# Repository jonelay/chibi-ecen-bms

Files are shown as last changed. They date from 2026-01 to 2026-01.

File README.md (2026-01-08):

# Chibi-ECEN-BMS: 7S Lithium-Ion Battery Management System

A 7-cell lithium-ion battery management system designed as a student project for EMEN 5830 (Fundamentals of Systems Engineering) at the University of Colorado Boulder in 2015.




<p align="center">
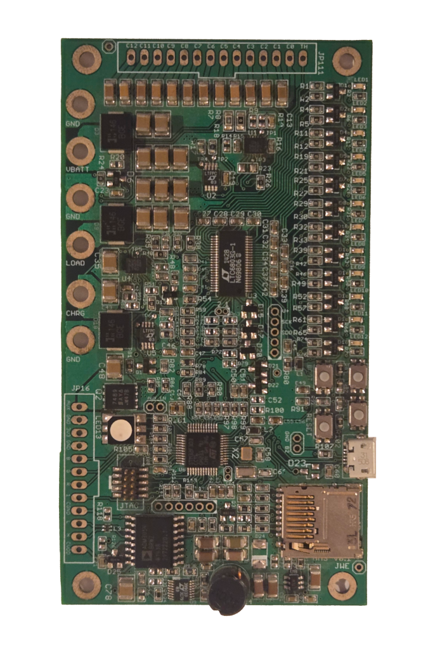
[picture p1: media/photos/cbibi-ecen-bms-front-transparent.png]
BMS PCB - Front
  
  &nbsp;&nbsp;&nbsp;
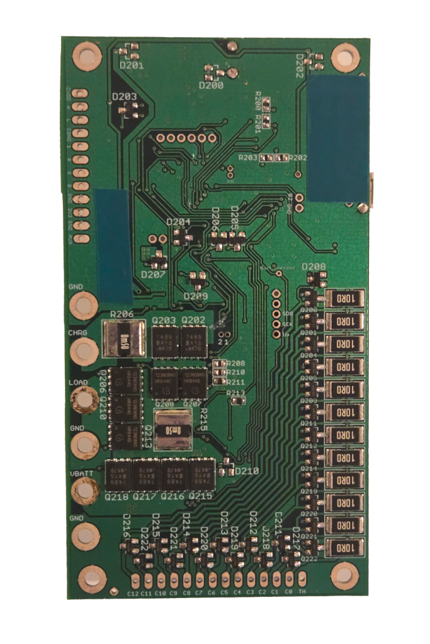
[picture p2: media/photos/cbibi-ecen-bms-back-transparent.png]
BMS PCB - Back
  
</p>

## Overview

This BMS was designed for an electric-assist recumbent tricycle with a focus on battery monitoring, safety, and data logging. The design used the ChibiOS operating system, and includes CAN bus communication, microSD data logging, and comprehensive fault detection.

⚠️ **Educational Prototype** - This was a graduate student learning project from 2015 focused on PCB layout techniques for power electronics. While the design is complete and boards were fabricated, this should be considered a learning exercise rather than a production-ready design. Firmware development was not released as part of the project.

## Key Features

- **7S Lithium-Ion Battery Monitoring** - LT6803-based cell voltage monitoring
- **STM32F303 Microcontroller** - ARM Cortex-M4 with floating-point unit
- **Safety Features** - Overcurrent, overvoltage, undervoltage, and thermal protection
- **CAN Bus Interface** - ADM3054 isolated CAN transceiver for vehicle communication
- **Data Logging** - microSD card storage for voltage, current, temperature data
- **Power Management** - LT3990 buck-boost converter for auxiliary power
- **Debug Interface** - JTAG programming and debugging support
- **User Feedback** - RGB status LED, two buttons for user input

## Technical Specifications

- **Battery Configuration**: 7S (7 cells in series)
- **Cell Chemistry**: 18650 Lithium-Ion (Samsung ICR18650-30B, 3000mAh)
- **Voltage Range**: 19.6V - 29.4V (2.8V - 4.2V per cell)
- **Microcontroller**: STM32F303CBT6 (ARM Cortex-M4, 48MHz, 128KB Flash)
- **Battery Monitor**: LT6803-1 (multicell battery stack monitor)
- **Communication**: CAN 2.0B, USB 2.0 (micro-B connector)
- **Data Logging**: microSD card (SPI interface)
- **PCB**: 4-layer board, approximately 100mm x 75mm

See [docs/specifications.md](docs/specifications.md) for complete specifications.

## Systems Engineering Process

This project followed a rigorous systems engineering methodology as taught in EMEN 5830:

1. **Requirements Development** - Stakeholder needs analysis, system requirements derivation
2. **Concept of Operations** - Use cases, operational scenarios, system interactions
3. **Functional Analysis** - 21 iterations of Functional Flow Block Diagrams (FFDB)
4. **Trade Studies** - Component selection based on cost, performance, availability
5. **Design** - Schematic capture, PCB layout, mechanical integration
6. **Testing** - Comprehensive test procedures and validation

The [analysis/](analysis/) directory contains the complete systems engineering documentation, including all 21 FFDB iterations showing the evolution of the design through failure mode analysis.

## Hardware Versions

### Version 1 (v01) - Manufactured & Tested
Version 1 was designed in February 2015, manufactured in March 2015, and tested as part of the course project. Complete gerber files, BOM, and test documentation are included.

- **Status**: Manufactured, assembled, and tested
- **Manufacturing Files**: Complete gerbers available in `hardware/bms-v01/gerbers/`
- **Documentation**: Full schematic, layout, BOM, and test results included

### Version 2 (v02) - Design Iteration
Version 2 was a design iteration that incorporated lessons learned from v01 testing, including corrections to the 8MHz crystal package and expanded AUX power traces. This version was never manufactured and the design files remain in the Eagle source directory.

## Repository Structure

```
chibi-ecen-bms/
├── hardware/              # Manufacturing-ready files (PDFs, gerbers, BOM)
│   └── bms-v01/          # Version 1 (manufactured)
├── design-source/         # Native design files
│   ├── eagle/            # Eagle CAD schematics and layouts
│   ├── cubemx/           # STM32 configuration files
│   └── mechanical/       # SolidWorks models and renders
├── docs/                  # Documentation
├── analysis/              # Systems engineering analysis
│   ├── requirements/     # Requirements documentation
│   ├── failure-analysis/ # FFDB diagrams (21 iterations)
│   ├── calculations/     # Battery and system calculations
│   ├── trade-studies/    # Component selection analysis
│   └── diagrams/         # System block diagrams
├── datasheets/           # Key component datasheets
├── media/                # Photos, renders, and presentation
└── testing/              # Test procedures and results
```

## Getting Started

### Manufacturing

To manufacture this board:

1. Review the [schematic](hardware/bms-v01/bms_v01_schematic.pdf) and [layout](hardware/bms-v01/bms_v01_layout.pdf)
2. Order PCBs using the [gerber files](hardware/bms-v01/gerbers/)
3. Order components from the [BOM](hardware/bms-v01/bms_v01_assembly_bom.csv)
4. Refer to the [test procedure](testing/test-procedure.pdf) for validation

### Modifying the Design

The source Eagle CAD files are in [design-source/eagle/](design-source/eagle/). The STM32 peripheral configuration can be modified using STM32CubeMX with the [.ioc file](design-source/cubemx/bms_v01.ioc).

## Documentation

- **[Specifications](docs/specifications.md)** - System requirements and performance specs
- **[Pinout](docs/pinout.md)** - Connector pinouts and signal definitions
- **[Hardware README](hardware/README.md)** - Manufacturing file details

## Known Issues

Version 1 has two known issues that were addressed in the v02 design:

1. **8MHz Crystal Package** - Incorrect footprint requires rework or substitution
2. **AUX Power Trace** - Undersized trace for auxiliary power distribution

Workarounds: The crystal issue can be resolved by hand-soldering the correct package or using an adapter. The power trace issue can be addressed by adding solder to thicken the trace or adding a parallel wire jumper.

## License

This project is released under the MIT License. See [LICENSE](LICENSE) for details.

Copyright (c) 2015 Jone Lay

You are free to use, modify, and distribute this design for any purpose, with attribution.

## Open Source Hardware

This project is open source hardware. The design files, manufacturing files, and documentation are freely available for educational and non-commercial use.

## Disclaimer

*This project is shared for educational purposes and as a portfolio piece. It was a graduate student project from 2015. While care was taken in the design and the hardware was successfully manufactured and tested, this is not a production-ready design. Use at your own risk. Battery management systems must be designed with extreme care for safety - this design is presented for educational purposes only.

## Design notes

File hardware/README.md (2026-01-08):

# Hardware Files

This directory contains manufacturing-ready files for the Chibi-ECEN-BMS hardware versions.

## Contents

### [bms-v01/](bms-v01/) - Version 1 (Manufactured & Tested)
Complete manufacturing files for Version 1, which was designed in February 2015, manufactured in March 2015, and successfully tested.

**Status**: ✓ Manufactured, ✓ Assembled, ✓ Tested

**Files**:
- `bms_v01_schematic.pdf` - 3-page schematic (battery monitoring, microcontroller, interfaces)
- `bms_v01_layout.pdf` - PCB layout (4-layer board, ~100mm x 75mm)
- `bms_v01_assembly_bom.csv` - Bill of materials with part numbers
- `gerbers/` - Complete gerber files for PCB manufacturing

**Manufacturing Specifications**:
- 4-layer PCB
- Dimensions: ~100mm x 75mm
- Thickness: 1.6mm
- Min trace/space: 6/6 mil
- Min drill: 0.3mm
- Finish: HASL or ENIG
- Solder mask: Green
- Silkscreen: White

## Manufacturing Information

### Hand Assembly

The v0.1 prototype boards were hand-assembled to save on cost and schedule.

**Assembly Considerations**:
- LT6803 is QFN package - requires good soldering skills or reflow oven
- STM32F303 is LQFP48 - manageable with fine-tip iron
- Most passives are 0603 size - tweezers and magnification helpful
- Stencil recommended for solder paste application

**Tools Needed**:
- Soldering iron with fine tip (Hakko FX-888D or similar)
- Hot air station (for QFN packages) or reflow oven
- Tweezers, flux, solder paste
- Multimeter for testing
- Oscilloscope for verification (recommended)

## Testing

After assembly, follow the test procedure in [../testing/test-procedure.pdf](../testing/test-procedure.pdf).

**Basic Tests**:
1. Visual inspection - Check for shorts, proper component placement
2. Power-on test - Verify 3.3V and 5V rails before connecting battery
3. Microcontroller test - Program and verify LED blink
4. LT6803 test - Verify cell voltage readings
5. CAN bus test - Verify communication with test device
6. microSD test - Verify file read/write

**Safety Warning**:
- Do not connect battery until power rails are verified correct
- Use current-limited power supply for initial testing
- Start with low voltage (e.g., 3S pack) before full 7S pack
- Monitor for smoke, heating, or unusual behavior

## Design Files

Native Eagle CAD design files are located in [../design-source/eagle/](../design-source/eagle/).

**Files**:
- `bms_v01.sch`, `bms_v01.brd` - Version 1 Eagle files
- `bms_v02.sch`, `bms_v02.brd` - Version 2 Eagle files

**Eagle Version**: Designed with Eagle 6.x or 7.x

## License

Hardware design files are released under the MIT License. See [../LICENSE](../LICENSE) for details.

---

**Disclaimer**: This is a student project from 2015. While care was taken in design and the hardware was successfully tested, use at your own risk. Battery management systems require careful design for safety.

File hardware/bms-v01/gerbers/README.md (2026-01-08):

# Gerber Files - BMS v01

This directory contains the complete set of Gerber files for manufacturing the Chibi-ECEN-BMS Version 1 PCB.

## File List

### Copper Layers
- `bms_v01.L1` - Top copper layer (signal + power)
- `bms_v01.L2` - Inner layer 1 (ground plane)
- `bms_v01.L3` - Inner layer 2 (power plane)
- `bms_v01.L4` - Bottom copper layer (signal + power)

### Solder Mask
- `bms_v01.smb` - Bottom solder mask
- `bms_v01.smt` - Top solder mask

### Silkscreen
- `bms_v01.slk` - Silkscreen (component designators, outlines)

### Solder Paste (for stencil)
- `bms_v01.bps` - Bottom paste (if needed)
- `bms_v01.tps` - Top paste (for SMD assembly)

### Drill Files
- `bms_v01.drl` - NC Drill file (Excellon format)
- `bms_v01.drd` - Drill drawing (documentation)
- `bms_v01.dri` - Drill rack information

### Mechanical
- `bms_v01.oln` - Board outline
- `bms_v01.gpi` - Gerber info file

### Additional Files
- `4LPlus-Sunstone.cam` - CAM job definition for 4-layer boards
- `excellon.cam` - Excellon drill file CAM definition

## PCB Specifications

### Board Parameters
- **Layers**: 4 (2 signal, 2 plane)
- **Dimensions**: ~100mm x 75mm (refer to outline layer)
- **Thickness**: 1.6mm (standard)
- **Material**: FR-4
- **Copper Weight**: 1 oz (35µm) on all layers

### Manufacturing Tolerances
- **Min Trace Width**: 6 mil (0.15mm)
- **Min Trace Spacing**: 6 mil (0.15mm)
- **Min Drill Size**: 0.3mm (12 mil)
- **Min Annular Ring**: 4 mil (0.1mm)

### Finish Options
- **HASL** (Hot Air Solder Leveling) - Standard, low cost
- **ENIG** (Electroless Nickel Immersion Gold) - Preferred for fine-pitch components, flat surface

### Solder Mask
- **Color**: Green (standard) or your choice
- **Type**: LPI (Liquid Photo-Imageable)
- **Clearance**: Standard (typically 3 mil from copper)

### Silkscreen
- **Color**: White (standard)
- **Placement**: Top side only
- **Min Text Size**: 40 mil (1mm) recommended for readability

## Layer Stack-up

```
┌─────────────────────┐
│ Top Solder Mask     │
├─────────────────────┤
│ L1 - Top Copper     │ ← Signal traces, SMD pads
│   (1 oz / 35µm)     │
├─────────────────────┤
│ Prepreg             │
├─────────────────────┤
│ L2 - Ground Plane   │ ← Solid ground plane
│   (1 oz / 35µm)     │
├─────────────────────┤
│ Core                │
├─────────────────────┤
│ L3 - Power Plane    │ ← +3.3V, +5V, Battery+ planes
│   (1 oz / 35µm)     │
├─────────────────────┤
│ Prepreg             │
├─────────────────────┤
│ L4 - Bottom Copper  │ ← Signal traces, SMD pads
│   (1 oz / 35µm)     │
├─────────────────────┤
│ Bottom Solder Mask  │
└─────────────────────┘

Total thickness: 1.6mm
```

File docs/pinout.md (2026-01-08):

# BMS Connector Pinouts

This document describes the external connector pinouts for the Chibi-ECEN-BMS. Refer to the [schematic](../hardware/bms-v01/bms_v01_schematic.pdf) for complete signal details.

## Main Battery Connector

**Connector Type**: Screw terminal or wire-to-board

| Pin | Signal | Description |
|-----|---|---|
| 1 | BATT- | Battery negative (cell 1 negative) |
| 2 | CELL1+ | Cell 1 positive / Cell 2 negative |
| 3 | CELL2+ | Cell 2 positive / Cell 3 negative |
| 4 | CELL3+ | Cell 3 positive / Cell 4 negative |
| 5 | CELL4+ | Cell 4 positive / Cell 5 negative |
| 6 | CELL5+ | Cell 5 positive / Cell 6 negative |
| 7 | CELL6+ | Cell 6 positive / Cell 7 negative |
| 8 | BATT+ | Battery positive (cell 7 positive) |

**Voltage Levels**: 19.6V - 29.4V (total pack voltage)

**Notes**:
- Each cell voltage is measured differentially by the LT6803
- RC filtering on each cell input for noise immunity
- Do not reverse polarity - no reverse polarity protection

## Charge Connector

| Pin | Signal | Description |
|-----|---|---|
| 1 | CHRG+ | Charger positive output |
| 2 | CHRG- | Charger negative (return to pack negative) |
| 3 | CHRG_SENSE | Charge current sense (optional) |
| 4 | CHRG_EN | Charge enable signal (output from BMS) |

**Voltage Levels**:
- CHRG+/CHRG-: 19.6V - 29.4V (matches pack voltage)
- CHRG_EN: 3.3V logic level (active high)
- CHRG_SENSE: 0-3.3V analog

**Notes**:
- CHRG_EN controls external charge FET or relay
- CHRG_SENSE is optional current measurement input
- Charge path must include external FET/relay controlled by CHRG_EN

## Load Connector

| Pin | Signal | Description |
|-----|---|---|
| 1 | LOAD+ | Load positive output |
| 2 | LOAD- | Load negative (return to pack negative) |
| 3 | LOAD_SENSE | Load current sense (optional) |
| 4 | LOAD_EN | Load enable signal (output from BMS) |

**Voltage Levels**:
- LOAD+/LOAD-: 19.6V - 29.4V (matches pack voltage)
- LOAD_EN: 3.3V logic level (active high)
- LOAD_SENSE: 0-3.3V analog

**Notes**:
- LOAD_EN controls external discharge FET or relay
- LOAD_SENSE is optional current measurement input
- Load path must include external FET/relay controlled by LOAD_EN

## CAN Bus Connector

**Connector Type**: Screw terminal or pin header

| Pin | Signal | Description |
|-----|---|---|
| 1 | CAN_H | CAN High |
| 2 | CAN_L | CAN Low |
| 3 | CAN_GND | CAN Ground (isolated) |
| 4 | CAN_PWR | CAN Power (5V, optional) |

**Voltage Levels**:
- CAN_H/CAN_L: CAN 2.0B differential signaling (recessive ~2.5V, dominant 3.5V/1.5V)
- CAN_PWR: 5V output, max 100mA

**Notes**:
- CAN transceiver is isolated (ADM3054)
- 120Ω termination resistor can be enabled via jumper or software
- Follow CAN bus wiring guidelines (twisted pair, proper termination)
- Maximum cable length depends on bit rate (40m @ 1Mbps, 1000m @ 50kbps)

## USB Connector

**Connector Type**: Micro-B USB receptacle

| Pin | Signal | Description |
|-----|---|---|
| 1 | VBUS | USB 5V power input |
| 2 | D- | USB Data negative |
| 3 | D+ | USB Data positive |
| 4 | ID | USB ID (not connected) |
| 5 | GND | USB Ground |

**Notes**:
- USB 2.0 Full Speed (12 Mbps)
- Appears as virtual COM port (CDC class)
- Can be powered from USB or battery (diode-OR)
- USB shield connected to GND through ferrite bead

## JTAG/SWD Debug Connector

**Connector Type**: 2x5 pin 0.05" (1.27mm) pitch header (ARM Cortex standard)

| Pin | Signal | Direction | Description |
|-----|---|---|---|
| 1 | VTREF | Input | Target reference voltage (3.3V) |
| 2 | SWDIO/TMS | I/O | Serial Wire Debug I/O / JTAG TMS |
| 3 | GND | - | Ground |
| 4 | SWCLK/TCK | Input | Serial Wire Clock / JTAG Clock |
| 5 | GND | - | Ground |
| 6 | SWO/TDO | Output | Serial Wire Output / JTAG Data Out |
| 7 | KEY | - | Key (no pin) |
| 8 | TDI | Input | JTAG Data In (SWD mode: not used) |
| 9 | GND | - | Ground |
| 10 | NRST | I/O | Reset (active low, open-drain) |

**Notes**:
- Compatible with ST-Link, J-Link, and other ARM debuggers
- SWD mode is preferred (only requires SWDIO, SWCLK, GND, VTREF, NRST)
- JTAG mode uses all signals for full debug capability
- Pull-up resistors on SWDIO, SWCLK, NRST

## User Interface

### Status LED

**Type**: Common-cathode RGB LED

| Pin | Signal | Description |
|-----|---|---|
| 1 | LED_R | Red channel (active high, current-limited) |
| 2 | LED_G | Green channel (active high, current-limited) |
| 3 | LED_B | Blue channel (active high, current-limited) |
| 4 | GND | Common cathode |

**Color Codes** (typical firmware implementation):
- **Green**: Normal operation
- **Blue**: Charging
- **Red**: Fault condition
- **Yellow** (Red+Green): Warning
- **Cyan** (Blue+Green): Discharging
- **Magenta** (Red+Blue): Initialization/bootloader
- **White** (all on): Test mode
- **Off**: Sleep/standby

### Buttons

| Button | Pin | Function |
|---|-----|---|
| BUTTON1 | PB10 | User button 1 (pulled high, active low) |
| BUTTON2 | PB11 | User button 2 (pulled high, active low) |

**Notes**:
- Debounced in firmware
- Can be used for manual fault reset, mode selection, etc.
- Exact function depends on firmware implementation

## STM32 Pin Assignments

### SPI1 - LT6803 Battery Monitor
| STM32 Pin | Signal | Function |
|---|---|---|
| PA5 | SPI1_SCK | Serial clock |
| PA6 | SPI1_MISO | Master in, slave out |
| PA7 | SPI1_MOSI | Master out, slave in |
| PA4 | SPI1_CS | Chip select (GPIO) |

### SPI2 - microSD Card
| STM32 Pin | Signal | Function |
|---|---|---|
| PB13 | SPI2_SCK | Serial clock |
| PB14 | SPI2_MISO | Master in, slave out |
| PB15 | SPI2_MOSI | Master out, slave in |
| PB12 | SPI2_CS | Chip select (GPIO) |

### CAN Bus
| STM32 Pin | Signal | Function |
|---|---|---|
| PA11 | CAN_RX | CAN receive |
| PA12 | CAN_TX | CAN transmit |

### USB
| STM32 Pin | Signal | Function |
|---|---|---|
| PA11 | USB_DM | USB D- (shared with CAN_RX) |
| PA12 | USB_DP | USB D+ (shared with CAN_TX) |

**Note**: PA11/PA12 are shared between CAN and USB. System design should ensure only one is active at a time, or use external multiplexing.

### ADC Inputs
| STM32 Pin | Signal | Function |
|---|---|---|
| PA0 | BATT_CURRENT | Battery current sense |
| PA1 | CHRG_CURRENT | Charge current sense |
| PA2 | CHRG_SENSE | Charge voltage sense |
| PA3 | LOAD_SENSE | Load voltage sense |
| Internal | PCB_TEMP | On-chip temperature sensor |
| Internal | VREFINT | Internal voltage reference |

### Digital I/O
| STM32 Pin | Signal | Direction | Function |
|---|---|---|---|
| PB0 | CHRG_EN | Output | Charge enable (active high) |
| PB1 | LOAD_EN | Output | Load enable (active high) |
| PB2 | CHRG_FLT | Input | Charge fault input (optional) |
| PB3 | LOAD_FLT | Input | Load fault input (optional) |
| PB4 | CAN_SHDN | Output | CAN shutdown control |
| PB5 | 5V_SHDN | Output | 5V power shutdown |
| PB6 | AUX_EN | Output | Auxiliary power enable |
| PB8 | CD | Input | microSD card detect |
| PB10 | BUTTON1 | Input | User button 1 |
| PB11 | BUTTON2 | Input | User button 2 |

### Oscillators
| STM32 Pin | Signal | Function |
|---|---|---|
| PF0 | OSC_IN | 8MHz external crystal input |
| PF1 | OSC_OUT | 8MHz external crystal output |
| PC14 | OSC32_IN | 32.768kHz RTC crystal input |
| PC15 | OSC32_OUT | 32.768kHz RTC crystal output |

## Power Pins Summary

| Pin | Net | Description |
|-----|-----|---|
| VDD (multiple) | +3V3 | 3.3V main power |
| VSS (multiple) | GND | Ground |
| VDDA | VDDA | 3.3V analog power |
| VSSA | GND | Analog ground |
| VBAT | RTC_VBAT | RTC backup battery (optional) |
| VREF+ | VDDA | ADC positive reference |
| VREF- | GND | ADC negative reference |

---

For complete pin assignments and electrical characteristics, refer to the [STM32F303 datasheet](../datasheets/STM32F303-microcontroller.pdf) and the [schematic](../hardware/bms-v01/bms_v01_schematic.pdf).

For signals CSV data, see [../analysis/requirements/bms_signals.ods](../analysis/requirements/) (if available).

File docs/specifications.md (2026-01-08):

# BMS Specifications

## System Requirements

### Battery Configuration
- **Cell Count**: 7 cells in series (7S)
- **Cell Type**: 18650 Lithium-Ion
- **Reference Cell**: Samsung ICR18650-30B
- **Cell Capacity**: 3000mAh nominal
- **Cell Voltage Range**: 2.8V - 4.2V per cell
- **Pack Voltage Range**: 19.6V - 29.4V
- **Nominal Pack Voltage**: ~25.9V (3.7V/cell)

### Electrical Specifications

#### Power
- **Operating Voltage**: 19.6V - 29.4V (from battery pack)
- **Auxiliary Power Output**: 3.3V, 5V regulated
- **Quiescent Current**: < 50mA (typical)
- **Standby Current**: < 5mA (sleep mode, if implemented)

#### Current Monitoring
- **Charge Current**: 0 - 7A (target application)
- **Discharge Current**: 0 - 20A (target application)
- **Current Sense Resolution**: 10-bit ADC minimum

#### Voltage Monitoring
- **Cell Voltage Accuracy**: ±5mV (LT6803 specification)
- **Measurement Resolution**: 12-bit (LT6803)
- **Sampling Rate**: Configurable, up to 10Hz for logging

#### Temperature Monitoring
- **On-board Temperature Sensor**: STM32 internal sensor
- **External Temperature Inputs**: Provision for thermistor inputs
- **Temperature Range**: 0°C - 45°C (operating)
- **Storage Temperature**: -20°C - 70°C

### Communication Interfaces

#### CAN Bus
- **Standard**: CAN 2.0B
- **Bit Rate**: Configurable, typically 250kbps or 500kbps
- **Transceiver**: ADM3054 (isolated)
- **Connector**: Screw terminal or pin header
- **Termination**: Software-selectable termination resistor

#### USB
- **Standard**: USB 2.0 Full Speed
- **Connector**: Micro-B USB
- **Purpose**: Debugging, configuration, data download
- **Protocol**: USB CDC (virtual COM port)

#### Debug Interface
- **Standard**: JTAG/SWD
- **Connector**: 2x5 pin 0.05" header (ARM Cortex standard)
- **Supported Tools**: ST-Link, J-Link, OpenOCD-compatible

### Data Logging
- **Storage**: microSD card (SPI interface)
- **Card Support**: SD and SDHC cards
- **File System**: FAT32
- **Logging Rate**: Configurable, 1Hz - 10Hz typical
- **Data Recorded**:
  - Cell voltages (7 channels)
  - Pack current (charge/discharge)
  - Temperature
  - Timestamp
  - Fault conditions

### Safety & Protection

#### Overvoltage Protection
- **Cell Level**: 4.25V per cell (typical threshold)
- **Action**: Disable charging, set fault flag

#### Undervoltage Protection
- **Cell Level**: 2.7V per cell (typical threshold)
- **Action**: Disable discharging, set fault flag

#### Overcurrent Protection
- **Charge Overcurrent**: Configurable threshold
- **Discharge Overcurrent**: Configurable threshold
- **Action**: Disable respective path, set fault flag

#### Over-temperature Protection
- **High Temperature**: 50°C (configurable)
- **Action**: Disable charging/discharging, set fault flag

#### Cell Imbalance Detection
- **Threshold**: Configurable (e.g., 100mV between highest and lowest)
- **Action**: Warning flag, optional balancing (not implemented in v01)

### Mechanical Specifications

#### PCB
- **Size**: Approximately 100mm x 75mm
- **Layers**: 4-layer stackup
- **Thickness**: 1.6mm (standard)
- **Finish**: HASL or ENIG
- **Solder Mask**: Green (standard)
- **Silkscreen**: White

#### Connectors
- **Battery Input**: Screw terminals or wire-to-board connector
- **Charge/Load Outputs**: Screw terminals
- **CAN Bus**: Screw terminal or pin header
- **USB**: Micro-B receptacle
- **JTAG**: 2x5 pin 0.05" header

#### Mounting
- **Mounting Holes**: 4x M3 holes
- **Enclosure**: Designed for Pelican iM2100 case integration

### Environmental Specifications
- **Operating Temperature**: 0°C - 45°C
- **Storage Temperature**: -20°C - 70°C
- **Humidity**: 20% - 80% RH, non-condensing
- **Altitude**: 0 - 2000m (designed for Boulder, CO at ~1655m)

### Firmware Requirements
- **Platform**: STM32F303CBT6
- **Development**: STM32CubeMX, GCC ARM toolchain
- **Real-time OS**: Optional (bare-metal or FreeRTOS)
- **Update Method**: JTAG/SWD or USB bootloader

### Compliance & Standards
**Note**: This is a student project and was not formally certified for compliance.

#### Design References
- **Battery Safety**: Based on UL 2271 principles (not certified)
- **CAN Bus**: CAN 2.0B specification
- **USB**: USB 2.0 specification
- **PCB Design**: IPC-2221 general principles

## Performance Requirements

### Accuracy
- **Voltage Measurement**: ±0.25% (LT6803)
- **Current Measurement**: ±2% (sensor dependent)
- **Temperature Measurement**: ±2°C

### Response Time
- **Fault Detection**: < 100ms
- **Fault Response**: < 10ms (disable output)
- **Data Logging**: 1Hz - 10Hz configurable

### Reliability
- **Target MTBF**: Not formally calculated (student project)
- **Design Life**: 5+ years (component selection basis)
- **Cycle Life**: Follows battery cell specifications

## System Interfaces

### Input Interfaces
1. **Battery Pack** - 7S lithium-ion pack
2. **Charge Input** - Battery charger connection
3. **CAN Bus** - Vehicle network communication
4. **USB** - Configuration and data interface
5. **JTAG/SWD** - Programming and debugging

### Output Interfaces
1. **Load Output** - To motor controller or load
2. **CAN Bus** - Vehicle network communication
3. **Status LED** - RGB LED for user feedback
4. **Fault Signals** - Digital outputs for charge/load enable

## Future Enhancements
*(Not implemented in v01, considerations for v02+)*

- Active cell balancing
- Wireless communication (Bluetooth/WiFi)
- Enhanced diagnostics and state-of-health estimation
- Improved thermal management with active cooling
- CAN-based bootloader for remote firmware updates

---

For detailed requirements traceability, see [../analysis/requirements/requirements.csv](../analysis/requirements/requirements.csv).

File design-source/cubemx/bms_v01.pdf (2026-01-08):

## bms_pins Project

# 1. Description

## 1.1. Project

Project Name | bms_pins
Generated with: | STM32CubeMX 4.4.0
Date | 02/10/2015

## 1.2. MCU

MCU Serie | STM32F3
MCU Line | STM32F303
MCU name | STM32F303CCTx
MCU Package | LQFP48
MCU Pin number | 48

## 1.3. Caution

## The report was generated although the configuration was in a modified state. It may be not accurate

# 2. Pinout Configuration

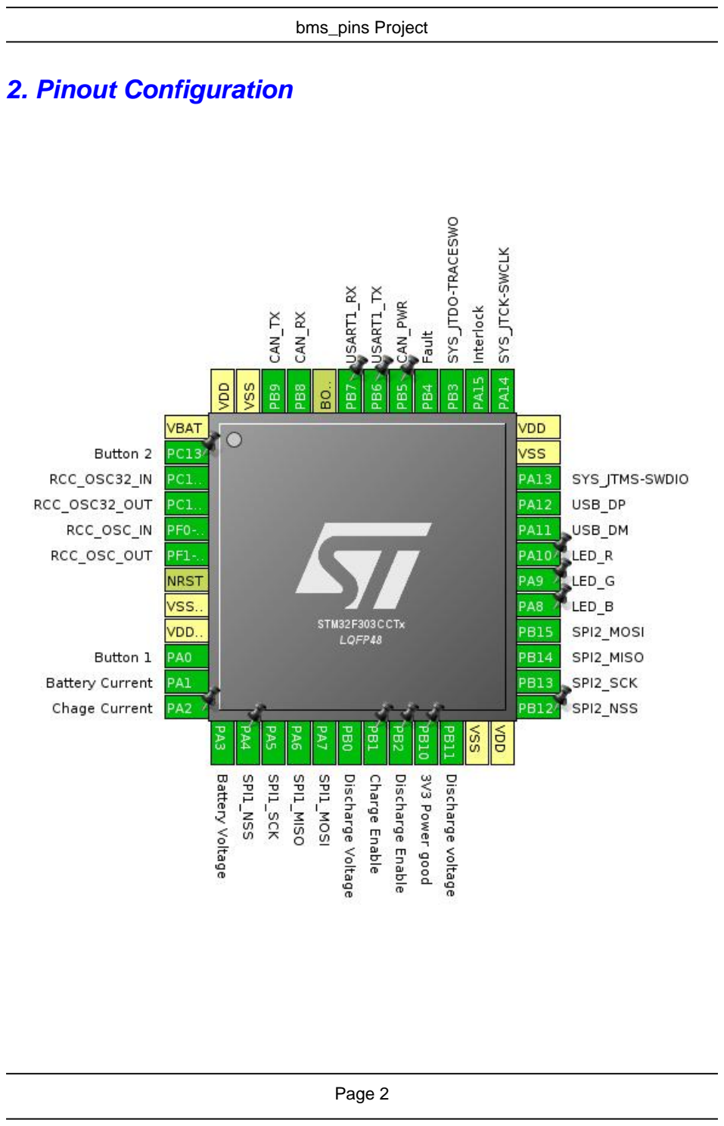
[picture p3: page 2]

# 3. IPs and Middlewares Configuration

IP | Mode | Fonction | Pin

ADC1

IN3:
IN3 Single-ended
| | ADC1_IN3 | PA2
| Temperature Sensor Channel | N/A | N/A
| Vbat Channel | N/A | N/A
CAN | Mode | CAN_RX | PB8
| | CAN_TX | PB9
COMP1 | Input [+]: INP | COMP1_INP | PA1
COMP2 | Input [+]: INP | COMP2_INP | PA3
COMP4 | Input [+]: INP | COMP4_INP | PB0
COMP6 | Input [+]: INP | COMP6_INP | PB11
CRC | Activated | N/A | N/A
IWDG | Activated | N/A | N/A

RCC

High Speed Clock (HSE):
Crystal/Ceramic Resonator
RCC_OSC_IN | PF0-OSC_IN
RCC_OSC_OUT | PF1-OSC_OUT
Low Speed Clock (LSE) :
Crystal/Ceramic Resonator
RCC_OSC32_IN | PC14-OSC32_IN
RCC_OSC32_OUT | PC15-OSC32_OUT

RTC

Alarm A:
Internal Alarm A
N/A | N/A

Alarm B:
Internal Alarm B
N/A | N/A

WakeUp:
Routed to OUT
RTC_OUT_ALARM | PC13

SPI1

Mode:
Full-Duplex Master
| SPI1_MISO | PA6
| SPI1_MOSI | PA7
| SPI1_SCK | PA5
Hardware NSS Signal | SPI1_NSS | PA4

SPI2

Mode:
Full-Duplex Master
| SPI2_MISO | PB14
| SPI2_MOSI | PB15
| SPI2_SCK | PB13
Hardware NSS Signal | SPI2_NSS | PB12

SYS

Debug:
JTAG (5 pins)
| SYS_JTCK-SWCLK | PA14
| SYS_JTDI | PA15
| SYS_JTDO-TRACESWO | PB3
| SYS_JTMS-SWDIO | PA13
| SYS_NJTRST | PB4
System Wake-Up 1 | SYS_WKUP1 | PA0
Mode: | USART1_RX | PB7

IP | Mode | Fonction | Pin
USART1 | Asynchronous
USART1_TX | PB6
USB | Device (FS) | USB_DM | PA11
| | USB_DP | PA12
WWDG | Activated | N/A | N/A

# 4. Pins Configuration

Pin | Pos Function(s) | | Label
PC13 | 2 | RTC_OUT_ALARM | Button 2
PC14-OSC32_IN | 3 | RCC_OSC32_IN
PC15-OSC32_OUT | 4 | RCC_OSC32_OUT
PF0-OSC_IN | 5 | RCC_OSC_IN
PF1-OSC_OUT | 6 | RCC_OSC_OUT
PA0 | 10 | SYS_WKUP1 | Button 1
PA1 | 11 | COMP1_INP | Battery Current
PA2 | 12 | ADC1_IN3 | Chage Current
PA3 | 13 | COMP2_INP | Battery Voltage
PA4 | 14 | SPI1_NSS
PA5 | 15 | SPI1_SCK
PA6 | 16 | SPI1_MISO
PA7 | 17 | SPI1_MOSI
PB0 | 18 | COMP4_INP | Discharge Voltage
PB1 * | 19 | GPIO_Output | Charge Enable
PB2 * | 20 | GPIO_Output | Discharge Enable
PB10 * | 21 | GPIO_Input | 3V3 Power good
PB11 | 22 | COMP6_INP | Discharge voltage
PB12 | 25 | SPI2_NSS
PB13 | 26 | SPI2_SCK
PB14 | 27 | SPI2_MISO
PB15 | 28 | SPI2_MOSI
PA8 * | 29 | GPIO_Output | LED_B
PA9 * | 30 | GPIO_Output | LED_G
PA10 * | 31 | GPIO_Output | LED_R
PA11 | 32 | USB_DM
PA12 | 33 | USB_DP
PA13 | 34 | SYS_JTMS-SWDIO
PA14 | 37 | SYS_JTCK-SWCLK
PA15 | 38 | SYS_JTDI | Interlock
PB3 | 39 | SYS_JTDO-TRACESWO
PB4 | 40 | SYS_NJTRST | Fault
PB5 * | 41 | GPIO_Input | CAN_PWR
PB6 | 42 | USART1_TX
PB7 | 43 | USART1_RX
PB8 | 45 | CAN_RX
PB9 | 46 | CAN_TX

## * The pin is affected with an I/O function

# 5. Power Plugin report

## 5.1. Microcontroller Selection

Serie | STM32F3
Line | STM32F303
MCU | STM32F303CCTx
Datasheet | 023353_Rev8

## 5.2. Parameter Selection

Temperature | 25
Vdd | 3.6

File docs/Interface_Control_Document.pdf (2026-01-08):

E-trike Battery System

Version 0.0.1

Interface Control Document

February 2015

***IN-PROGRESS DRAFT DOCUMENT***

Document version 0.0.1

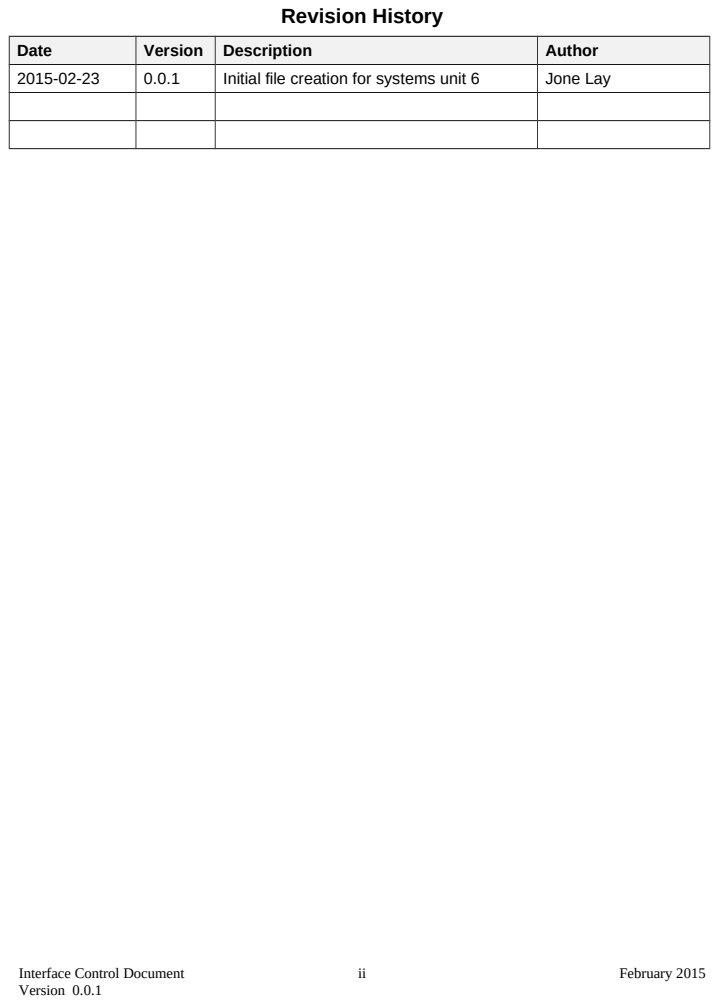
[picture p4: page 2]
Revision History; Date; Version; Description; Author; Initial file creation for systems unit 6; Jone Lay; Interface Control Document; February 2015; Version 0.0.1

Table of Contents

### 1. Introduction | 1

### 1.1. Purpose | 1

### 1.2. Scope | 1

### 1.3. System Identification | 1

### 1.3.1. Battery System | 2

### 1.3.2. Electric Drive system | 2

### 1.3.3. Accessory Electronics System | 2

### 1.3.4. AC Power System | 1

### 1.4. Operational Agreement | 1

### 2. Electrical Interface | 1

### 2.1. Power | 1

### 2.2. Connectors | 1

### 2.3. Interlock | 2

### 3. CANbus Interface | 2

### 3.1. Physical Layer | 2

### 3.2. Base Frame Format | 3

### 3.3. Application Layer | 3

### 3.4. Addressing | 3

### 4. Mechanical Interface | 4

### 4.1. Interface Control | 4

### 4.2. Electrical Interface | 4

### 5. Interface Controls | 5

5

Interface Control Document | iii | February 2015

### 1. Introduction

The battery system is responsible for supplying power to the electric assist trike, supplying 5V of power to auxiliary systems, and recharging from an wall AC power source. A trained user will interact with the battery system to perform each of these functions. A main power disable toggle switch will be prominently accessible from the exterior of the battery system enclosure. An auxiliary power enable push-button switch will also be accessible form the exterior of the enclosure. The battery system will connect to the trike electronics through a cable with a circular connector, and it will connect to auxiliary systems through a separate cable.

### 1.1. Purpose

This Interface Control Document presents the electrical, software, and mechanical interface requirements between the battery system and the electric drive, accessory electronics system, and AC power system. It describes the concept of operations for the interface, defines the electrical operating parameters, defines the communication protocols, and identifies the interconnections between subsystems in the device.

### 1.2. Scope

This Interface Control Document specifies the interfaces between the battery system, the electric drive system, the accessory electronics system, and AC power system. This document provides details on the functional, performance, operational and design requirements for the interface between the battery system, the electric drive system, the accessory electronics system, and AC power system.

### 1.3. System Identification

This Interface Control Document describes the interface between the battery system, the electric drive system, the accessory electronics system, and AC power system.
The battery system includes the lithium-ion cells, the battery-management system PCB, a mechanical enclosure, and an AC charger.
The electric drive system connects electrical power between the battery system and the trike traction motor. It is composed of a motor controller, a motor, a throttle, a torque sensor, a wheel speed sensor, and a pedal speed sensor. The motor controller includes an ARM M4 microcontroller with a CANbus communication interface.
The accessory electronics system powers and controls the trike headlights, taillights, and LED flag. The accessory electronics system receives power from the battery system, and does not interact with the electric drive system.
Interface Control Document | 1 | February 2015

The AC power system is defined as a standard 120VAC power outlet, connected to a 15 Amp circuit breaker.

### 1.3.1. Battery System

The battery system includes the lithium-ion cells, the battery-management system PCB, a mechanical enclosure, and an AC charger.

System | Details
Identification number | 1.0
Title | Battery system
Abbreviation | Batt
Version number | 0.1
Release number | -
Point of Contact | -

### 1.3.2. Electric Drive system

The electric drive system connects electrical power between the battery system and the trike traction motor. It is composed of a motor controller, a motor, a throttle, a torque sensor, a wheel speed sensor, and a pedal speed sensor. The motor controller includes an ARM M4 microcontroller with a CANbus communication interface.

System | Details
Identification number | 2.0
Title | Electric Drive System
Abbreviation | drive

Version number

Release number

Point of Contact

### 1.3.3. Accessory Electronics System

The accessory electronics system powers and controls the trike headlights, taillights, and LED flag. The accessory electronics system receives power from the battery system, and does not interact with the electric drive system.

System | Details
Identification number | 2.0
Title | Electric Drive System
Abbreviation | accessory
Interface Control Document | 2 | February 2015

Version number

Release number

Point of Contact

### 1.3.4. AC Power System

The AC power system is defined as a standard 120VAC power outlet, connected to a 15 Amp circuit breaker.

System | Details
Identification number | 2.0
Title | Electric Drive System
Abbreviation | ac

Version number

Release number

Point of Contact

### 1.4. Operational Agreement

This Interface Control Document provides the specification for interfaces between the battery system, the electric drive system, the accessory electronics system, and AC power system.

### 2. Electrical Interface

The primary functions of the battery system are realized through the electrical interfaces. These interfaces include power, safety, and communication elements.

### 2.1. Power

The battery system has four power ports: the battery pack, the charger, the load, and the auxiliary system. The
The power system operational parameters are as follows
Interface Control Document | 3 | February 2015

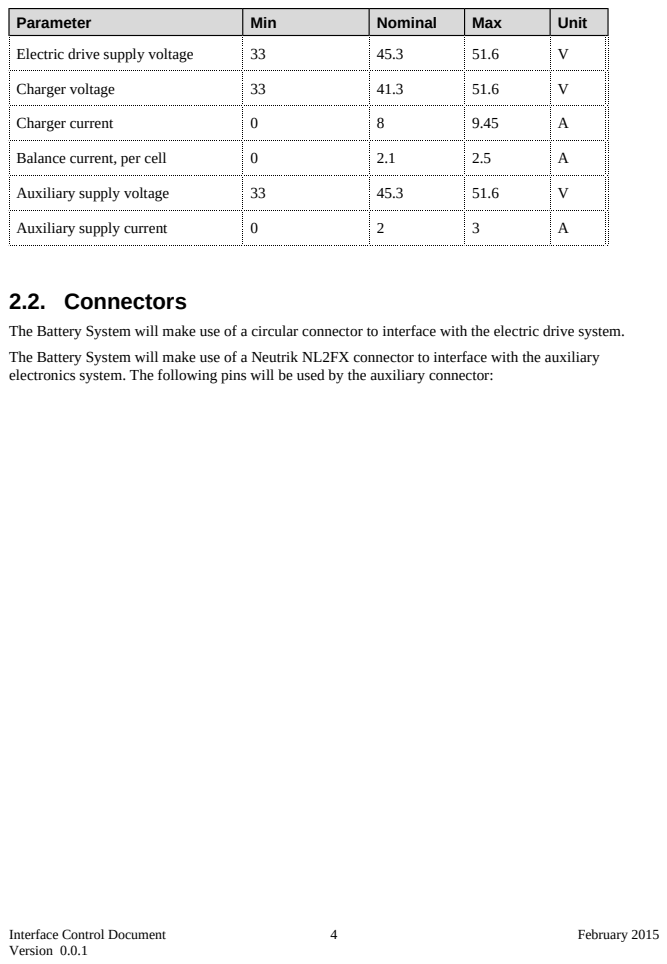
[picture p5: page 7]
Interface Control Document; February 2015

Parameter | Min | Nominal | Max | Unit
Electric drive supply voltage | 33 | 45.3 | 51.6 | V
Charger voltage | 33 | 41.3 | 51.6 | V
Charger current | 0 | 8 | 9.45 | A
Balance current, per cell | 0 | 2.1 | 2.5 | A
Auxiliary supply voltage | 33 | 45.3 | 51.6 | V
Auxiliary supply current | 0 | 2 | 3 | A

2.2. Connectors
The Battery System will make use of a circular connector to interface with the electric drive system.
The Battery System will make use of a Neutrik NL2FX connector to interface with the auxiliary
electronics system. The following pins will be used by the auxiliary connector:

Pin 1: GND
Pin 2: 5V power

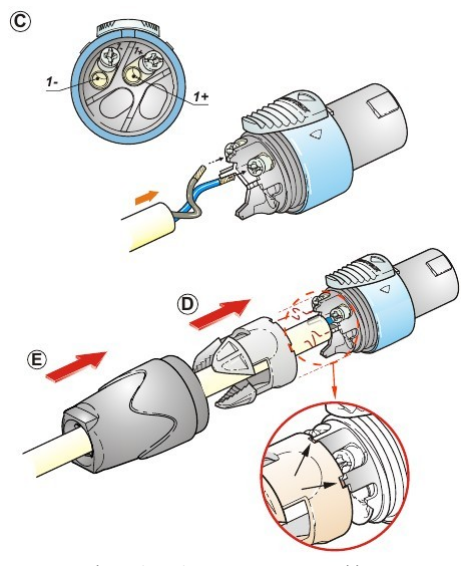
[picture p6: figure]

Interface Control Document | 5 | February 2015

Figure 2: NL2FX connector assembly
Source: NL2FX datasheet

The Battery System will make use of a 3-pin XLR connector to interface with the charger, as part of the AC power system.

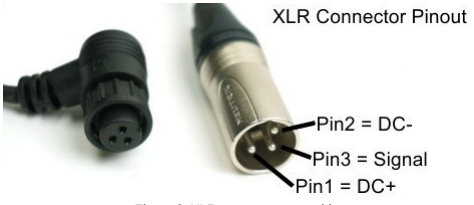
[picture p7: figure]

### 2.3. Logic Power Regulation

The Battery system includes a step-down switching converter to provide regulated 3.3 Volt power to the logic systems. The logic power regulation shall disable itself when any of the following conditions are met:

Parameter | Value | Unit
Under-voltage cut-off hysteresis | 0.035 | V
Under-voltage cut-off threshold | 32.13 | V

### 2.4. Quiescent Power Consumption

The Battery System electronics will meet the following power consumption metrics

Parameter | Value | Unit
Total quiescent discharge power (stop mode) | 1.9 | mW
Voltage divider power loss | 0.02 | mW
Interface Control Document | 6 | February 2015

Figure 3: XLR connector assembly Source: ebikes.ca

### 2.5. Manual Interlock

The Battery System will enter a failsafe mode when the interlock toggle switch is active.

Interface Control Document | 7 | February 2015

Figure 4:
Interlock toggle switch
Source: mcmaster.com

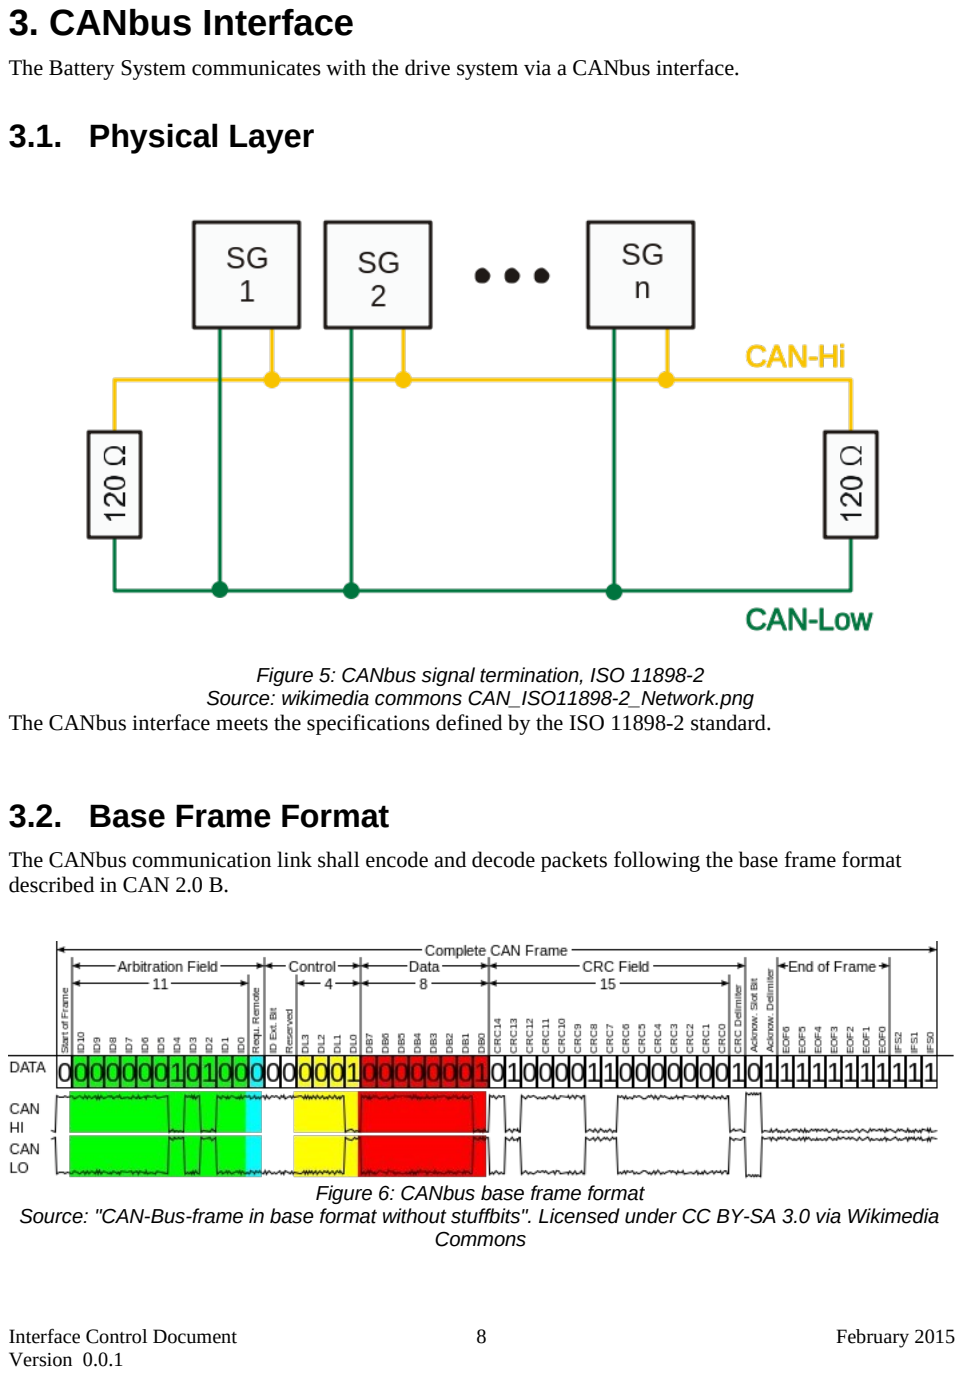
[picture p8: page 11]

### 3. CANbus Interface

The Battery System communicates with the drive system via a CANbus interface.

### 3.1. Physical Layer

The CANbus interface meets the specifications defined by the ISO 11898-2 standard.

### 3.2. Base Frame Format

The CANbus communication link shall encode and decode packets following the base frame format described in CAN 2.0 B.

Interface Control Document | 8 | February 2015

Figure 5: CANbus signal termination, ISO 11898-2 Source: wikimedia commons CAN_ISO11898-2_Network.png

Figure 6: CANbus base frame format Source: "CAN-Bus-frame in base format without stuffbits". Licensed under CC BY-SA 3.0 via Wikimedia Commons

### 3.3. Application Layer

The CANbus interface meets the device and communication profiles listed in the CiA 301 specification.

### 3.4. Addressing

The addressing of devices on the CANbus network will prioritize for electrical safety functions. The BMS PCB shall have priority over the motor controller, and the motor controller shall have priority over the accessory electronics system.

Interface Control Document | 9 | February 2015

### 4. Mechanical Interface

The battery system enclosure mounts onto a cargo rack of the trike. The battery system enclosure is removable for daily charging and storage.

### 4.1. Enclosure Mounting

The battery system mount will be detachable from the trike cargo rack without requiring tools.

### 4.2. Shock and Vibration

The battery system enclosure mount will meet the following shock and vibration specifications.

Interface Control Document | 10 | February 2015

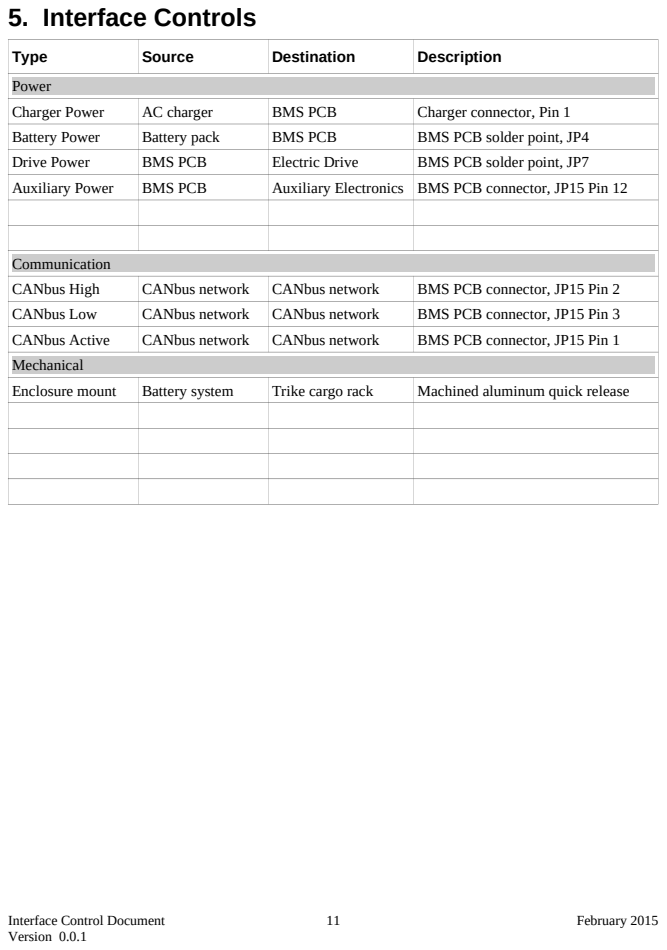
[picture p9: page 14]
5. Interface Controls; Type; Source; Destination; Description; Power; Charger Power; AC charger; BMS PCB; Charger connector, Pin 1; Battery Power; Battery pack; BMS PCB solder point, JP4; Drive Power; Electric Drive; BMS PCB solder point, JP7; Auxiliary Power; Auxiliary Electronics BMS PCB connector, JP15 Pin 12; Communication; CANbus High; CANbus network CANbus network; BMS PCB connector, JP15 Pin 2; CANbus Low; BMS PCB connector, JP15 Pin 3; CANbus Active; BMS PCB connector, JP15 Pin 1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

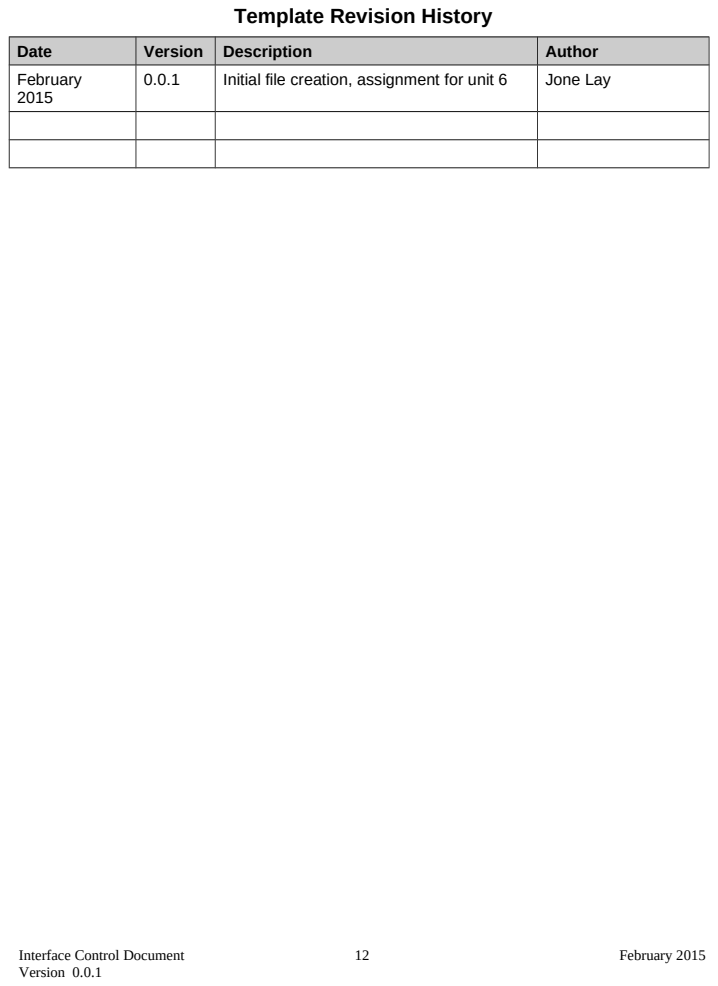
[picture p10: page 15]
Date; Version; Description; Author; February; Initial file creation, assignment for unit 6; Jone Lay; Interface Control Document; February 2015

Template Revision History

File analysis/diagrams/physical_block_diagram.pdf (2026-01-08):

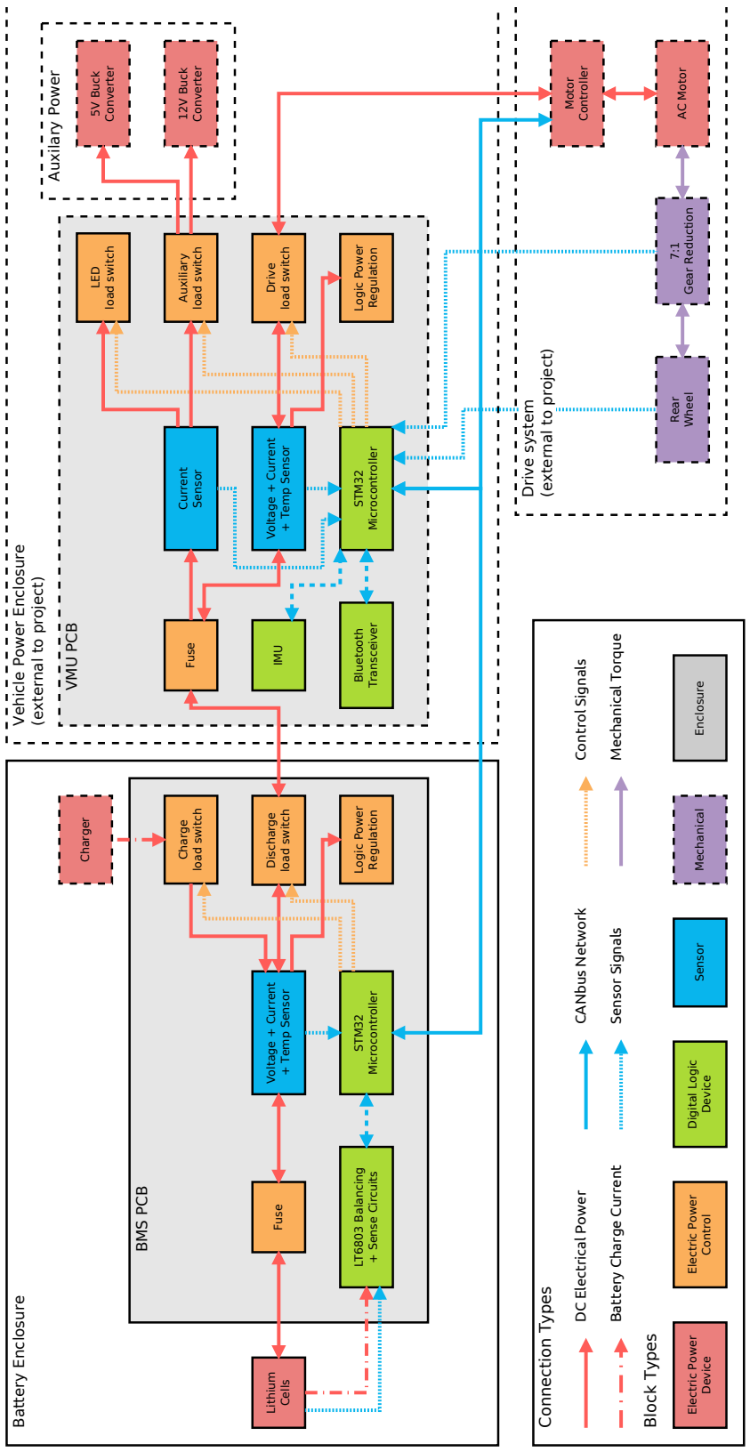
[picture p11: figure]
Motor; Controller; Battery Enclosure; Lithium; Cells; Voltage + Current; + Temp Sensor; Drive; load switch; DC Electrical Power; Battery Charge Current Sensor Signals; Connection Types; Discharge; 12V Buck; Converter; AC Motor Rear Wheel 7:1 Gear Reduction; Mechanical Torque; Block Types; Vehicle Power Enclosure; (external to project); LT6803 Balancing; + Sense Circuits; Charge; Charger; Fuse; STM32; Microcontroller; Auxiliary; Fuse Current Sensor; 5V Buck; LED; Auxilary Power; VMU PCB; BMS PCB; Bluetooth; Transceiver; Electric Power; Device; Control; Digital Logic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

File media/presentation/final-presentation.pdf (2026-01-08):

# Electric Assist Trike Battery System

# JONE LAY

# PRESENTED 2015-04-28

# Battery System Final Presentation Outline

# θProject Overview

# θHardware Review

# θDesign and Assembly

# θTesting Progress

# θProject Reflections

# Project Review Primary Objectives

### The battery system is responsible for:

### θSupplying power to the electric assist trike

### θSupplying 5V of power to auxiliary systems

θRecharging from an wall AC power source.

### The battery system is comprised of:

### θBattery Management System (BMS) Printed Circuit Board (PCB)

### θ84 Lithium Cells

### θMechanical enclosure and heatsink

# Project Review Trike Systems

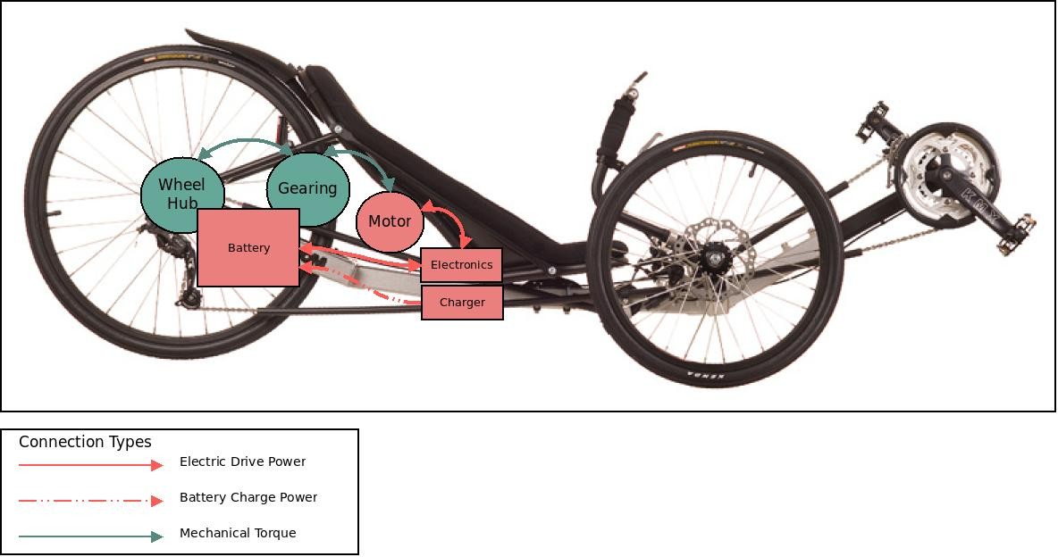
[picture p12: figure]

# Project Review Physical Block Diagram

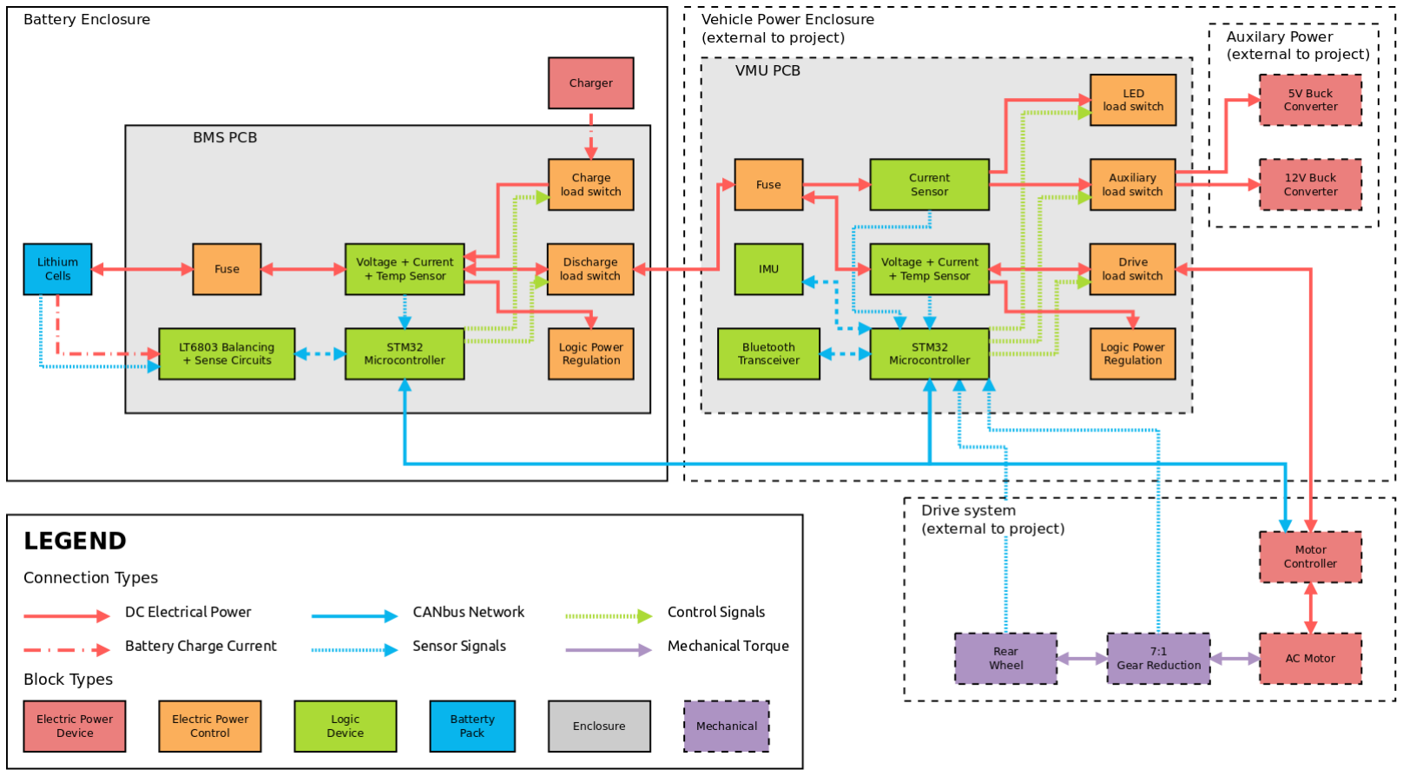
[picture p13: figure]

# Project Review Mechanical Design

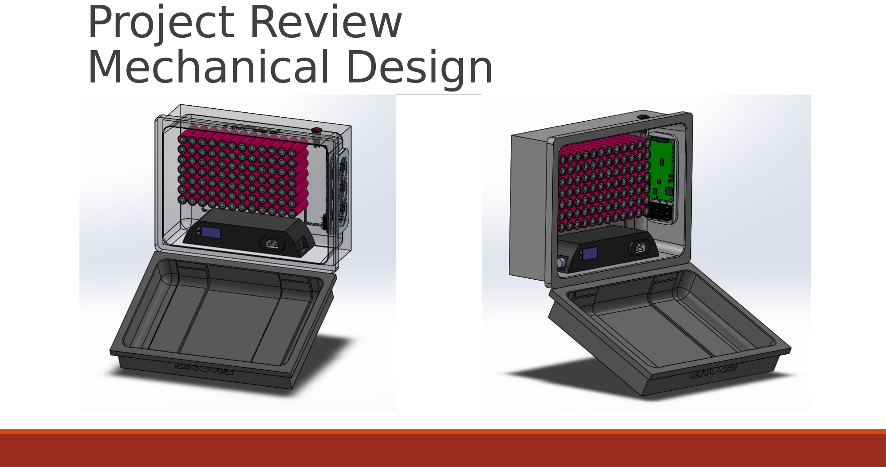
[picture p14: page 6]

# Project Review Mechanical Integration

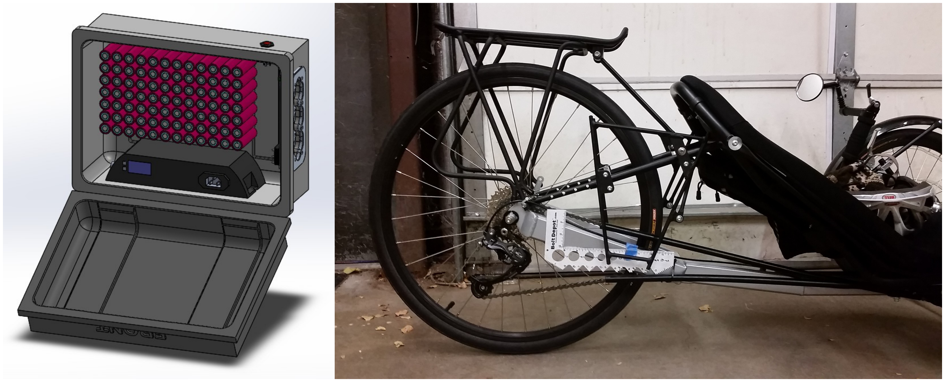
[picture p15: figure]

# Project Review Digital Logic Schematic

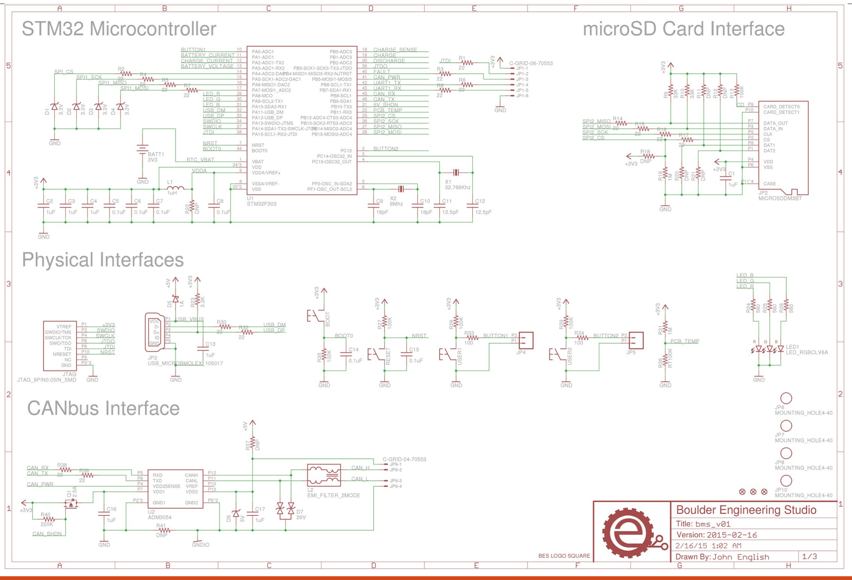
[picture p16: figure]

# Project Review Power Electronics Schematic

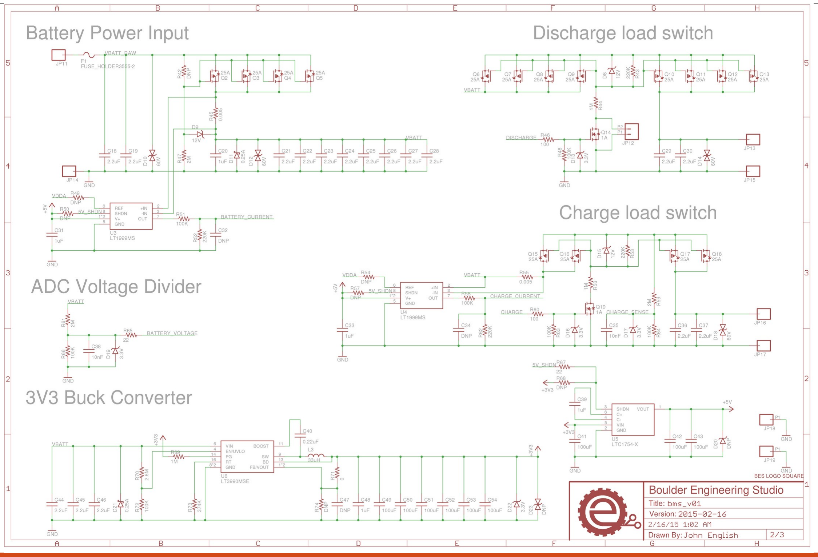
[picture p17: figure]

# Project Review Balancing Schematic

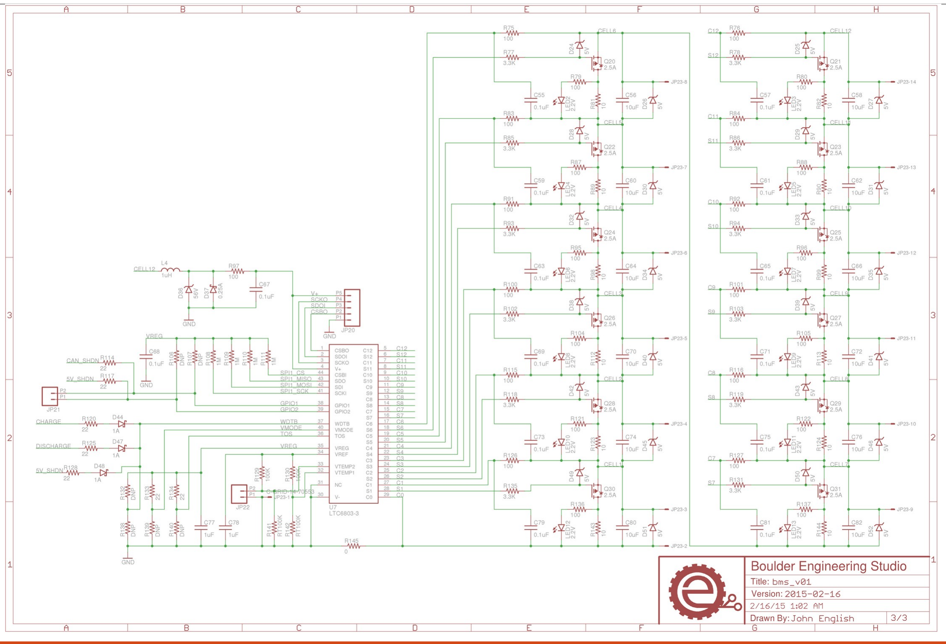
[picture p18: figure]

# Project Review

# BMS PCB Layout

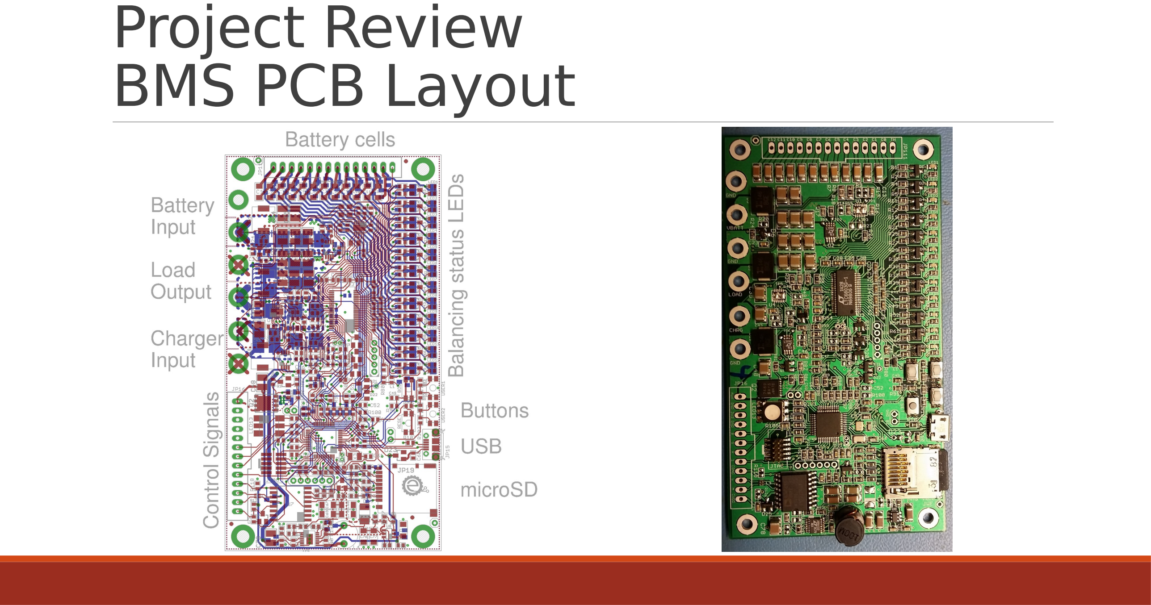
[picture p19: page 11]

# Development and Testing BMS PCB Test Fixture

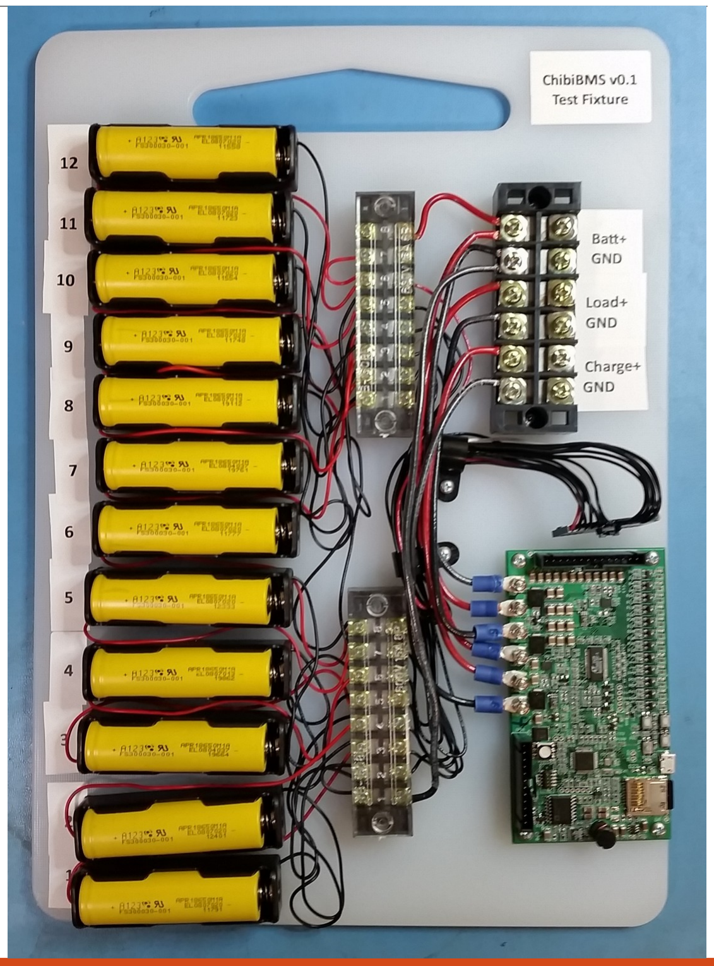
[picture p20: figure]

### θSmall-scale battery pack (12s1p)

### θAssembled with scrap office materials and cutting

### board

θPoor thermal performance (imposes power limitation)

### θWire harness routing

### θProvides rigid mounting for test points

# Development and Testing BMS PCB Test Equipment

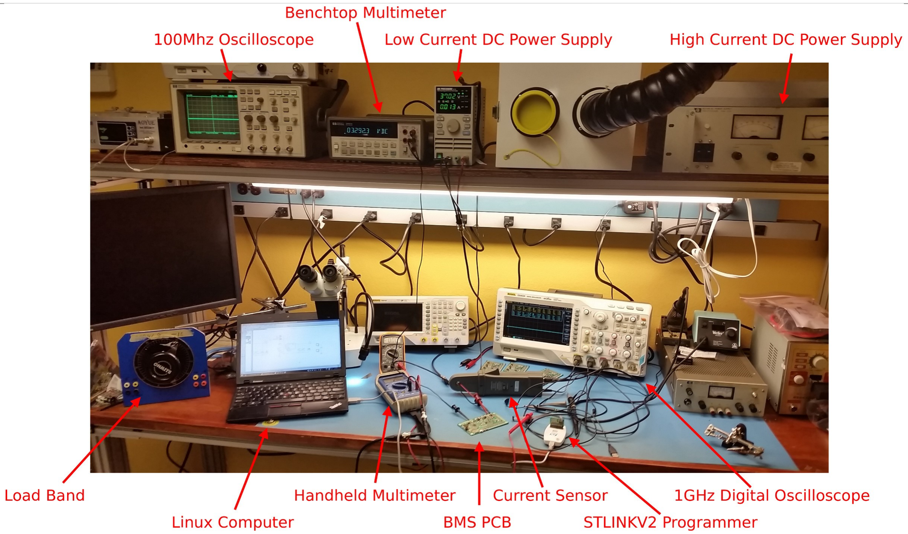
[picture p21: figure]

# Development and Testing Test Progress

θTested Good

θMicrocontroller JTAG, SWD and USB DFU interfaces

θ3.3 & 5V power regulation and undervoltage protection

θAuxiliary power output control

θCell Balancing MOSFET control

θBattery reverse input protection

θVoltage divider analog inputs

θTemperature sensors

θTested Bad

θCharger reverse input protection

θCurrent sense amplifiers at lower currents (<10mA)

θTotal system quiescent current (measure >2mA)

θUntested

θOver-current protection (analog and digital)

θLTC6803 SPI communication

θWatchdog timer

θSD card interface

θCANbus interface

θTemp sensor accuracy at <0⁰C or >60 ⁰ C

θ16Mhz crystal accuracy

θ32.768Khz RTC accuracy

θRTC power consumption

# Conclusion Project Reflections

θEvolution of Scope

θBegan too broadly focused

θUneven attention for subsystems

θTechnical Changes

θPower Distribution: Thicker copper layers or bus bar

θPress-fit PCB connectors for power input

θUpcoming work

θFirmware development

θInductive load testing

θMechanical fabrication and assembly

θTrike testing

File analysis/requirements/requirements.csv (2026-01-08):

Battery System v0.1 Requirements
ID | Title | Requirement statement | Constraint | Type | System or Subsystem | Test Method (I,A,D,T)
Safety Requirements
0.1.1.0 | Safety interlock | The battery system shall disconnect from discharge loads if an interlock switch is engaged | 500uA maximum leakage current | Power | Protection
0.1.1.1 | Reverse polarity battery protection | The BMS shall be tolerant of a reverse polarity voltage on the battery input connector | 100V maximum reverse voltage | Power | Power
0.1.1.2 | Low voltage pack discharge cut-off implementation | The low voltage pack discharge power-path cut-off will be implemented with a P-channel MOSFET load switch circuit | Power-path cut-off circuit design | Power | Power
0.1.1.3 | Over-current pack discharge cut-off implementation | The over-current pack discharge power-path cut-off will be implemented with a P-channel MOSFET load switch circuit | Power-path cut-off circuit design | Power | Power
0.1.1.4 | Over-voltage pack discharge cut-off implementation | The over-voltage pack discharge power-path cut-off will be implemented with a P-channel MOSFET load switch circuit | Power-path cut-off circuit design | Power | Power
0.1.1.5 | Failsafe Iq | The battery system shall dissipate less than a specified quiescent current when in the failsafe state | 500 uAmp | Power | Power
0.1.1.6 | Manual interlock | The BMS shall disable discharge if the manual interlock switch is engaged | 500uA maximum leakage current | Power | Power
0.1.1.7 | Watchdog timer | The BMS PCB shall enter failsafe when the microcontroller fails to send a valid SPI packet to the LT6803 with a time limit | 1 second time limit | Digital | Power
0.1.2.1 | Reverse polarity charger protection | The BMS shall be tolerant of a reverse polarity voltage on the charger input connector | 100V maximum reverse voltage | Power | Power
0.1.3.1 | BMS PCB battery fuse | The BMS PCB shall accept automotive blade fuses at the battery pack power connector | Fuse type | Power | Power
Discharge Requirements
3.3.1.1 | Low voltage pack discharge cut-off | The battery pack shall be electrically disconnected from the load when the battery voltage falls below a threshold. | 36V threshold; 1V hysteresis | Power | Power
3.3.1.2 | Over-current pack discharge cut-off | The battery pack shall be electrically disconnected from the load when the discharge current exceeds a threshold. | 35A threshold; <10mS cut-off latency | Power | Power
3.3.1.3 | Over/under-temperature pack discharge cut-off | The battery pack shall be electrically disconnected from the load if the pack temperature is outside of a set range | -15°C to 45°C temperature range | Power | Power
3.3.2.1 | Low voltage cell discharge cut-off | The battery pack shall be electrically disconnected from the load when any cell voltage falls below a threshold. | 2.9V threshold; 0.15V hysteresis | Power | Power
3.4.1.0 | Balance status indication LED | The BMS PCB shall indicate the balancing status of each cell in the pack with a dedicated on-board LED | Human visible LED in circuit design | Digital | Balancing
3.4.1.1 | Cell balancing | The cells voltages shall be balanced through resistive dissipation to within a threshold | 0.1V threshold | Power, Digital | Balancing
3.4.1.2 | Balance status indication LED circuit topology | The balance status indication LED shall be in parallel with the power dissipation LED | Design of indication LED circuits | Power | Balancing
3.4.2.1 | Cell balancing current | The cells shall be balanced through resistive dissipation at a specific constant current | 1A discharge rate | Power | Balancing
Charge Requirements
4.0.0.1 | Charge battery pack | The battery system will recharge when plugged into a power outlet | 15 Amp 120VAC power input | Power | Charger
4.3.1.1 | Over-voltage pack charge cut-off | The battery pack shall be electrically disconnected from the charger when the pack voltage exceeds a threshold. | 51.6V threshold | Power | Power
4.3.1.2 | Over-current pack charge cut-off | The battery pack shall be electrically disconnected from the load when the charge current exceeds a threshold. | 8A threshold; <10mS cut-off latency | Power | Power
4.3.1.3 | Over/under-temperature pack charge cut-off | The battery pack shall be electrically disconnected from the charger if the pack temperature is outside of a set range | -15°C to 45°C temperature range | Power | Power
4.3.2.1 | Over-voltage cell charge cut-off | The battery pack shall be electrically disconnected from the charger when any cell voltage exceeds a threshold. | 4.3V threshold | Power | Power
Communication Requirements
6.1.2.0 | CANbus physical and datalink layer standard | The CANbus interface shall follow the specifications of the ISO 11898-2:2003 | CANbus physical and protocol layers | Digital | Microcontroller
6.1.2.1 | CANbus system reporting | The BMS PCB microcontroller shall report sensor and system status information to a remote master on the CANbus network | Deliver data | Digital | Microcontroller
6.1.2.2 | CANbus system control | The BMS PCB microcontroller shall respond to commands from a master on the CANbus network | Respond to CANbus commands | Digital | Microcontroller
6.1.3.0 | System status indication LED | The BMS PCB shall indicate the system state with a single on-board RGB LED | Human visible LED in circuit design | Digital | Microcontroller
6.1.4.0 | Reprogramming port | The BMC PCB shall have a JTAG connector for reprogramming the microcontroller | Accessibility of physical connector | Digital, mechanical | Microcontroller
6.1.5.0 | USB debugging | The BMC PCB microcontroller shall communicate as a USB DFU or CDC device to allow in-field debugging | Accessibility of physical connector | Digital, mechanical | Microcontroller
6.1.6.1 | Current sensor range | The battery and charge current sensors shall measure a specified current range | -50 Amp to +50 Amp DC | Digital, power | Microcontroller
6.1.6.2 | Current sensor ADC resolution | The battery and charge current sensors shall sense with a specified resolution | 0.05 Amp per ADC step | Digital, power | Microcontroller
Mechanical Requirements
7.0.0.0 | User removable battery system | The battery system shall be removable from the trike-mounted enclosure by a single person in less than thirty seconds | Mounting and accessibility of components in enclosure | Mechanical | Enclosure
7.1.1.1 | Battery pack cable resistance | The battery pack power cabling must be less than a specific resistance | 0.02 Ohm maximum resistance | Power, Mechanical | Enclosure
7.2.1.1 | Shock dampening bushings | The battery system enclosure mounting will dampen vibration with polyurethane bushing | Mechanical design element | Mechanical | Enclosure
7.2.2.1 | Battery enclosure dust/water resistance | The battery enclosure must meet IP55 environmental resistance specifications | Water and dust ingress | Mechanical | Enclosure
Environmental Requirements
8.1.1.1 | Environmental temperature range | The battery system must maintain functionality over a temperature range of -15° to 40°C. | -15° to 40°C temperature range | Mechanical | System wide
8.2.1.1 | Non-PVC cabling | The battery system shall not use wires or cables with PVC sheathing | Wire and cable material | Manufacturing | System wide
8.2.2.1 | RoHS compliance | The battery system shall meet EU RoHS regulatory requirements | RoHS stipulations | Manufacturing | System wide
Systems
Enclosure
Pack
Power
Charge
Balance
Logic

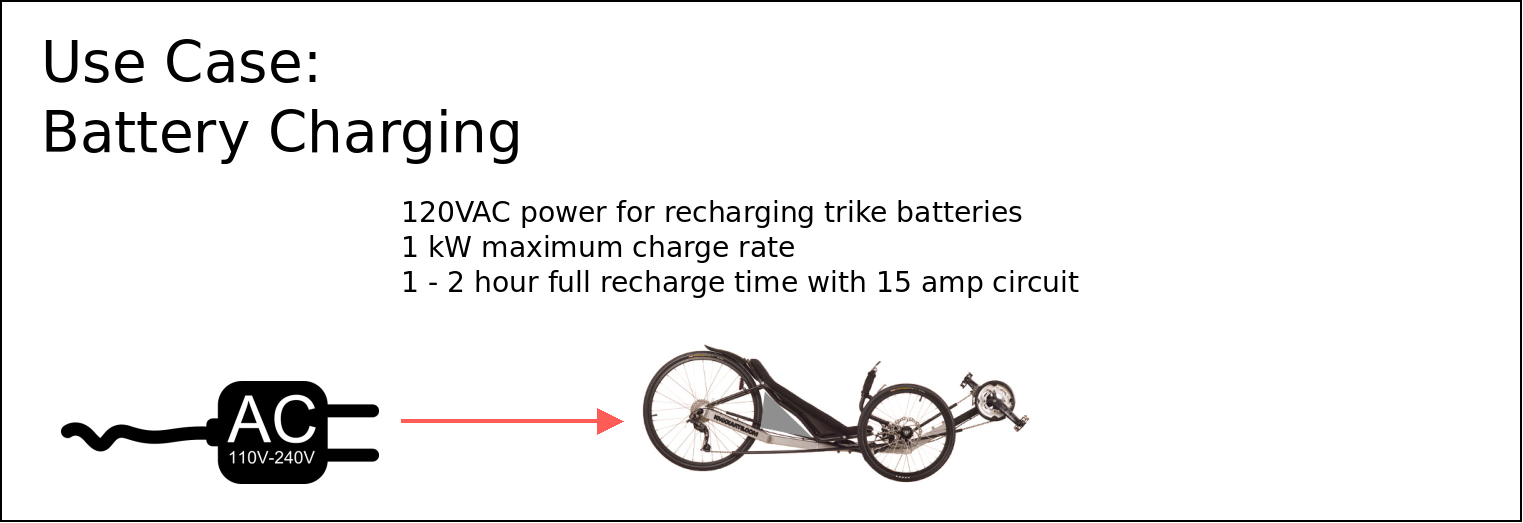
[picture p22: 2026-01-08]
analysis/diagrams/use_case_charging.png

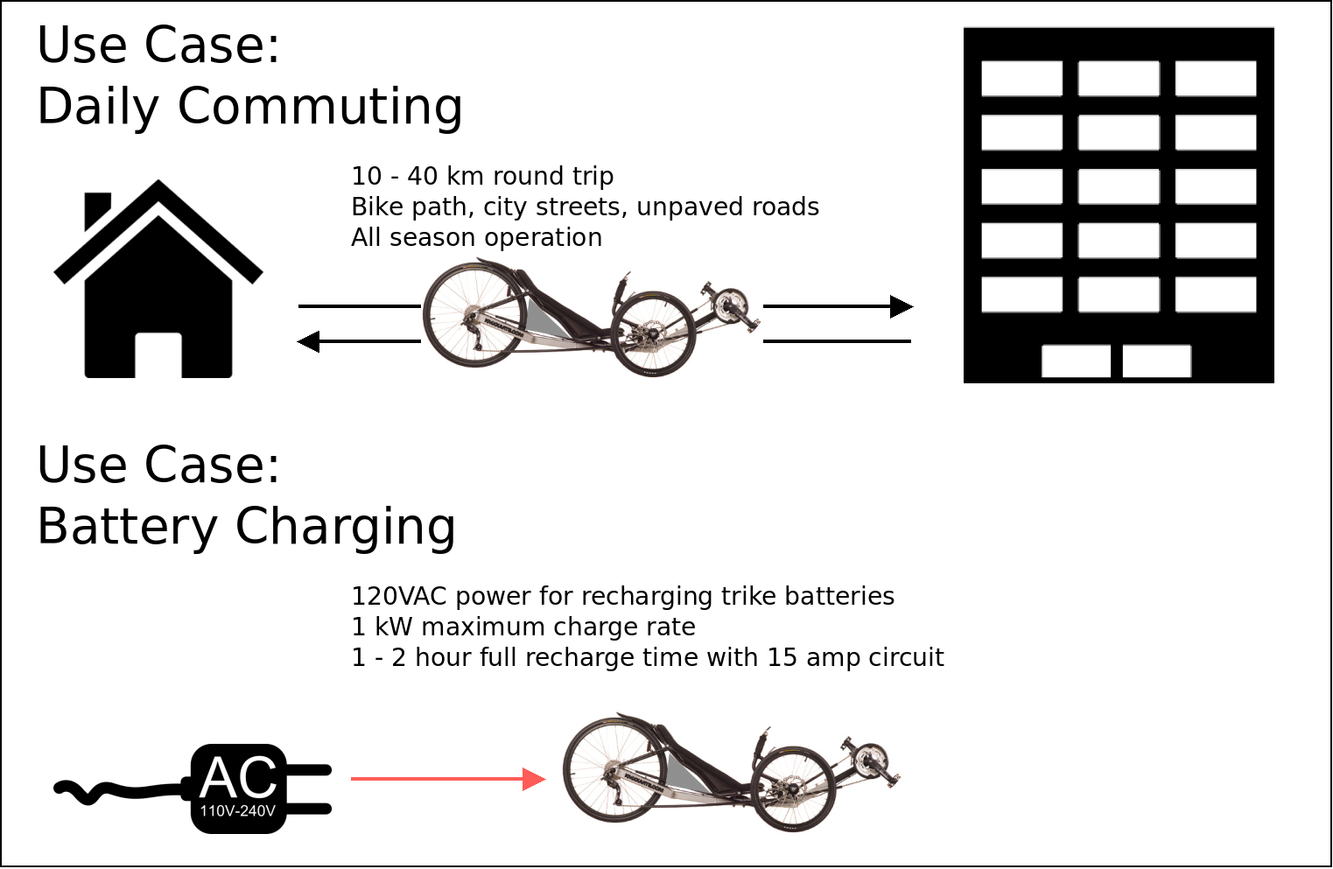
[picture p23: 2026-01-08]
analysis/diagrams/conops_visual.png

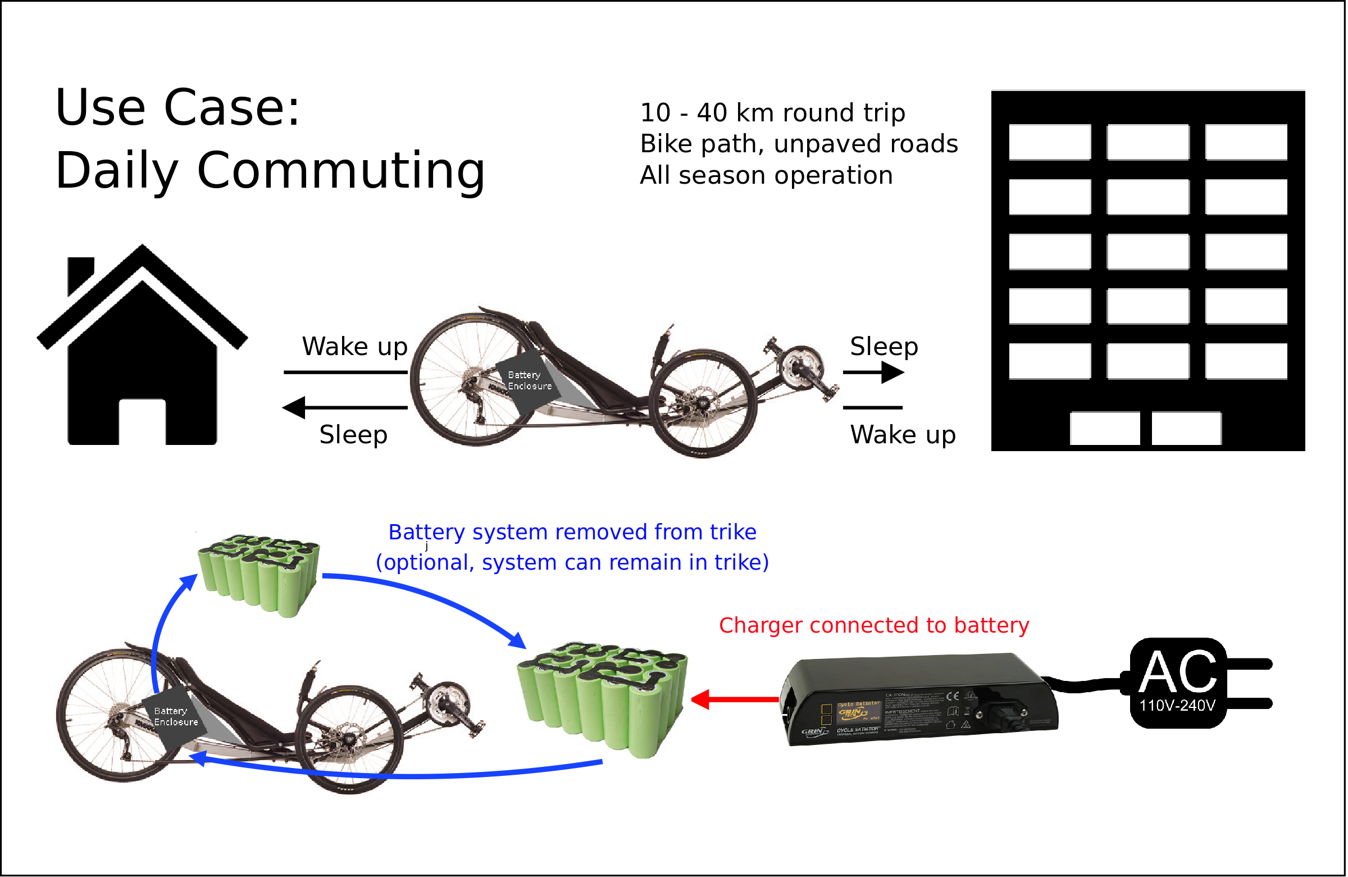
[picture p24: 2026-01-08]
analysis/diagrams/conops_battery_system.png

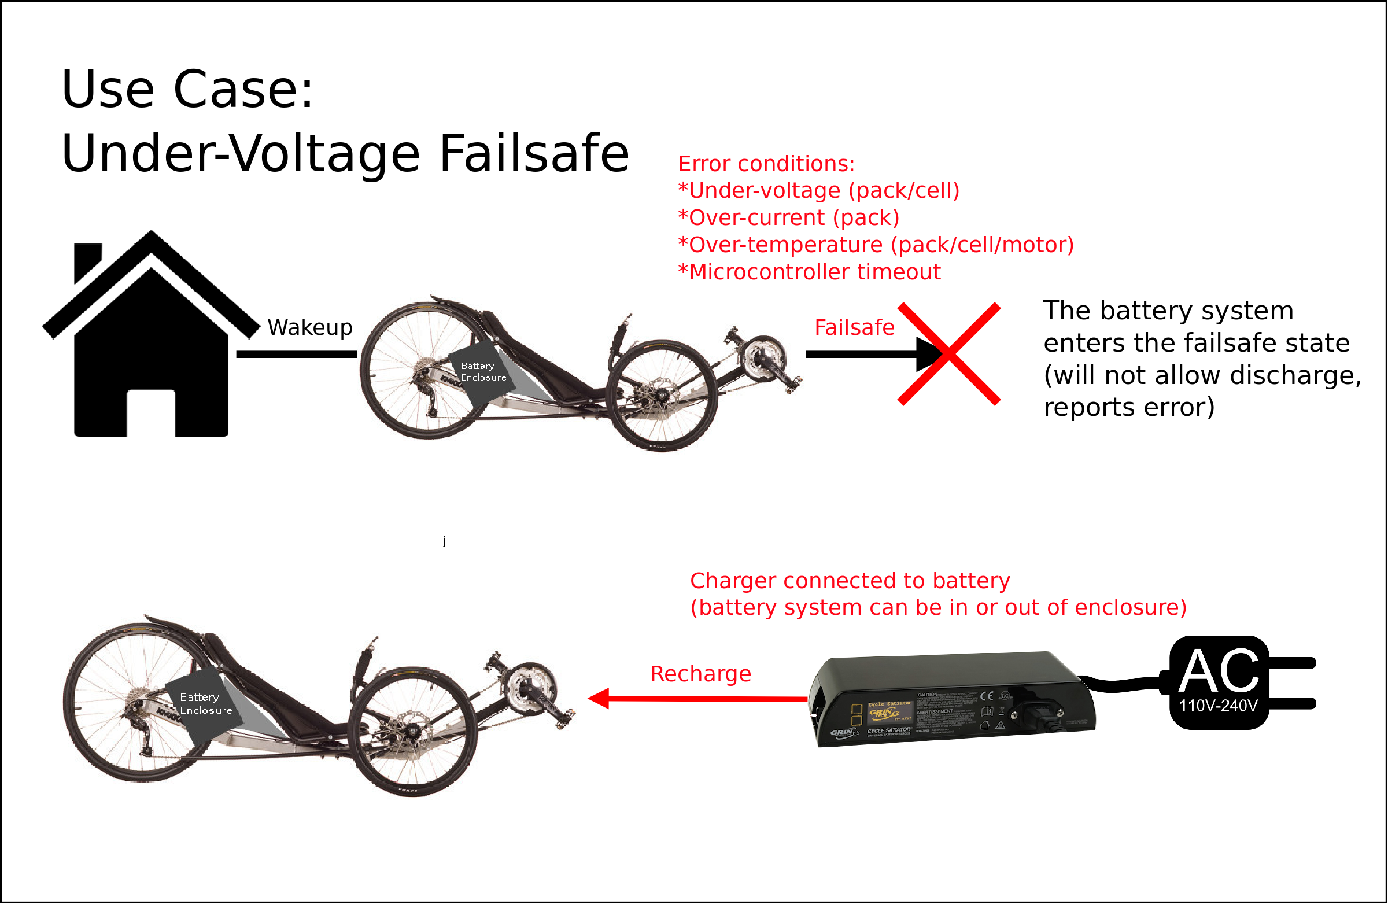
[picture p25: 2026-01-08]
analysis/diagrams/conops_battery_system_failsafe.png

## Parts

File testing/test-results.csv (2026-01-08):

BMS v0.1 PCB Testing
ID | Group | Subgroup | Requirement Name | Requirement Description | ID | Measurement | Nominal Value | Results | Microcontroller? | Tolerance | Test Condition
0.01 | Sensor | Temperature | PCB TEMP 1 nominal | High temperature PCB thermistor calibration | 0.01 | Thermistor voltage drop | 0.3 | 0.311V | 0 | ? | Ambient temperature = 25C, 3V3 rail = 3.3V
0.02 | Sensor | Temperature | PCB TEMP 1 low | Low temperature PCB thermistor calibration | 0.02 | Thermistor voltage drop | 1.65V |  | 0 | ? | Ambient temperature = 25C, 3V3 rail = 3.3V
0.03 | Sensor | Temperature | LTC6803 VTEMP1 | High temperature VTEMP1 thermistor calibration | 0.03 | Thermistor voltage drop | 1.65V |  | 0 | ? | Ambient temperature = 25C, 3V3 rail = 3.3V
0.04 | Sensor | Temperature | LTC6803 VTEMP1 | Low temperature VTEMP1 thermistor calibration | 0.04 | Thermistor voltage drop | 1.65V |  | 0 | ? | Ambient temperature = 25C, 3V3 rail = 3.3V
0.05 | Sensor | Temperature | LTC6803 VTEMP2 | High temperature VTEMP2 thermistor calibration | 0.05 | Thermistor voltage drop | 1.65V |  | 0 | ? | Ambient temperature = 25C, 3V3 rail = 3.3V
0.06 | Sensor | Temperature | LTC6803 VTEMP2 | Low temperature VTEMP2 thermistor calibration | 0.06 | Thermistor voltage drop | 1.65V |  | 0 | ? | Ambient temperature = 25C, 3V3 rail = 3.3V
0.07 | Sensor | Power Input | VBATT_SENSE | Accuracy of the Vbatt sense voltage divider | 0.07 | Voltage on Vbatt_sense | input_volt = 0.04*v_batt | ~1.43 @ 37V, verified OK | 0 | +- 2% | V_batt > 30V, <55V
0.08 | Sensor | Power Input | chrg_sense | Accuracy of the Charge sense voltage divider | 0.08 | Voltage on CHRG_SENSE | input_volt = 0.04*V_charger | ~1.5 @ 37.02V, verified OK | 0 | +- 2% | V_charger > 30V, <55V
0.09 | Sensor | Load current | load_aout | Accuracy of the load current amplifier | 0.09 | Voltage on LOAD_CURRENT | ? | V2.579 output at load = 1.825A | 0 | ? | I_load > 0, V_batt >30V
0.1 | Sensor | Charger current | CHRG_AOUT | Accuracy of the charge current amplifier | 0.1 | Voltage on CHRG_CURRENT | ? |  | 0 | ? | I_charger > 0, V_batt >30V
0.11 | Sensor | Load fault | LOAD_FLT | Load over-current fault | 0.11 | Voltage on load MOSFET gate | 0V | ~=V_supply | 0 | - | I_load > cut-off threshold
0.12 | Sensor | Charger fault | CHRG_FLT | Charger over-current fault | 0.12 | Voltage on charger MOSFET gate | 0V |  | 0 | - | I_charger > cut-off threshold
0.13 | Sensor | Protection | chrg_sense over-voltage | The dual-diode device should protect the STM32 from over-voltage on chrg_sense | 0.13 | Voltage on chrg_sense | < 4V |  |  | ? | >4V injected on this net, <10mA
0.14 | Sensor | Protection | vbatt_sense over-voltage | The dual-diode device should protect the STM32 from over-voltage on vbatt_sense | 0.14 | Voltage on vbatt_sense | < 4V |  |  | ? | >4V injected on this net, <10mA
0.15 | Sensor | Protection | spi1 signals over-voltage | The dual-diode device should protect the STM32 from over-voltage on spi1 signals | 0.15 | Voltage on spi1 nets (CS, MISO, MOSI, SCK) | < 4V |  |  | ? | >4V injected on this net, <10mA
1.01 | Power | Global | quiescent_current | Total PCB quiescent current | 1.01 | Current from V_batt, current per cell | <1.2mA | 11mA (PCB 4), constant with variable voltage, constant when 3V3 is off | 1 | ? | Low power mode
1.02 | Power | Battery | Reverse battery protection | P-channel MOSFET reverse battery protection | 1.02 | Voltage on VBATT net | 0V | Tests good | 0 | +- 0.1V | V_batt_raw = -60V
1.03 | Power | Charger | Reverse charger protection | P-channel MOSFET reverse charger protection | 1.03 | Voltage on VBATT net | 0V | FAIL, perhaps the LT1990 provides an alternate path? | 0 | +- 0.1V | V_CHARGER= -60V
1.04 | Power | LT3990 | LT3990 UVLO | LT3990 3V3 buck converter under-voltage lockout | 1.04 | Voltages on +3V3, LT3990 PG pin | 0V, 0V | Turn on @ 31V, turn off @ 28.8V | 0 | +- 0.5V | V_batt < 31V
1.05 | Power | 5V charge pump | 5V regulation accuracy | Voltage accuracy of 5V power rail | 1.05 | V_peak, V_rms on +5V net | <0.1V, 5V | tested, pics | 0 | - | 5V_SHDN = 3.3V, +3V3 = 3.3V, I_5V = 0A, = 40mA
1.06 | Power | LTC6803 | LTC6803 VREG | Internal ASIC power regulation of the LTC6803 | 1.06 | Voltage on Vreg net (LTC6803 pin 35) | 5V |  | ? | +- 0.5V | V_batt > 31V
1.07 | Power | Power | Balancing current | Balance current through the 10ohm power resistor | 1.07 | Voltage drop across power resistor | 0.4725A |  | 1 | +- 10% | V_cell ~ 4.3V
2.01 | Control | Load shutdown | Load shutdown | Load shutdown control | 2.01 | Conduction between Vbatt_sense and LOAD | 0A |  | 0 | - | Vbatt_sns > 30V, load_shdn = 0V
2.02 | Control | Charger control | Charger shutdown | Charger shutdown control | 2.02 | Conduction between V_charger, Vbatt_sense | 0A |  | 0 | - | V_charger > 30V, chrg_shdn = 0V
2.03 | Control | Aux power enable | aux_enable | Auxiliary power output control | 2.03 | Conduction between Vbatt_sense, AUX_OUT | 0A | tested | 0 | - | V_charger > 30V, chrg_shdn = 0V
2.04 | Control | CANbus | CANbus shutdown | CANbus interface shutdown control | 2.04 | Voltage on ADM3054 VDD2 pin | 5V |  | ? | ? | Microcontroller is operational
2.05 | Logic | LTC6803 | Watchdog timer | Watchdog timer shutdown of charge, load, and 5V | 2.05 | Conduction from Vbatt, CHARGE, LOAD, AUX | 0A |  | 1 | - | Vbatt_sns > 30V, WDTB active
2.06 | Logic | STM32 | USB DFU enumeration | The STM32 enumerates as a DFU device with a Linux host | 2.06 | Host computer DMESG terminal output | Device file (/dev/ttyACM0) | Verified | 1 | - | Microcontroller is operational, BOOT = 3.3V
2.07 | Logic | STM32 | jtag_id | The STM32 communicates its device ID over JTAG | 2.07 | Microcontroller device ID | !0x0000 or !0xFFFF | Verified | 1 | - | Microcontroller is operational
2.08 | Logic | STM32 | swd_id | The STM32 communicates its device ID over SWD | 2.08 | Microcontroller device ID | !0x0000 or !0xFFFF | Verified | 1 | - | Microcontroller is operational
2.09 | Logic | STM32 | stm32_reset | The STM32 resets when the momentary button is pressed | 2.09 | Microcontroller operational state | Reset | Verified | 1 | - | Microcontroller is operational, RESET = 0V
2.1 | Logic | STM32 | Read Button 1 | The STM32 can read the state of button 1 | 2.1 | Button 1 state | logical state = physical state |  | 1 | - | Microcontroller is operational, button 1 is pressed
2.11 | Logic | STM32 | Read Button 2 | The STM32 can read the state of button 2 | 2.11 | Button 2 state | logical state = physical state |  | 1 | - | Microcontroller is operational, button 2 is pressed
2.12 | Logic | STM32 | RGB LED output | The STM32 can control the R,G,B LED color channels | 2.12 | R,G,B LED states | LED color = logical control |  | 1 | - | Microcontroller is operational
2.13 | Logic | STM32 | 8Mhz crystal accuracy | The frequency accuracy of the 8Mhz crystal | 2.13 | Frequency of waveform on OSC_IN | 8Mhz or 16Mhz |  | 1 | +-20ppm | Microcontroller is operational, external oscillator enabled
2.14 | Logic | STM32 | 32.768Khz crystal accuracy | The frequency accuracy of the 32.768Khz crystal | 2.14 | Frequency of waveform on OSC32_IN | 32.768Khz |  | 1 | +-20ppm | Microcontroller is operational, low speed oscillator enabled

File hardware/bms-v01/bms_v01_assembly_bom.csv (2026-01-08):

ChibiBMS v0.1 Preliminary BOM |  |  |  |  |  |  |  |  |  |  |  |  |  |  |  |  |  |  |  |  |  |  |  |  |  |  | 102.7937 | 86.5294 | 67.49273
Qty | Line Item | Manufacturer | MPN | Total Qty [1] | Total Qty [10] | Total Qty [100] | SKU | SKU | SKU | Unit Price [1] | Unit Price [1] | Unit Price [1] | Unit Price [10] | Unit Price [10] | Unit Price [10] | Unit Price [100] | Unit Price [100] | Unit Price [100] | Distributor [null] | SKU [null] | Unit Price [1] | Unit Price [10] | Unit Price [100] | Line Total [1] | Line Total [10] | Line Total [100] | Batch Total [1] | Batch Total [10] | Batch Total [100]
 |  |  |  |  |  |  | Digi-Key | Mouser | Newark | Digi-Key | Mouser | Newark | Digi-Key | Mouser | Newark | Digi-Key | Mouser | Newark
1 | BA2032 | MPD | BA2032 | 1 | 10 | 100 | BA2032-ND |  |  | 1.16 |  |  | 1.077 |  |  | 0.97 |  |  | Onlinecomponents.com | BA2032 | 1.06 | 1.06 | 0.88 | 1.06 | 1.06 | 0.88 | 1.06 | 10.6 | 88
4 | EVQ-P2K02Q | Panasonic | EVQ-P2K02Q | 4 | 40 | 400 | P11084SDKR-ND | EVQ-P2K02Q | 01X1652 | 0.83 | 0.82 | 0.388 | 0.6844 | 0.651 | 0.388 | 0.57024 | 0.544 | 0.388 | Newark | 01X1652 | 0.388 | 0.388 | 0.388 | 1.552 | 1.552 | 1.552 | 1.552 | 15.52 | 155.2
14 | GRM188R61E105KA12D | Murata | GRM188R61E105KA12D | 14 | 140 | 1400 | 490-3897-6-ND | GRM188R61E105KA12D | 18X5182 | 0.044 | 0.026 | 0.025 | 0.0202 | 0.022 | 0.025 | 0.01101 | 0.022 | 0.021 | Newark | 18X5182 | 0.025 | 0.0202 | 0.01101 | 0.35 | 0.2828 | 0.15414 | 0.35 | 2.828 | 15.414
2 | GRM1885C1H180FA01D | Murata | GRM1885C1H180FA01D | 2 | 20 | 200 | 490-9716-1-ND | GRM1885C1H180FA01D |  | 0.16 | 0.16 |  | 0.111 | 0.064 |  | 0.0527 | 0.038 |  | Avnet Express | GRM1885C1H180FA01D/BKN | 0.095 | 0.0545 | 0.0285 | 0.19 | 0.109 | 0.057 | 0.19 | 1.09 | 5.7
2 | GRM1885C2A120JA01D | Murata | GRM1885C2A120JA01D | 2 | 20 | 200 | 490-1329-1-ND | GRM1885C2A120JA01D |  | 0.1 | 0.32 |  | 0.053 | 0.04 |  | 0.0241 | 0.024 |  | Digi-Key | 490-1329-1-ND | 0.1 | 0.04 | 0.024 | 0.2 | 0.08 | 0.048 | 0.2 | 0.8 | 4.8
17 | C3216X7S2A225K160AB | EPCOS | C3216X7S2A225K160AB | 17 | 170 | 1700 | 445-5207-1-ND | C3216X7S2A225K160AB | 87R4390 | 0.752 | 0.752 | 0.198 | 0.3647 | 0.275 | 0.198 | 0.2475 | 0.275 | 0.198 | Newark | 87R4390 | 0.198 | 0.198 | 0.198 | 3.366 | 3.366 | 3.366 | 3.366 | 33.66 | 336.6
9 | C3216X5R1A107M160AC | EPCOS | C3216X5R1A107M160AC | 9 | 90 | 900 | 445-6007-1-ND | C3216X5R1A107M160AC | 12T1945 | 1.68 | 1.68 | 0.479 | 1.38 | 1.38 | 0.479 | 0.7237 | 0.808 | 0.479 | Newark | 12T1945 | 0.479 | 0.479 | 0.44 | 4.311 | 4.311 | 3.96 | 4.311 | 43.11 | 396
2 | GRM1887U1H103JA01D | Murata | GRM1887U1H103JA01D | 2 | 20 | 200 | 490-6394-1-ND | GRM1887U1H103JA01D |  | 0.27 | 0.27 |  | 0.187 | 0.114 |  | 0.0951 | 0.068 |  | Arrow | GRM1887U1H103JA01D | 0.0381 | 0.0381 | 0.0381 | 0.0762 | 0.0762 | 0.0762 | 0.0762 | 0.762 | 7.62
1 | GRM188F51H224ZA01D | Murata | GRM188F51H224ZA01D | 1 | 10 | 100 | 490-1569-1-ND | GRM188F51H224ZA01D |  | 0.11 | 0.11 |  | 0.081 | 0.044 |  | 0.037 | 0.026 |  | Digi-Key | 490-1569-1-ND | 0.11 | 0.044 | 0.026 | 0.11 | 0.044 | 0.026 | 0.11 | 0.44 | 2.6
20 | GRM188R71H104KA93D | Murata Erie | GRM188R71H104KA93D | 20 | 200 | 2000 | 490-1519-1-ND | GRM188R71H104KA93D | 18X5188 | 0.04 | 0.022 | 0.032 | 0.0182 | 0.013 | 0.032 | 0.0099 | 0.013 | 0.029 | DKO Electronshik | 441095 | 0.0203 | 0.013 | 0.0081 | 0.406 | 0.26 | 0.162 | 0.406 | 2.6 | 16.2
12 | GRM188R61E106MA73D | Murata | GRM188R61E106MA73D | 12 | 120 | 1200 | 490-7202-1-ND | GRM188R61E106MA73D |  | 0.354 | 0.215 |  | 0.1768 | 0.129 |  | 0.11615 | 0.129 |  | Mouser | GRM188R61E106MA73D | 0.215 | 0.129 | 0.106 | 2.58 | 1.548 | 1.272 | 2.58 | 15.48 | 127.2
9 | MMBZ5225B-7-F | Diodes Inc. | MMBZ5225B-7-F | 9 | 90 | 900 | MMBZ5225B-FDIDKR-ND | MMBZ5225B-7-F |  | 0.2 | 0.2 |  | 0.1676 | 0.167 |  | 0.0589 | 0.059 |  | Digi-Key | MMBZ5225B-FDIDKR-ND | 0.2 | 0.141 | 0.0587 | 1.8 | 1.269 | 0.5283 | 1.8 | 12.69 | 52.83
4 | SMCJ54CA-13-F | Diodes Inc. | SMCJ54CA-13-F | 4 | 40 | 400 | SMCJ54CA-FDICT-ND |  |  | 0.82 |  |  | 0.638 |  |  | 0.484 |  |  | Digi-Key | SMCJ54CA-FDICT-ND | 0.82 | 0.638 | 0.484 | 3.28 | 2.552 | 1.936 | 3.28 | 25.52 | 193.6
25 | MMBZ5233BLT1G | ON Semiconductor | MMBZ5233BLT1G | 25 | 250 | 2500 | MMBZ5233BLT1GOSDKR-ND | MMBZ5233BLT1G | 88H4814 | 0.13 | 0.13 |  | 0.05516 | 0.046 |  | 0.03121 | 0.046 |  | Mouser | MMBZ5233BLT1G | 0.13 | 0.046 | 0.03121 | 3.25 | 1.15 | 0.78025 | 3.25 | 11.5 | 78.025
1 | BZX84-C56,215 | NXP Semiconductors | BZX84-C56,215 | 1 | 10 | 100 | 568-6332-1-ND | BZX84-C56,215 |  | 0.16 | 0.15 |  | 0.149 | 0.135 |  | 0.0973 | 0.048 |  | DKO Electronshik | 42321 | 0.0649 | 0.0649 | 0.048 | 0.0649 | 0.0649 | 0.048 | 0.0649 | 0.649 | 4.8
3 | MMBD4448H-7-F | Diodes Inc. | MMBD4448H-7-F | 3 | 30 | 300 | MMBD4448H-FDIDKR-ND | MMBD4448H-7-F | 51R6793 | 0.21 | 0.21 | 0.191 | 0.1392 | 0.14 | 0.13 | 0.06796 | 0.058 | 0.044 | Newark | 51R6793 | 0.191 | 0.13 | 0.044 | 0.573 | 0.39 | 0.132 | 0.573 | 3.9 | 13.2
1 | SZNUP2105LT1G | ON Semiconductor | SZNUP2105LT1G | 1 | 10 | 100 | SZNUP2105LT1GOSDKR-ND | SZNUP2105LT1G | 76T7856 | 0.48 | 0.47 |  | 0.408 | 0.346 |  | 0.3059 | 0.218 |  | Allied Electronics | 70300693 | 0.337 | 0.337 | 0.218 | 0.337 | 0.337 | 0.218 | 0.337 | 3.37 | 21.8
3 | MMBZ5242BLT1G | ON Semiconductor | MMBZ5242BLT1G | 3 | 30 | 300 | MMBZ5242BLT1GOSDKR-ND | MMBZ5242BLT1G | 85W2816 | 0.16 | 0.15 | 0.024 | 0.13 | 0.13 | 0.024 | 0.05516 | 0.046 | 0.024 | Newark | 85W2816 | 0.024 | 0.024 | 0.024 | 0.072 | 0.072 | 0.072 | 0.072 | 0.72 | 7.2
4 | ZLLS1000TA | Diodes Inc. | ZLLS1000TA | 4 | 40 | 400 | ZLLS1000CT-ND | ZLLS1000TA |  | 0.64 | 0.63 |  | 0.536 | 0.468 |  | 0.4017 | 0.295 |  | DKO Electronshik | 181043 | 0.1736 | 0.1719 | 0.1719 | 0.6944 | 0.6876 | 0.6876 | 0.6944 | 6.876 | 68.76
1 | 3555-2 | Keystone | 3555-2 | 1 | 10 | 100 | 3555-2K-ND | 3555-2 | 22M2709 | 1.43 | 1.38 | 1.31 | 1.243 | 1.22 | 1.31 | 1.0725 | 1.1 | 1.31 | Allied Electronics | 70182440 | 0.995 | 0.995 | 0.904 | 0.995 | 0.995 | 0.904 | 0.995 | 9.95 | 90.4
1 | 1050170001 | Molex | 105017-0001 | 1 | 10 | 100 | WM1399DKR-ND | 105017-0001 | 28X2628 | 0.87 | 0.87 | 0.354 | 0.763 | 0.763 | 0.354 | 0.6582 | 0.718 | 0.354 | Newark | 28X2628 | 0.354 | 0.354 | 0.354 | 0.354 | 0.354 | 0.354 | 0.354 | 3.54 | 35.4
1 | DM3BT-DSF-PEJS | Hirose | DM3BT-DSF-PEJS | 1 | 10 | 100 | HR1942CT-ND | DM3BT-DSF-PEJS | 35R0580 | 2.55 | 2.31 | 2.59 | 2.318 | 1.89 | 2.59 | 1.9866 | 1.8 | 2.34 | Mouser | DM3BT-DSF-PEJS | 2.31 | 1.82 | 1.29 | 2.31 | 1.82 | 1.29 | 2.31 | 18.2 | 129
1 | 705530003 | Molex | 70553-0002 | 1 | 10 | 100 | WM4901-ND | 70553-0002 | 59H2871 | 1.06 | 1.34 | 0.612 | 0.935 | 1.07 | 0.612 | 0.807 | 0.814 | 0.524 | Arrow | 705530002 | 0.4257 | 0.4257 | 0.3 | 0.4257 | 0.4257 | 0.3 | 0.4257 | 4.257 | 30
1 | 705530013 | Molex | 70553-0013 | 1 | 10 | 100 | WM4912-ND | 70553-0013 | 39C0231 | 5.5 | 4.04 | 4.15 | 5.28 | 3.66 | 3.76 | 4.3996 | 3.02 | 3.22 | Allied Electronics | E5296655 | 3.892 | 3.66 | 1.73525 | 3.892 | 3.66 | 1.73525 | 3.892 | 36.6 | 173.525
1 | 705530005 | Molex | 70553-0005 | 1 | 10 | 100 |  | 70553-0005 | 64T4861 |  | 1.67 | 1.6 |  | 1.3 | 1.6 |  | 1.1 | 1.29 | Electro Sonic | 705530005 | 0.74 | 0.74 | 0.59907 | 0.74 | 0.74 | 0.59907 | 0.74 | 7.4 | 59.907
1 | 20021121-00010T4LF | FCI | 20021121-00010T4LF | 1 | 10 | 100 | 609-3729-ND | 20021121-00010T4LF | 82R7892 | 0.74 | 0.74 |  | 0.69 | 0.69 |  | 0.529 | 0.483 |  | Arrow | 20021121-00010T4LF | 0.3954 | 0.3954 | 0.3954 | 0.3954 | 0.3954 | 0.3954 | 0.3954 | 3.954 | 39.54
2 | CBMF1608T1R0M | Taiyo Yuden | CBMF1608T1R0M | 2 | 20 | 200 | 587-1717-1-ND | CBMF1608T1R0M | 83T0091 | 0.2 | 0.2 | 0.087 | 0.184 | 0.173 | 0.087 | 0.161 | 0.161 | 0.087 | Newark | 83T0091 | 0.087 | 0.087 | 0.0178 | 0.174 | 0.174 | 0.0356 | 0.174 | 1.74 | 3.56
1 | EXC-24CP221U | Panasonic | EXC-24CP221U | 1 | 10 | 100 | P11598DKR-ND | EXC-24CP221U | 56W0687 | 0.7 | 0.51 |  | 0.66 | 0.429 |  | 0.5775 | 0.404 |  | Mouser | EXC-24CP221U | 0.51 | 0.429 | 0.404 | 0.51 | 0.429 | 0.404 | 0.51 | 4.29 | 40.4
1 | SLF10145T-330M1R6-PF | TDK-Lambda | SLF10145T-330M1R6-PF | 1 | 10 | 100 | 445-1983-1-ND | SLF10145T-330M1R6-PF | 90R0608 | 1.2 | 1.17 | 0.5 | 1.125 | 0.879 | 0.5 | 0.855 | 0.836 | 0.5 | Newark | 90R0608 | 0.5 | 0.5 | 0.5 | 0.5 | 0.5 | 0.5 | 0.5 | 5 | 50
1 | CLV6A-FKB-CK1P1G1BB7R3R3 | Cree | CLV6A-FKB-CK1P1G1BB7R3R3 | 1 | 10 | 100 | CLV6A-FKB-CK1P1G1BB7R3R3DKR-ND |  | 28X4736 | 0.75 |  | 0.441 | 0.75 |  | 0.441 | 0.667 |  | 0.441 | Newark | 28X4736 | 0.441 | 0.441 | 0.441 | 0.441 | 0.441 | 0.441 | 0.441 | 4.41 | 44.1
12 | SML-D12V8WT86 | Rohm | SML-D12V8WT86 | 12 | 120 | 1200 | 511-1581-1-ND | SML-D12V8WT86 |  | 0.38 | 0.273 |  | 0.2014 | 0.117 |  | 0.095 | 0.117 |  | Mouser | SML-D12V8WT86 | 0.273 | 0.117 | 0.095 | 3.276 | 1.404 | 1.14 | 3.276 | 14.04 | 114
16 | AOD417 | Alpha & Omega | AOD417 | 16 | 160 | 1600 | 785-1106-1-ND |  |  | 0.53 |  |  | 0.3337 |  |  | 0.189 |  |  | Digi-Key | 785-1106-1-ND | 0.53 | 0.3337 | 0.189 | 8.48 | 5.3392 | 3.024 | 8.48 | 53.392 | 302.4
2 | DMN6140L-7 | Diodes Inc. | DMN6140L-7 | 2 | 20 | 200 | DMN6140L-7DICT-ND | DMN6140L-7 |  | 0.41 |  |  | 0.294 |  |  | 0.1731 |  |  | Digi-Key | DMN6140L-7DICT-ND | 0.41 | 0.294 | 0.1731 | 0.82 | 0.588 | 0.3462 | 0.82 | 5.88 | 34.62
1 | ZLLS1000TA | Diodes Inc. | ZLLS1000TA | 1 | 10 | 100 | ZLLS1000CT-ND | ZLLS1000TA |  | 0.64 | 0.63 |  | 0.536 | 0.468 |  | 0.4017 | 0.295 |  | DKO Electronshik | 181043 | 0.1736 | 0.1719 | 0.1719 | 0.1736 | 0.1719 | 0.1719 | 0.1736 | 1.719 | 17.19
12 | ZXMP2120FFTA | Diodes Inc. | ZXMP2120FFTA | 12 | 120 | 1200 | ZXMP2120FFDKR-ND | ZXMP2120FFTA |  | 0.578 | 0.51 |  | 0.4448 | 0.33 |  | 0.264 | 0.33 |  | Mouser | ZXMP2120FFTA | 0.51 | 0.33 | 0.264 | 6.12 | 3.96 | 3.168 | 6.12 | 39.6 | 316.8
24 | CR0603-FX-22R0ELF | Bourns | CR0603-FX-22R0ELF | 24 | 240 | 2400 | CR0603-FX-22R0ELFCT-ND | CR0603-FX-22R0ELF | 32K2286 | 0.046 |  | 0.006 | 0.0187 |  | 0.006 | 0.0084 |  | 0.006 | Newark | 32K2286 | 0.006 | 0.006 | 0.006 | 0.144 | 0.144 | 0.144 | 0.144 | 1.44 | 14.4
14 | CR0603-FX-1003HLF | Bourns | CR0603-FX-1003HLF | 14 | 140 | 1400 | CR0603-FX-1003HLFDKR-ND | CR0603-FX-1003HLF | 06X5117 | 0.046 |  | 0.015 | 0.0187 |  | 0.015 | 0.0084 |  | 0.009 | Newark | 06X5117 | 0.015 | 0.015 | 0.0084 | 0.21 | 0.21 | 0.1176 | 0.21 | 2.1 | 11.76
10 | CR0603-FX-1004ELF | Bourns | CR0603-FX-1004ELF | 10 | 100 | 1000 | CR0603-FX-1004ELFCT-ND | CR0603-FX-1004ELF | 02J1987 | 0.046 |  | 0.007 | 0.0187 |  | 0.007 | 0.0084 |  | 0.007 | Newark | 02J1987 | 0.007 | 0.0058 | 0.0049 | 0.07 | 0.058 | 0.049 | 0.07 | 0.58 | 4.9
13 | CR0603-FX-3301ELF | Bourns | CR0603-FX-3301ELF | 13 | 130 | 1300 | CR0603-FX-3301ELFDKR-ND | CR0603-FX-3301ELF | 65T8175 | 0.046 |  | 0.015 | 0.0187 |  | 0.015 | 0.0084 |  | 0.009 | Newark | 65T8175 | 0.015 | 0.015 | 0.0084 | 0.195 | 0.195 | 0.1092 | 0.195 | 1.95 | 10.92
3 | CR0603-FX-5600ELF | Bourns | CR0603-FX-5600ELF | 3 | 30 | 300 | CR0603-FX-5600ELFCT-ND | CR0603-FX-5600ELF | 32K2484 | 0.1 |  |  | 0.0332 |  |  | 0.01424 |  |  | Digi-Key | CR0603-FX-5600ELFCT-ND | 0.1 | 0.0332 | 0.01424 | 0.3 | 0.0996 | 0.04272 | 0.3 | 0.996 | 4.272
29 | CR0603-FX-1000ELF | Bourns | CR0603-FX-1000ELF | 29 | 290 | 2900 | CR0603-FX-1000ELFCT-ND | CR0603-FX-1000ELF | 84W7231 | 0.0332 |  | 0.007 | 0.01424 |  | 0.007 | 0.00729 |  | 0.007 | Onlinecomponents.com | CR0603FX1000ELF | 0.0064 | 0.0058 | 0.0047 | 0.1856 | 0.1682 | 0.1363 | 0.1856 | 1.682 | 13.63
5 | CR0603-FX-2203ELF | Bourns | CR0603-FX-2203ELF | 5 | 50 | 500 | CR0603-FX-2203ELFCT-ND | CR0603-FX-2203ELF | 06X5131 | 0.1 |  | 0.015 | 0.0254 |  | 0.015 | 0.0114 |  | 0.01 | Arrow | CR0603-FX-2203ELF | 0.0023 | 0.0023 | 0.0023 | 0.0115 | 0.0115 | 0.0115 | 0.0115 | 0.115 | 1.15
3 | ERT-J1VV104J | Panasonic | ERT-J1VV104J | 3 | 30 | 300 | P10555DKR-ND | ERT-J1VV104J | 55T6150 | 0.39 | 0.39 | 0.096 | 0.22 | 0.22 | 0.096 | 0.1431 | 0.118 | 0.096 | Newark | 55T6150 | 0.096 | 0.096 | 0.096 | 0.288 | 0.288 | 0.288 | 0.288 | 2.88 | 28.8
12 | CRM2512-FX-10R0ELF | Bourns | CRM2512-FX-10R0ELF | 12 | 120 | 1200 | CRM2512-FX-10R0ELFDKR-ND | CRM2512-FX-10R0ELF | 87W5948 | 0.321 | 0.181 | 0.338 | 0.1349 | 0.098 | 0.222 | 0.07445 | 0.098 | 0.101 | Mouser | CRM2512-FX-10R0ELF | 0.181 | 0.098 | 0.07445 | 2.172 | 1.176 | 0.8934 | 2.172 | 11.76 | 89.34
2 | CSS2725FTL500 | Stackpole Electronics | CSS2725FTL500 | 2 | 20 | 200 | CSS2725FTL500DKR-ND |  |  | 1.29 |  |  | 1.188 |  |  | 0.9075 |  |  | Digi-Key | CSS2725FTL500DKR-ND | 1.29 | 1.188 | 0.9075 | 2.58 | 2.376 | 1.815 | 2.58 | 23.76 | 181.5
3 | RMCF0603FT2M00 | Stackpole Electronics | RMCF0603FT2M00 | 3 | 30 | 300 | RMCF0603FT2M00DKR-ND |  |  | 0.1 |  |  | 0.025 |  |  | 0.0078 |  |  | Digi-Key | RMCF0603FT2M00DKR-ND | 0.1 | 0.025 | 0.0078 | 0.3 | 0.075 | 0.0234 | 0.3 | 0.75 | 2.34
1 | RC1608F2554CS | Stackpole Electronics | RC1608F2554CS | 1 | 10 | 100 | 1276-4953-6-ND |  |  | 0.1 |  |  | 0.019 |  |  | 0.0078 |  |  | Digi-Key | 1276-4953-6-ND | 0.1 | 0.019 | 0.0078 | 0.1 | 0.019 | 0.0078 | 0.1 | 0.19 | 0.78
2 | CR0603-FX-3302ELF | Bourns | CR0603-FX-3302ELF | 2 | 20 | 200 | CR0603-FX-3302ELFDKR-ND | CR0603-FX-3302ELF | 06X5136 | 0.1 |  | 0.015 | 0.046 |  | 0.015 | 0.0187 |  | 0.015 | Arrow | CR0603-FX-3302ELF | 0.0023 | 0.0023 | 0.0023 | 0.0046 | 0.0046 | 0.0046 | 0.0046 | 0.046 | 0.46
2 | CR0603-J/-000ELF | Bourns | CR0603-J/-000ELF | 2 | 20 | 200 | CR0603-J/-000ELFCT-ND | CR0603-J/-000ELF | 84W7241 | 0.1 |  | 0.003 | 0.029 |  | 0.003 | 0.0117 |  | 0.003 | Newark | 84W7241 | 0.003 | 0.003 | 0.003 | 0.006 | 0.006 | 0.006 | 0.006 | 0.06 | 0.6
1 | RMCF0603FT374K | Stackpole Electronics | RMCF0603FT374K | 1 | 10 | 100 | RMCF0603FT374KCT-ND |  |  | 0.1 |  |  | 0.025 |  |  | 0.0105 |  |  | Digi-Key | RMCF0603FT374KCT-ND | 0.1 | 0.025 | 0.0105 | 0.1 | 0.025 | 0.0105 | 0.1 | 0.25 | 1.05
1 | STM32F303CCT6 | STMicroelectronics | STM32F303CCT6 | 1 | 10 | 100 | 497-13318-ND | STM32F303CCT6 | 46W2192 | 7.83 | 7.83 | 7.68 | 7.047 | 7.05 | 6.56 | 5.7942 | 6.42 | 5.23 | Avnet Express | STM32F303CCT6 | 4.61 | 4.1 | 4.1 | 4.61 | 4.1 | 4.1 | 4.61 | 41 | 410
1 | ADM3054BRWZ-RL7 | Analog Devices | ADM3054BRWZ-RL7 | 1 | 10 | 100 | ADM3054BRWZ-RL7CT-ND | ADM3054BRWZ-RL7 | 72T3515 | 5.88 | 5.42 |  | 5.27 | 4.84 |  | 4.3097 | 4.35 |  | Mouser | ADM3054BRWZ-RL7 | 5.42 | 4.84 | 4.3097 | 5.42 | 4.84 | 4.3097 | 5.42 | 48.4 | 430.97
2 | LT1999CMS8-50#PBF | Linear Technology | LT1999CMS8-50#PBF | 2 | 20 | 200 | LT1999CMS8-50#PBF-ND |  | 24T0466 | 4.1 |  | 3.02 | 4.1 |  | 3.02 | 2.24 |  | 2.24 | Newark | 24T0466 | 3.02 | 3.02 | 2.24 | 6.04 | 6.04 | 4.48 | 6.04 | 60.4 | 448
1 | LT3990IMSE-3.3#PBF | Linear Technology | LT3990IMSE-3.3#PBF | 1 | 10 | 100 | LT3990IMSE-3.3#PBF-ND |  | 24W8547 | 6.18 |  |  | 6.18 |  |  | 3.51 |  |  | Digi-Key | LT3990IMSE-3.3#PBF-ND | 6.18 | 6.18 | 3.51 | 6.18 | 6.18 | 3.51 | 6.18 | 61.8 | 351
1 | LTC6803HG-3#PBF | Linear Technology | LTC6803HG-3#PBF | 1 | 10 | 100 | LTC6803HG-3#PBF-ND |  | 59T9370 | 19.03 |  |  | 19.03 |  |  | 12.98 |  | 12.98 | Arrow | LTC6803HG-3#PBF | 15.53 | 15.5 | 12.98 | 15.53 | 15.5 | 12.98 | 15.53 | 155 | 1298
1 | LTC1754ES6-5#TRMPBF | Linear Technology | LTC1754ES6-5#TRMPBF | 1 | 10 | 100 | LTC1754ES6-5#TRMPBFDKR-ND |  | 56M3715 | 3.46 |  |  | 3.46 |  |  | 2.7813 |  |  | Digi-Key | LTC1754ES6-5#TRMPBFDKR-ND | 3.46 | 3.46 | 2.7813 | 3.46 | 3.46 | 2.7813 | 3.46 | 34.6 | 278.13
1 | ABS07-32.768KHZ-1-T | Abracon | ABS07-32.768KHZ-1-T | 1 | 10 | 100 | 535-9808-1-ND | ABS07-32.768KHZ-1-T | 11N6974 | 1.28 | 1.28 |  | 1.137 | 1.13 |  | 0.94 | 1.06 |  | Future Electronics | ABS07-32.768KHZ-1-T | 0.6778 | 0.6778 | 0.6778 | 0.6778 | 0.6778 | 0.6778 | 0.6778 | 6.778 | 67.78
1 | ABLS-8.000MHZ-B4-T | Abracon | ABLS-8.000MHZ-B4-T | 1 | 10 | 100 | 535-10212-1-ND | ABLS-8.000MHZ-B4-T | 47W0860 | 0.35 | 0.33 |  | 0.289 | 0.267 |  | 0.231 | 0.252 |  | Mouser | ABLS-8.000MHZ-B4-T | 0.33 | 0.267 | 0.231 | 0.33 | 0.267 | 0.231 | 0.33 | 2.67 | 23.1

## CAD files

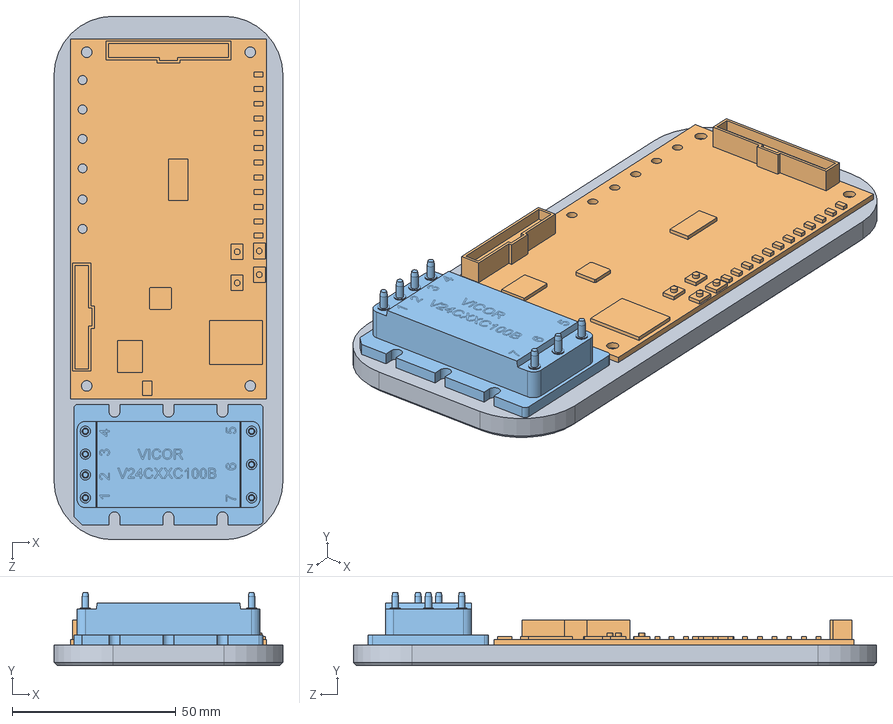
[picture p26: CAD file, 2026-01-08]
design-source/mechanical/solidworks/plate_assembly.SLDASM
70.0 x 22.4 x 160.0 mm
plate
bms_v01
vicor_v24cxxc100b

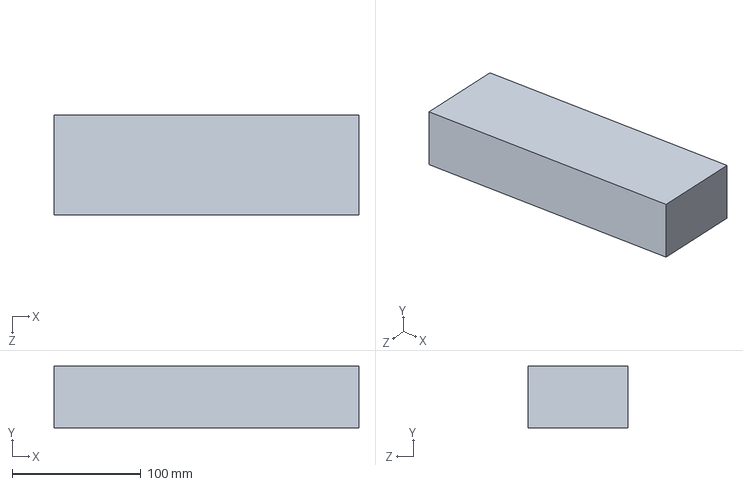
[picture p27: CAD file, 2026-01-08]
design-source/mechanical/solidworks/charger.SLDPRT
237.0 x 48.0 x 78.0 mm

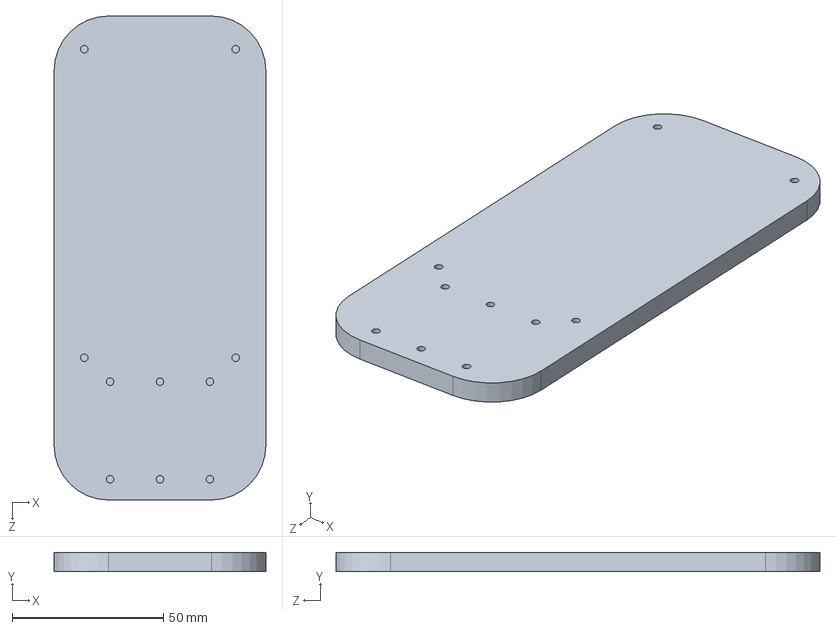
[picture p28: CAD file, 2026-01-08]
design-source/mechanical/solidworks/plate.SLDPRT
70.0 x 6.35 x 160.0 mm

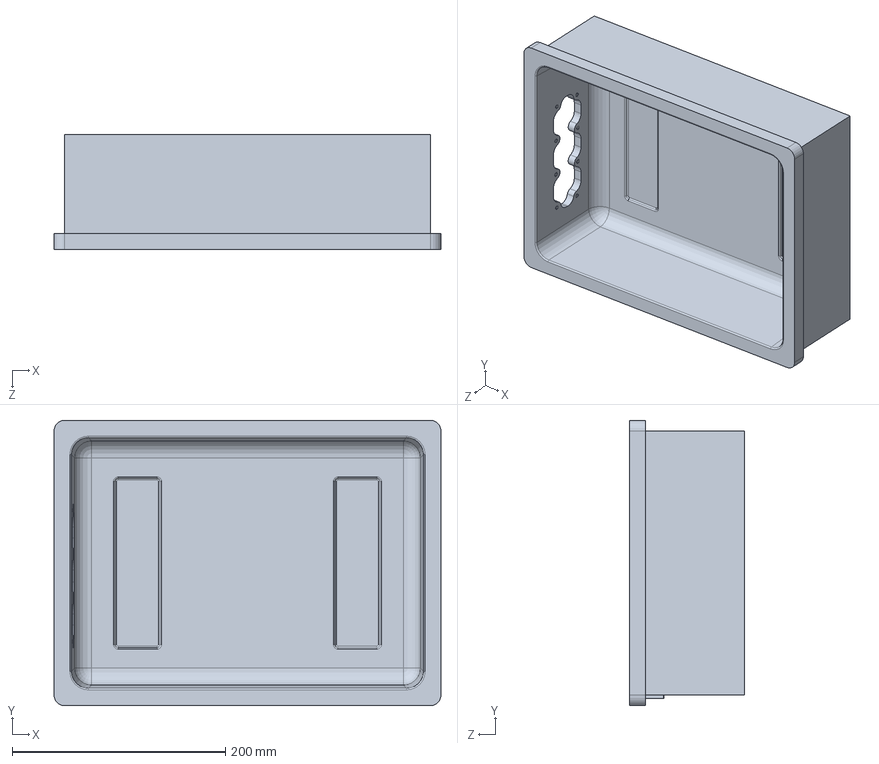
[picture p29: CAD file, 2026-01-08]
design-source/mechanical/solidworks/im2100_bottom.prt.SLDPRT
362.9 x 267.6 x 108.0 mm

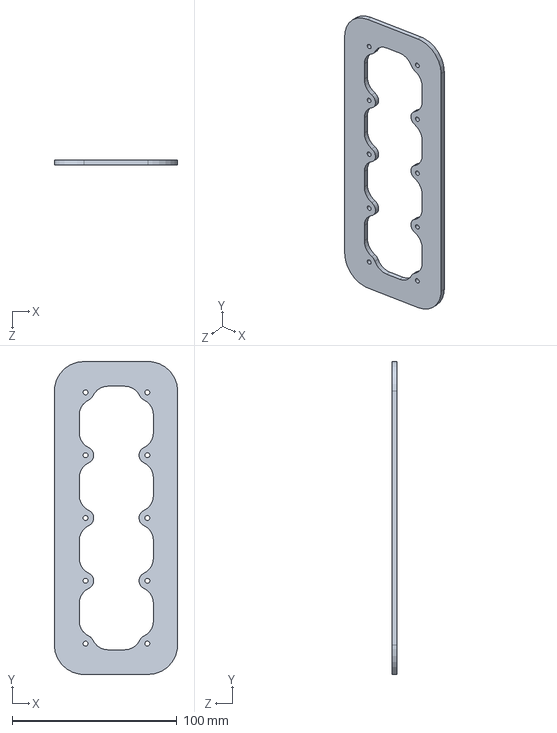
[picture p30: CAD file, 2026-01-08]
design-source/mechanical/solidworks/external_plate.SLDPRT
75.0 x 190.0 x 3.17 mm

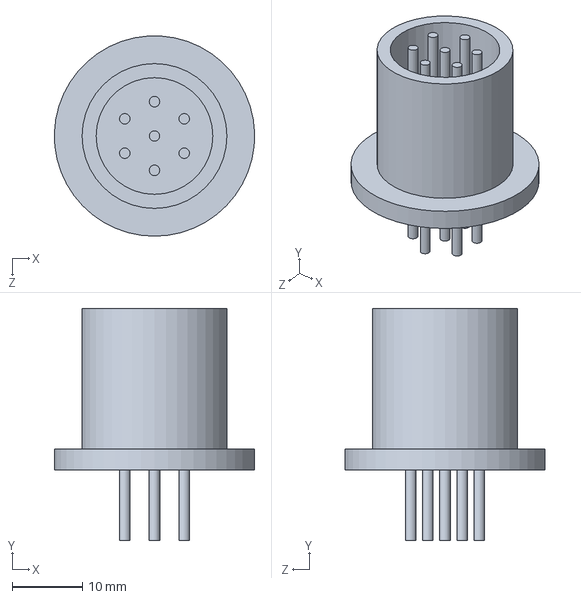
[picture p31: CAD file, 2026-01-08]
design-source/mechanical/solidworks/JR16WRA-7P.SLDPRT
28.5 x 33.0 x 28.5 mm

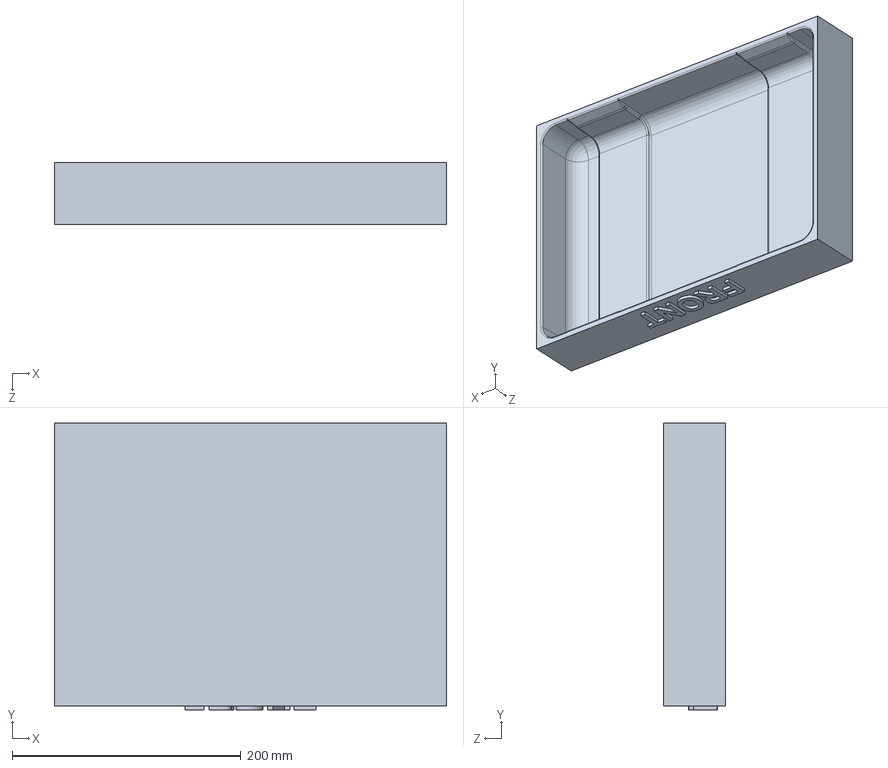
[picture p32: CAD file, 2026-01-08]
design-source/mechanical/solidworks/2100-lid_internal_tub.SLDPRT
342.9 x 250.8 x 54.0 mm

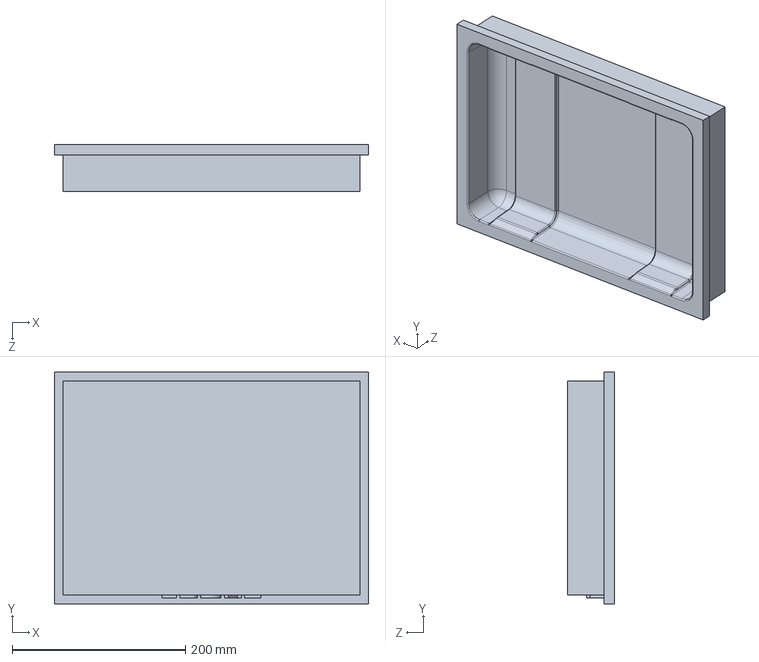
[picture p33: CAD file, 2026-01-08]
design-source/mechanical/solidworks/im2100_top.SLDPRT
362.9 x 267.6 x 54.0 mm

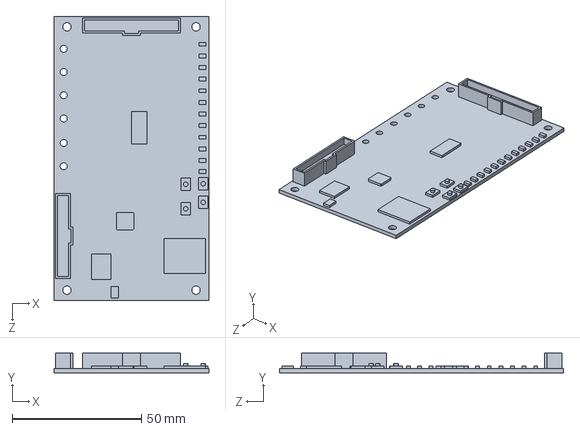
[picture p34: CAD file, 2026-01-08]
design-source/mechanical/solidworks/bms_v01.SLDPRT
60.0 x 7.57 x 110.0 mm

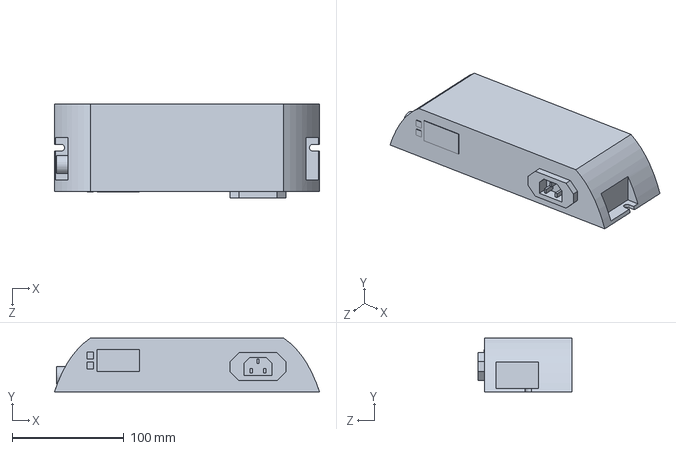
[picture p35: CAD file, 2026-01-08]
design-source/mechanical/solidworks/cycle_satiator.SLDPRT
237.0 x 48.0 x 84.0 mm

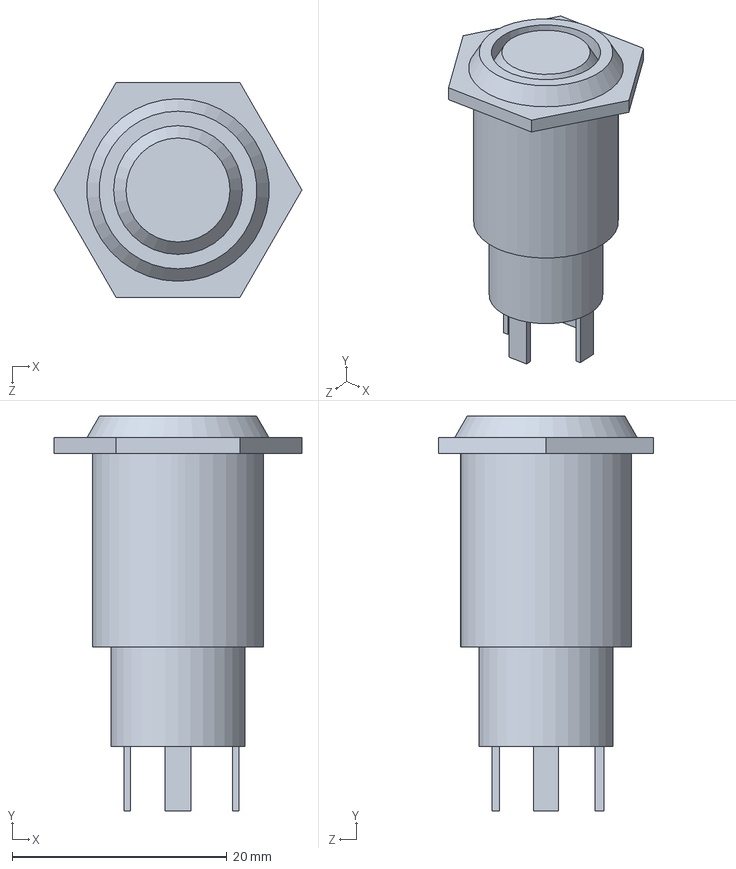
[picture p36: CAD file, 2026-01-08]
design-source/mechanical/solidworks/PV3W_switch.SLDPRT
23.1 x 36.8 x 20.0 mm

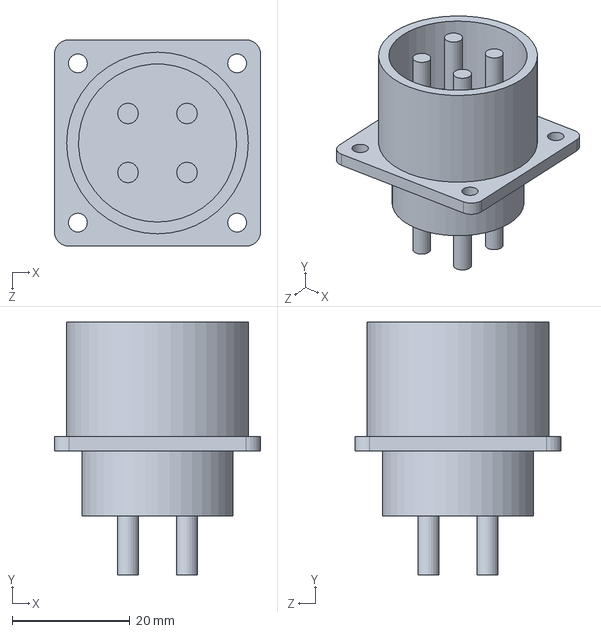
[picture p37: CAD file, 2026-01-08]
design-source/mechanical/solidworks/CA02COME18-10SB01.SLDPRT
35.0 x 42.9 x 35.0 mm

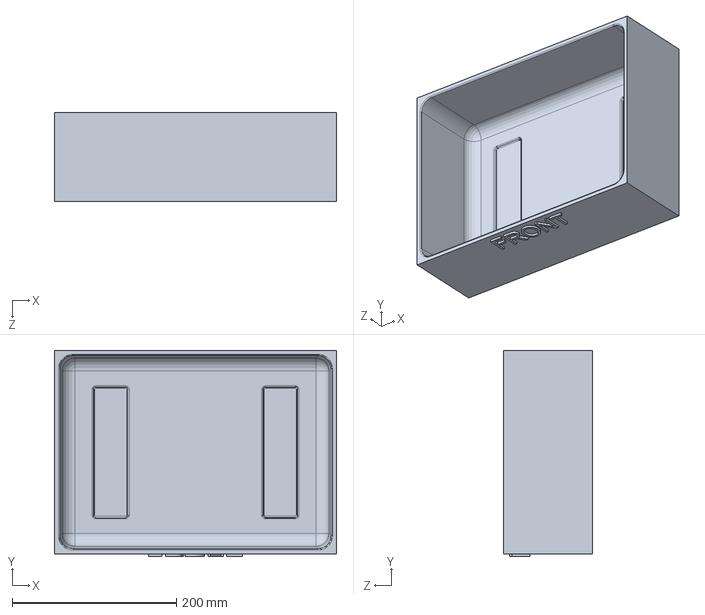
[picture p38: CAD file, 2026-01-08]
design-source/mechanical/solidworks/2100-base_internal_tub.SLDPRT
342.9 x 250.8 x 108.0 mm

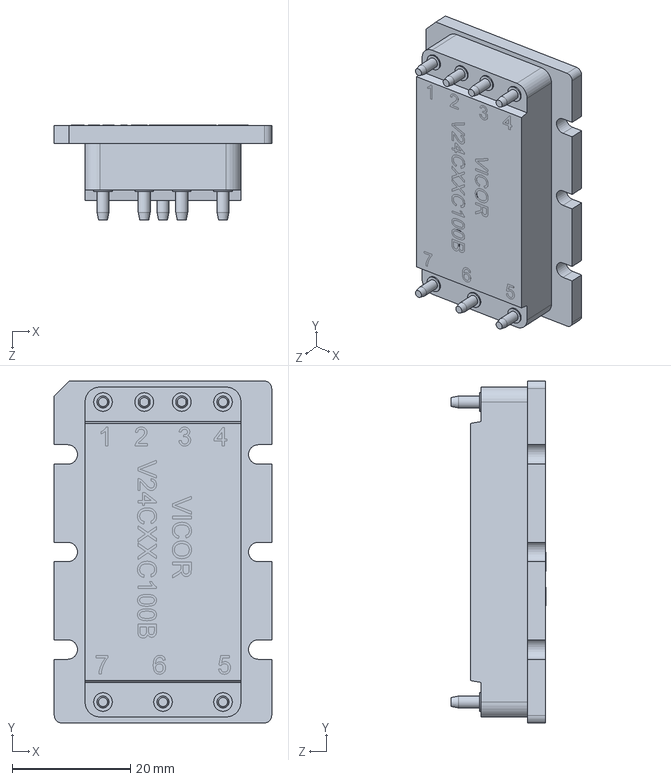
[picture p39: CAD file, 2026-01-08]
design-source/mechanical/solidworks/vicor_v24cxxc100b.SLDPRT
36.8 x 57.9 x 16.0 mm

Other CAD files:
design-source/mechanical/solidworks/18650.SLDPRT
design-source/mechanical/solidworks/plate.SLDDRW

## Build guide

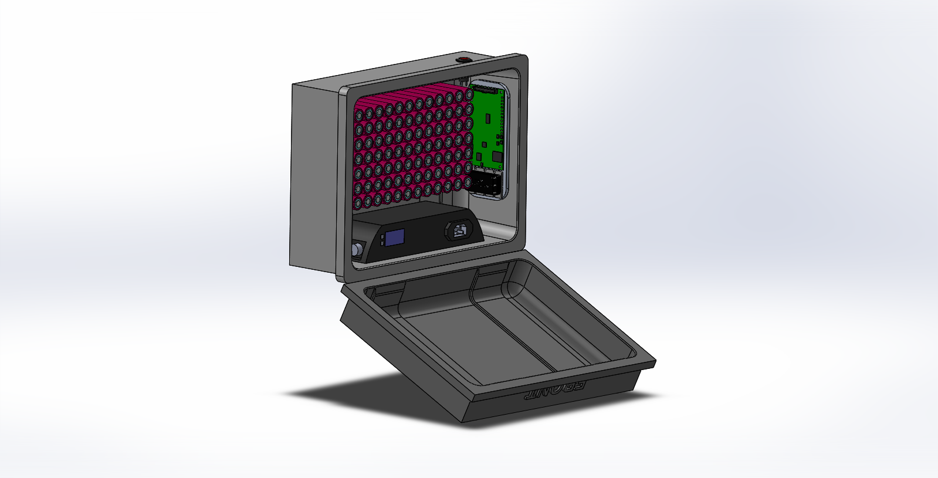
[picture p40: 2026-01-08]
design-source/mechanical/renders/im2100_assembly_03.PNG

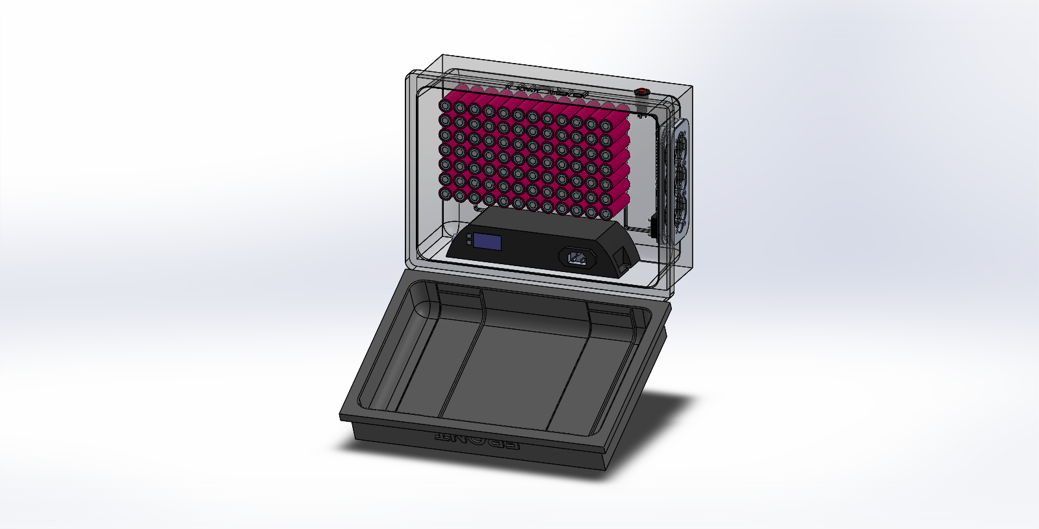
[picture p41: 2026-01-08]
design-source/mechanical/renders/im2100_assembly_01.PNG

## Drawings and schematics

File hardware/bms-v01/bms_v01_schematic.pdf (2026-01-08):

STM32 Microcontroller | microSD Card Interface

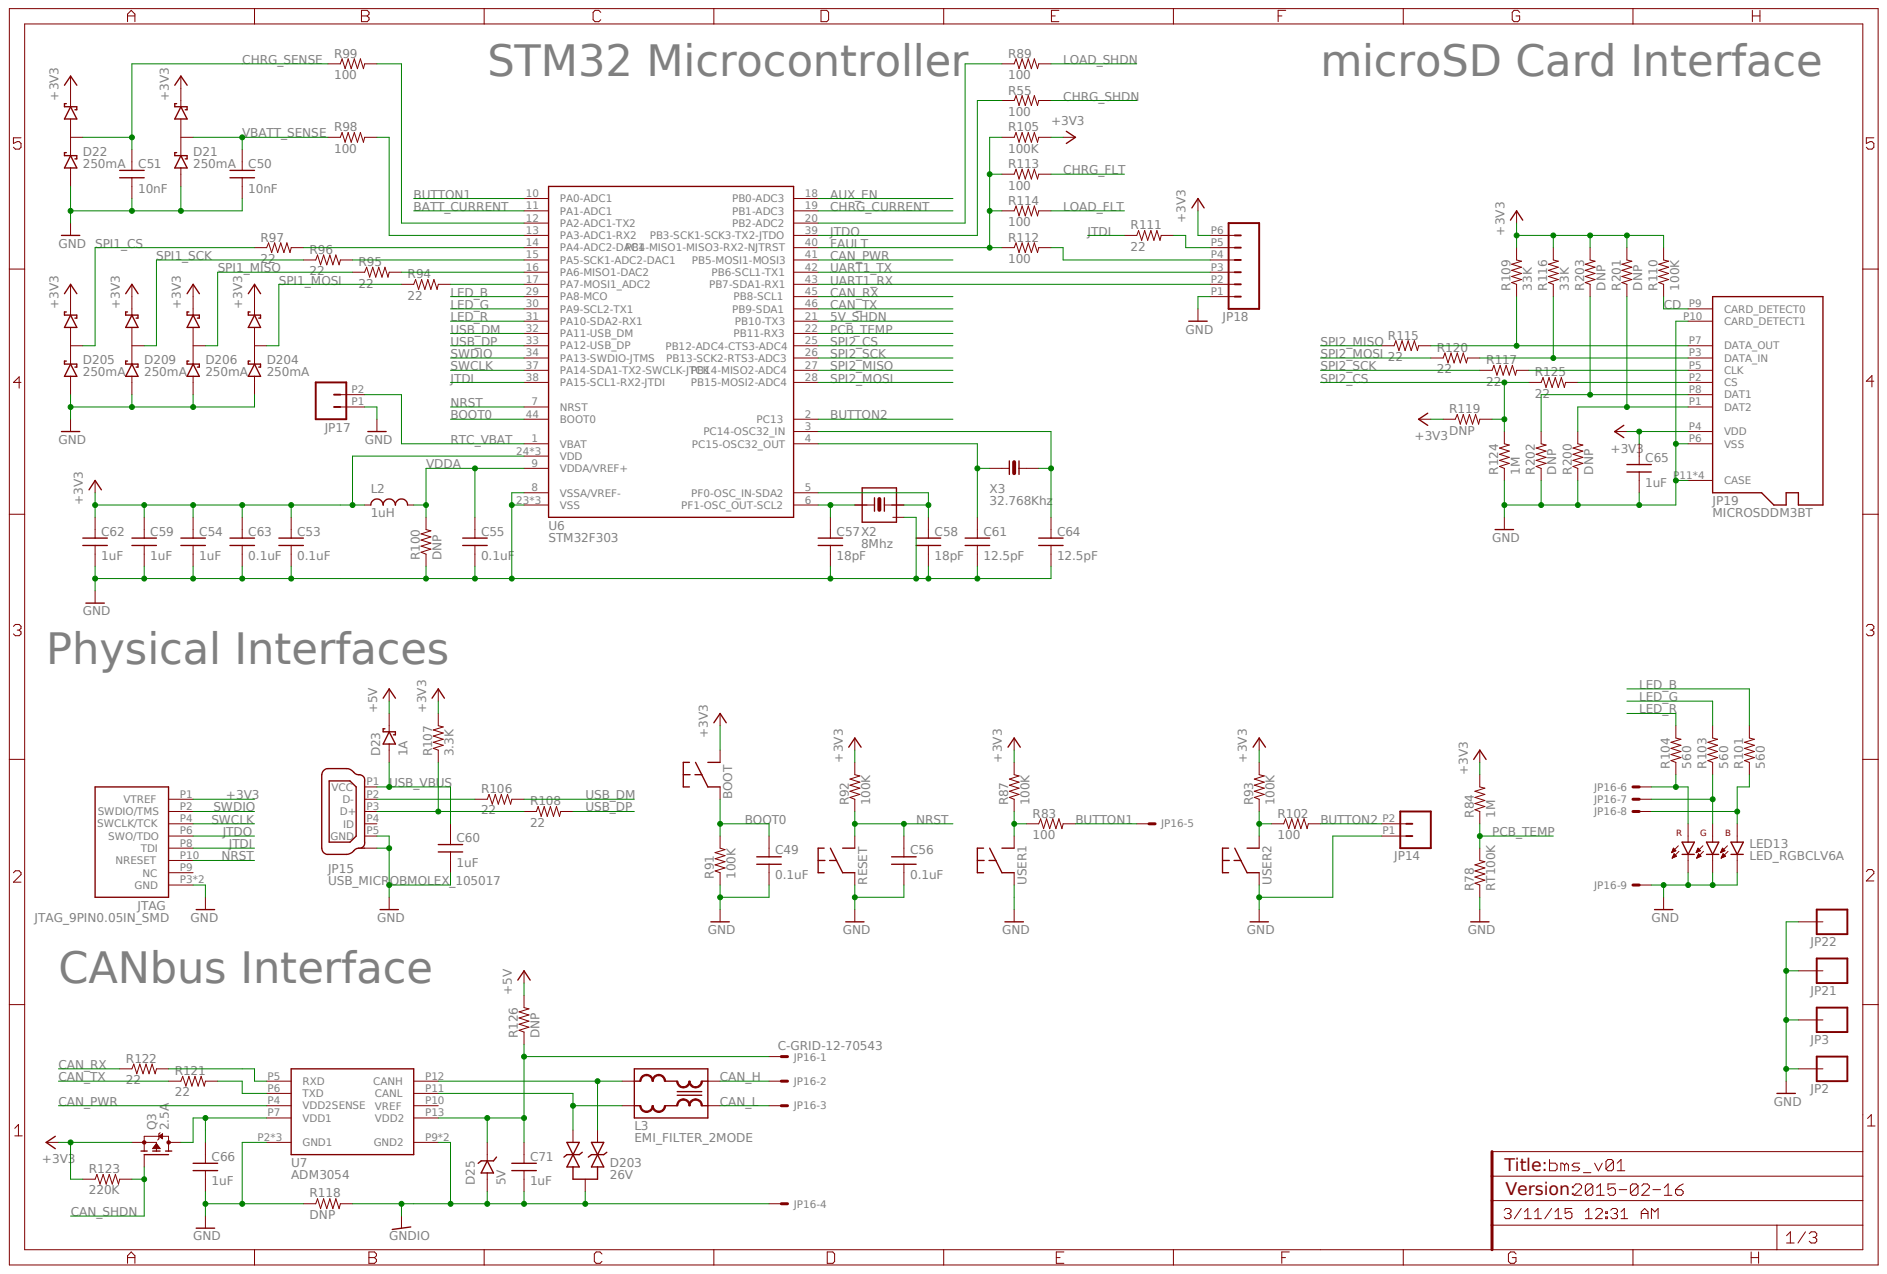
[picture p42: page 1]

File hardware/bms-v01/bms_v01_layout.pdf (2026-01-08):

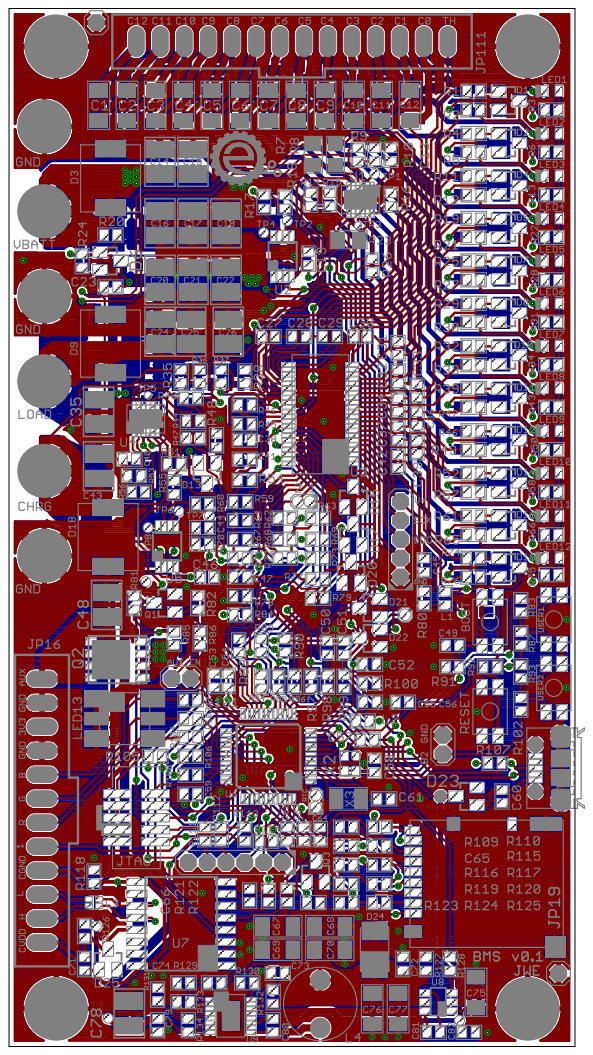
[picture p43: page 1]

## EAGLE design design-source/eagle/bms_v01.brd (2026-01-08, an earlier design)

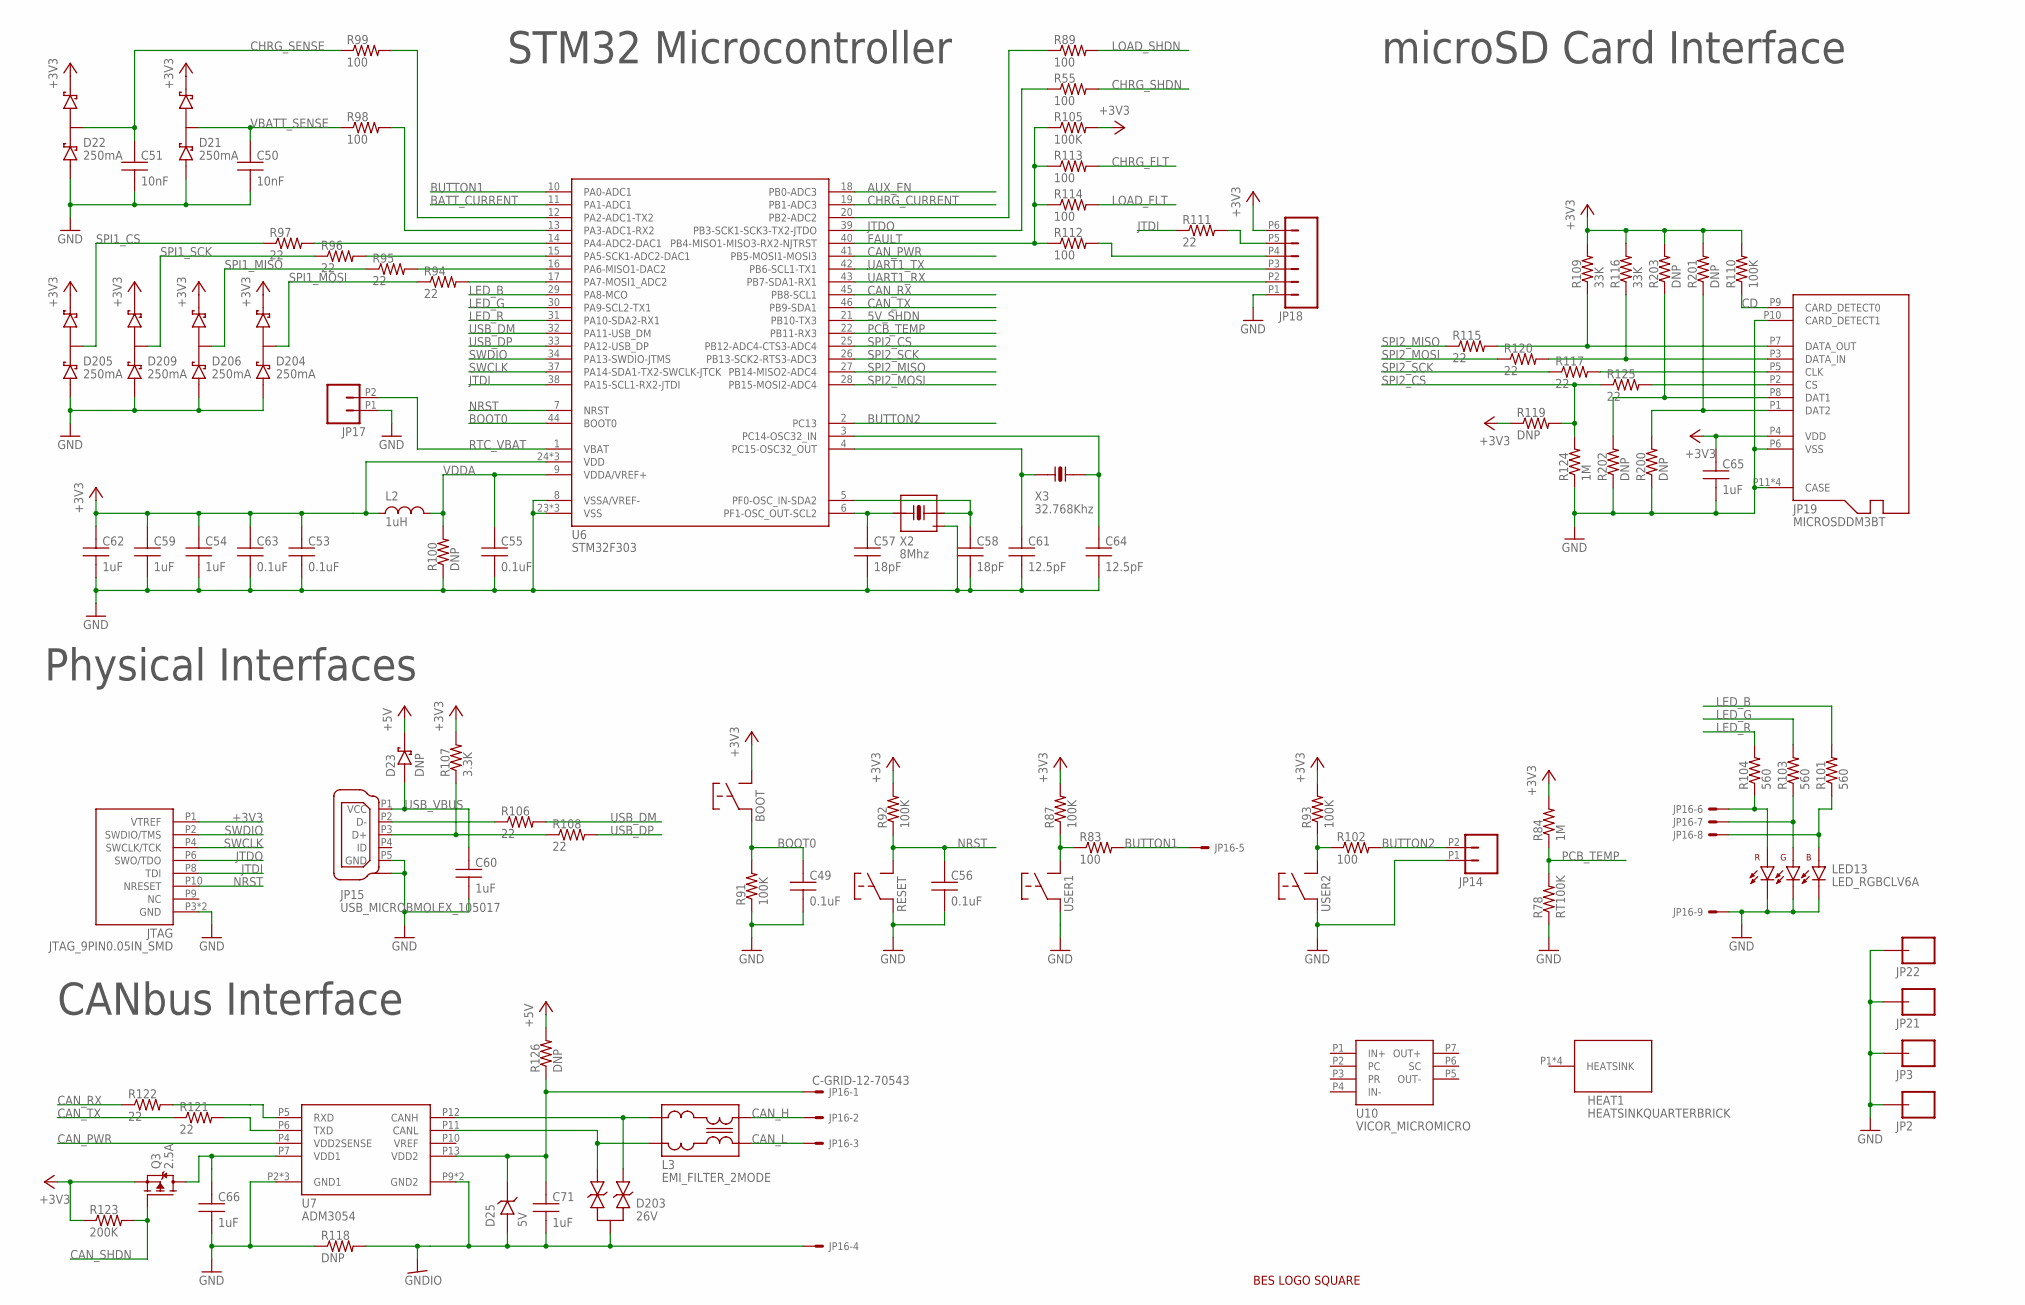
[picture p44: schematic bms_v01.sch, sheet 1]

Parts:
BOOT: SWITCH_MOMENTEVQP2; MOMENTARY_SW_EVQP2
C49, C53, C55, C56, C63: 0.1uF; 0603_SILK
C50, C51: 10nF; 0603_SILK
C54, C59, C60, C62, C65, C66, C71: 1uF; 0603_SILK
C57, C58: 18pF; 0603_SILK
C61, C64: 12.5pF; 0603_SILK
D21, D22, D204, D205, D206, D209: 250mA; SOT23
D23: DNP; SOT23
D25: 5V; SOT23
D203: 26V; SOT23
HEAT1: HEATSINKQUARTERBRICK; HEATSINK_BRICK_QUARTER
JP2, JP3, JP21, JP22: CONNECTOR-1PIN3.5MM; HOLE_3.5MM
JP14: HEADER-2PIN2MM; HEADER_2MM_2PIN
JP15: USB_MICROBMOLEX_105017; USB-MICRO-B-MOLEX_105017
JP16: C-GRID-12-70543; 70543-12
JP17: HEADER-2PIN0.05IN; HEADER-SMALL-2PIN00.05IN
JP18: HEADER-6PIN2MM; HEADER_2MM_6PIN
JP19: MICROSDDM3BT; MICROSD_DM3BT
JTAG: JTAG_9PIN0.05IN_SMD; JTAG_9PIN_0.05IN_SMD
L2: 1uH; 0603_SILK
L3: EMI_FILTER_2MODE; FILTER_EXC24CX
LED13: LED_RGBCLV6A; RGB_LED_CLV6A
LOGO1: LOGOSILK_0.325IN; LOGO_SILK_0.325IN
Q3: 2.5A; SOT23
R55, R83, R89, R98, R99, R102, R112, R113, R114: 100; 0603_SILK
R78: RT100K; 0603_SILK
R84, R124: 1M; 0603_SILK
R87, R91, R92, R93, R105, R110: 100K; 0603_SILK
R94, R95, R96, R97, R106, R108, R111, R115, R117, R120, R121, R122, R125: 22; 0603_SILK
R100, R118, R119, R126, R200, R201, R202, R203: DNP; 0603_SILK
R101, R103, R104: 560; 0603_SILK
R107: 3.3K; 0603_SILK
R109, R116: 33K; 0603_SILK
R123: 200K; 0603_SILK
RESET: SWITCH_MOMENTEVQP2; MOMENTARY_SW_EVQP2
U6: STM32F303; TQFP48
U7: ADM3054; SOIC-16_W_ANALOG
U10: VICOR_MICROMICRO; VICOR_QUARTER
USER1, USER2: SWITCH_MOMENTEVQP2; MOMENTARY_SW_EVQP2
X2: 8Mhz; ABRACOM_CLOCK
X3: 32.768Khz; ABS07

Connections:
5V_SHDN: U6.21 (PB10-TX3); also elsewhere on the board
+3V3: BOOT.P2, BOOT.P4 (P2), C53.P1 (1), C54.P1 (1), C59.P1 (1), C62.P1 (1), C63.P1 (1), C65.P1 (1), D21.2 (C), D22.2 (C), D204.2 (C), D205.2 (C), D206.2 (C), D209.2 (C), JP18.P6, JP19.P4 (VDD), JTAG.P1 (VTREF), L2.P1 (1), Q3.2 (S), R84.P2 (2), R87.P2 (2), R92.P2 (2), R93.P2 (2), R105.P2 (2), R107.P2 (2), R109.P2 (2), R110.P2 (2), R116.P2 (2), R119.P1 (1), R123.P1 (1), R201.P2 (2), R203.P2 (2), U6.24 (VDD), U6.36 (VDD), U6.48 (VDD); also elsewhere on the board
+5V: D23.3 (C), R126.P2 (2); also elsewhere on the board
AUX_EN: U6.18 (PB0-ADC3); also elsewhere on the board
BATT_CURRENT: U6.11 (PA1-ADC1); also elsewhere on the board
BOOT0: BOOT.P1, BOOT.P3 (P1), C49.P1 (1), R91.P2 (2), U6.44 (BOOT0)
BUTTON1: JP16.5, R83.P2 (2), U6.10 (PA0-ADC1)
BUTTON2: JP14.P2, R102.P2 (2), U6.2 (PC13)
CAN_H: JP16.2, L3.P4 (4)
CAN_L: JP16.3, L3.P3 (3)
CAN_PWR: U6.41 (PB5-MOSI1-MOSI3), U7.P4 (VDD2SENSE)
CAN_RX: R122.P1 (1), U6.45 (PB8-SCL1)
CAN_SHDN: Q3.1 (G), R123.P2 (2); also elsewhere on the board
CAN_TX: R121.P1 (1), U6.46 (PB9-SDA1)
CAN_VDD: C71.P1 (1), D25.3 (C), JP16.1, R126.P1 (1), U7.P13 (VDD2)
CD: JP19.P9 (CARD_DETECT0), R110.P1 (1)
CHRG_CURRENT: U6.19 (PB1-ADC3); also elsewhere on the board
CHRG_FLT: R113.P2 (2); also elsewhere on the board
CHRG_SENSE: C51.P1 (1), D22.3 (MID), R99.P1 (1); also elsewhere on the board
CHRG_SHDN: R55.P2 (2); also elsewhere on the board
FAULT: R105.P1 (1), R112.P1 (1), R113.P1 (1), R114.P1 (1), U6.40 (PB4-MISO1-MISO3-RX2-NJTRST)
GND: C49.P2 (2), C50.P2 (2), C51.P2 (2), C53.P2 (2), C54.P2 (2), C55.P2 (2), C56.P2 (2), C57.P2 (2), C58.P2 (2), C59.P2 (2), C60.P2 (2), C61.P2 (2), C62.P2 (2), C63.P2 (2), C64.P2 (2), C65.P2 (2), C66.P2 (2), D21.1 (A), D22.1 (A), D204.1 (A), D205.1 (A), D206.1 (A), D209.1 (A), JP2.P$1, JP3.P$1, JP14.P1, JP15.P5 (GND), JP15.PAD1 (CASE), JP15.PAD2 (CASE), JP15.PAD3 (CASE), JP15.PAD3-HOLE (CASE), JP15.PAD4 (CASE), JP15.PAD4-HOLE (CASE), JP15.THRUPAD1 (CASE), JP15.THRUPAD2 (CASE), JP16.9, JP17.P1, JP18.P1, JP19.P6 (VSS), JP19.P10 (CARD_DETECT1), JP19.P11 (CASE), JP19.P12 (CASE), JP19.P13 (CASE), JP19.P14 (CASE), JP21.P$1, JP22.P$1, JTAG.P3 (GND), JTAG.P5 (GND), LED13.1 (BC), LED13.2 (GC), LED13.3 (RC), R78.P1 (1), R91.P1 (1), R100.P1 (1), R118.P1 (1), R124.P1 (1), R200.P1 (1), R202.P1 (1), RESET.P1, RESET.P3 (P1), U6.8 (VSSA/VREF-), U6.23 (VSS), U6.35 (VSS), U6.47 (VSS), U7.P2 (GND1), U7.P3 (GND1), U7.P8 (GND1), USER1.P1, USER1.P3 (P1), USER2.P1, USER2.P3 (P1), X2.2 (CASE), X2.4 (CASE); also elsewhere on the board
GNDIO: C71.P2 (2), D25.1 (A), D203.3 (C1), JP16.4, R118.P2 (2), U7.P9 (GND2), U7.P16 (GND2)
JTDI: JTAG.P8 (TDI), R111.P1 (1), U6.38 (PA15-SCL1-RX2-JTDI)
JTDO: JTAG.P6 (SWO/TDO), R55.P1 (1), U6.39 (PB3-SCK1-SCK3-TX2-JTDO)
LED_B: R101.P2 (2), U6.29 (PA8-MCO)
LED_G: R103.P2 (2), U6.30 (PA9-SCL2-TX1)
LED_R: R104.P2 (2), U6.31 (PA10-SDA2-RX1)
LOAD_FLT: R114.P2 (2); also elsewhere on the board
LOAD_SHDN: R89.P2 (2); also elsewhere on the board
unnamed: C66.P1 (1), Q3.3 (D), U7.P7 (VDD1)
unnamed: D203.1 (A), L3.P2 (2), U7.P11 (CANL)
unnamed: R99.P2 (2), U6.12 (PA2-ADC1-TX2)
unnamed: R83.P1 (1), R87.P1 (1), USER1.P2, USER1.P4 (P2)
unnamed: JP15.P2 (D-), R106.P1 (1)
unnamed: R93.P1 (1), R102.P1 (1), USER2.P2, USER2.P4 (P2)
unnamed: R89.P1 (1), U6.20 (PB2-ADC2)
unnamed: R98.P2 (2), U6.13 (PA3-ADC1-RX2)
unnamed: C58.P1 (1), U6.5 (PF0-OSC_IN-SDA2), X2.3 (3A)
unnamed: JP15.P3 (D+), R107.P1 (1), R108.P1 (1)
unnamed: R94.P2 (2), U6.17 (PA7-MOSI1_ADC2)
unnamed: R95.P2 (2), U6.16 (PA6-MISO1-DAC2)
unnamed: C57.P1 (1), U6.6 (PF1-OSC_OUT-SCL2), X2.1 (1A)
unnamed: R96.P2 (2), U6.15 (PA5-SCK1-ADC2-DAC1)
unnamed: JP19.P1 (DAT2), R200.P2 (2), R201.P1 (1)
unnamed: JP19.P8 (DAT1), R202.P2 (2), R203.P1 (1)
unnamed: JP19.P3 (DATA_IN), R116.P1 (1), R120.P2 (2)
unnamed: JP19.P7 (DATA_OUT), R109.P1 (1), R115.P2 (2)
unnamed: D203.2 (A1), L3.P1 (1), U7.P12 (CANH)
unnamed: R121.P2 (2), U7.P6 (TXD)
unnamed: R122.P2 (2), U7.P5 (RXD)
unnamed: R97.P2 (2), U6.14 (PA4-ADC2-DAC1)
unnamed: C61.P1 (1), U6.4 (PC15-OSC32_OUT), X3.P1 (1A)
unnamed: C64.P1 (1), U6.3 (PC14-OSC32_IN), X3.P2 (3A)
unnamed: JP18.P4, R112.P2 (2)
unnamed: JP18.P5, R111.P2 (2)
unnamed: JP19.P5 (CLK), R117.P2 (2)
unnamed: JP19.P2 (CS), R125.P2 (2)
unnamed: JP16.6, LED13.4 (RA), R104.P1 (1)
unnamed: JP16.7, LED13.5 (GA), R103.P1 (1)
unnamed: JP16.8, LED13.6 (BA), R101.P1 (1)
NRST: C56.P1 (1), JTAG.P10 (NRESET), R92.P1 (1), RESET.P2, RESET.P4 (P2), U6.7 (NRST)
PCB_TEMP: R78.P2 (2), R84.P1 (1), U6.22 (PB11-RX3)
RTC_VBAT: JP17.P2, U6.1 (VBAT)
SPI1_CS: D205.3 (MID), R97.P1 (1); also elsewhere on the board
SPI1_MISO: D206.3 (MID), R95.P1 (1); also elsewhere on the board
SPI1_MOSI: D204.3 (MID), R94.P1 (1); also elsewhere on the board
SPI1_SCK: D209.3 (MID), R96.P1 (1); also elsewhere on the board
SPI2_CS: R119.P2 (2), R124.P2 (2), R125.P1 (1), U6.25 (PB12-ADC4-CTS3-ADC4)
SPI2_MISO: R115.P1 (1), U6.27 (PB14-MISO2-ADC4)
SPI2_MOSI: R120.P1 (1), U6.28 (PB15-MOSI2-ADC4)
SPI2_SCK: R117.P1 (1), U6.26 (PB13-SCK2-RTS3-ADC3)
SWCLK: JTAG.P4 (SWCLK/TCK), U6.37 (PA14-SDA1-TX2-SWCLK-JTCK)
SWDIO: JTAG.P2 (SWDIO/TMS), U6.34 (PA13-SWDIO-JTMS)
UART1_RX: JP18.P2, U6.43 (PB7-SDA1-RX1)
UART1_TX: JP18.P3, U6.42 (PB6-SCL1-TX1)
USB_DM: R106.P2 (2), U6.32 (PA11-USB_DM)
USB_DP: R108.P2 (2), U6.33 (PA12-USB_DP)
USB_VBUS: C60.P1 (1), D23.1 (A), JP15.P1 (VCC)
VBATT_SENSE: C50.P1 (1), D21.3 (MID), R98.P1 (1); also elsewhere on the board
VDDA: C55.P1 (1), L2.P2 (2), R100.P2 (2), U6.9 (VDDA/VREF+)

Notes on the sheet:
CANbus Interface
STM32 Microcontroller
microSD Card Interface
Physical Interfaces

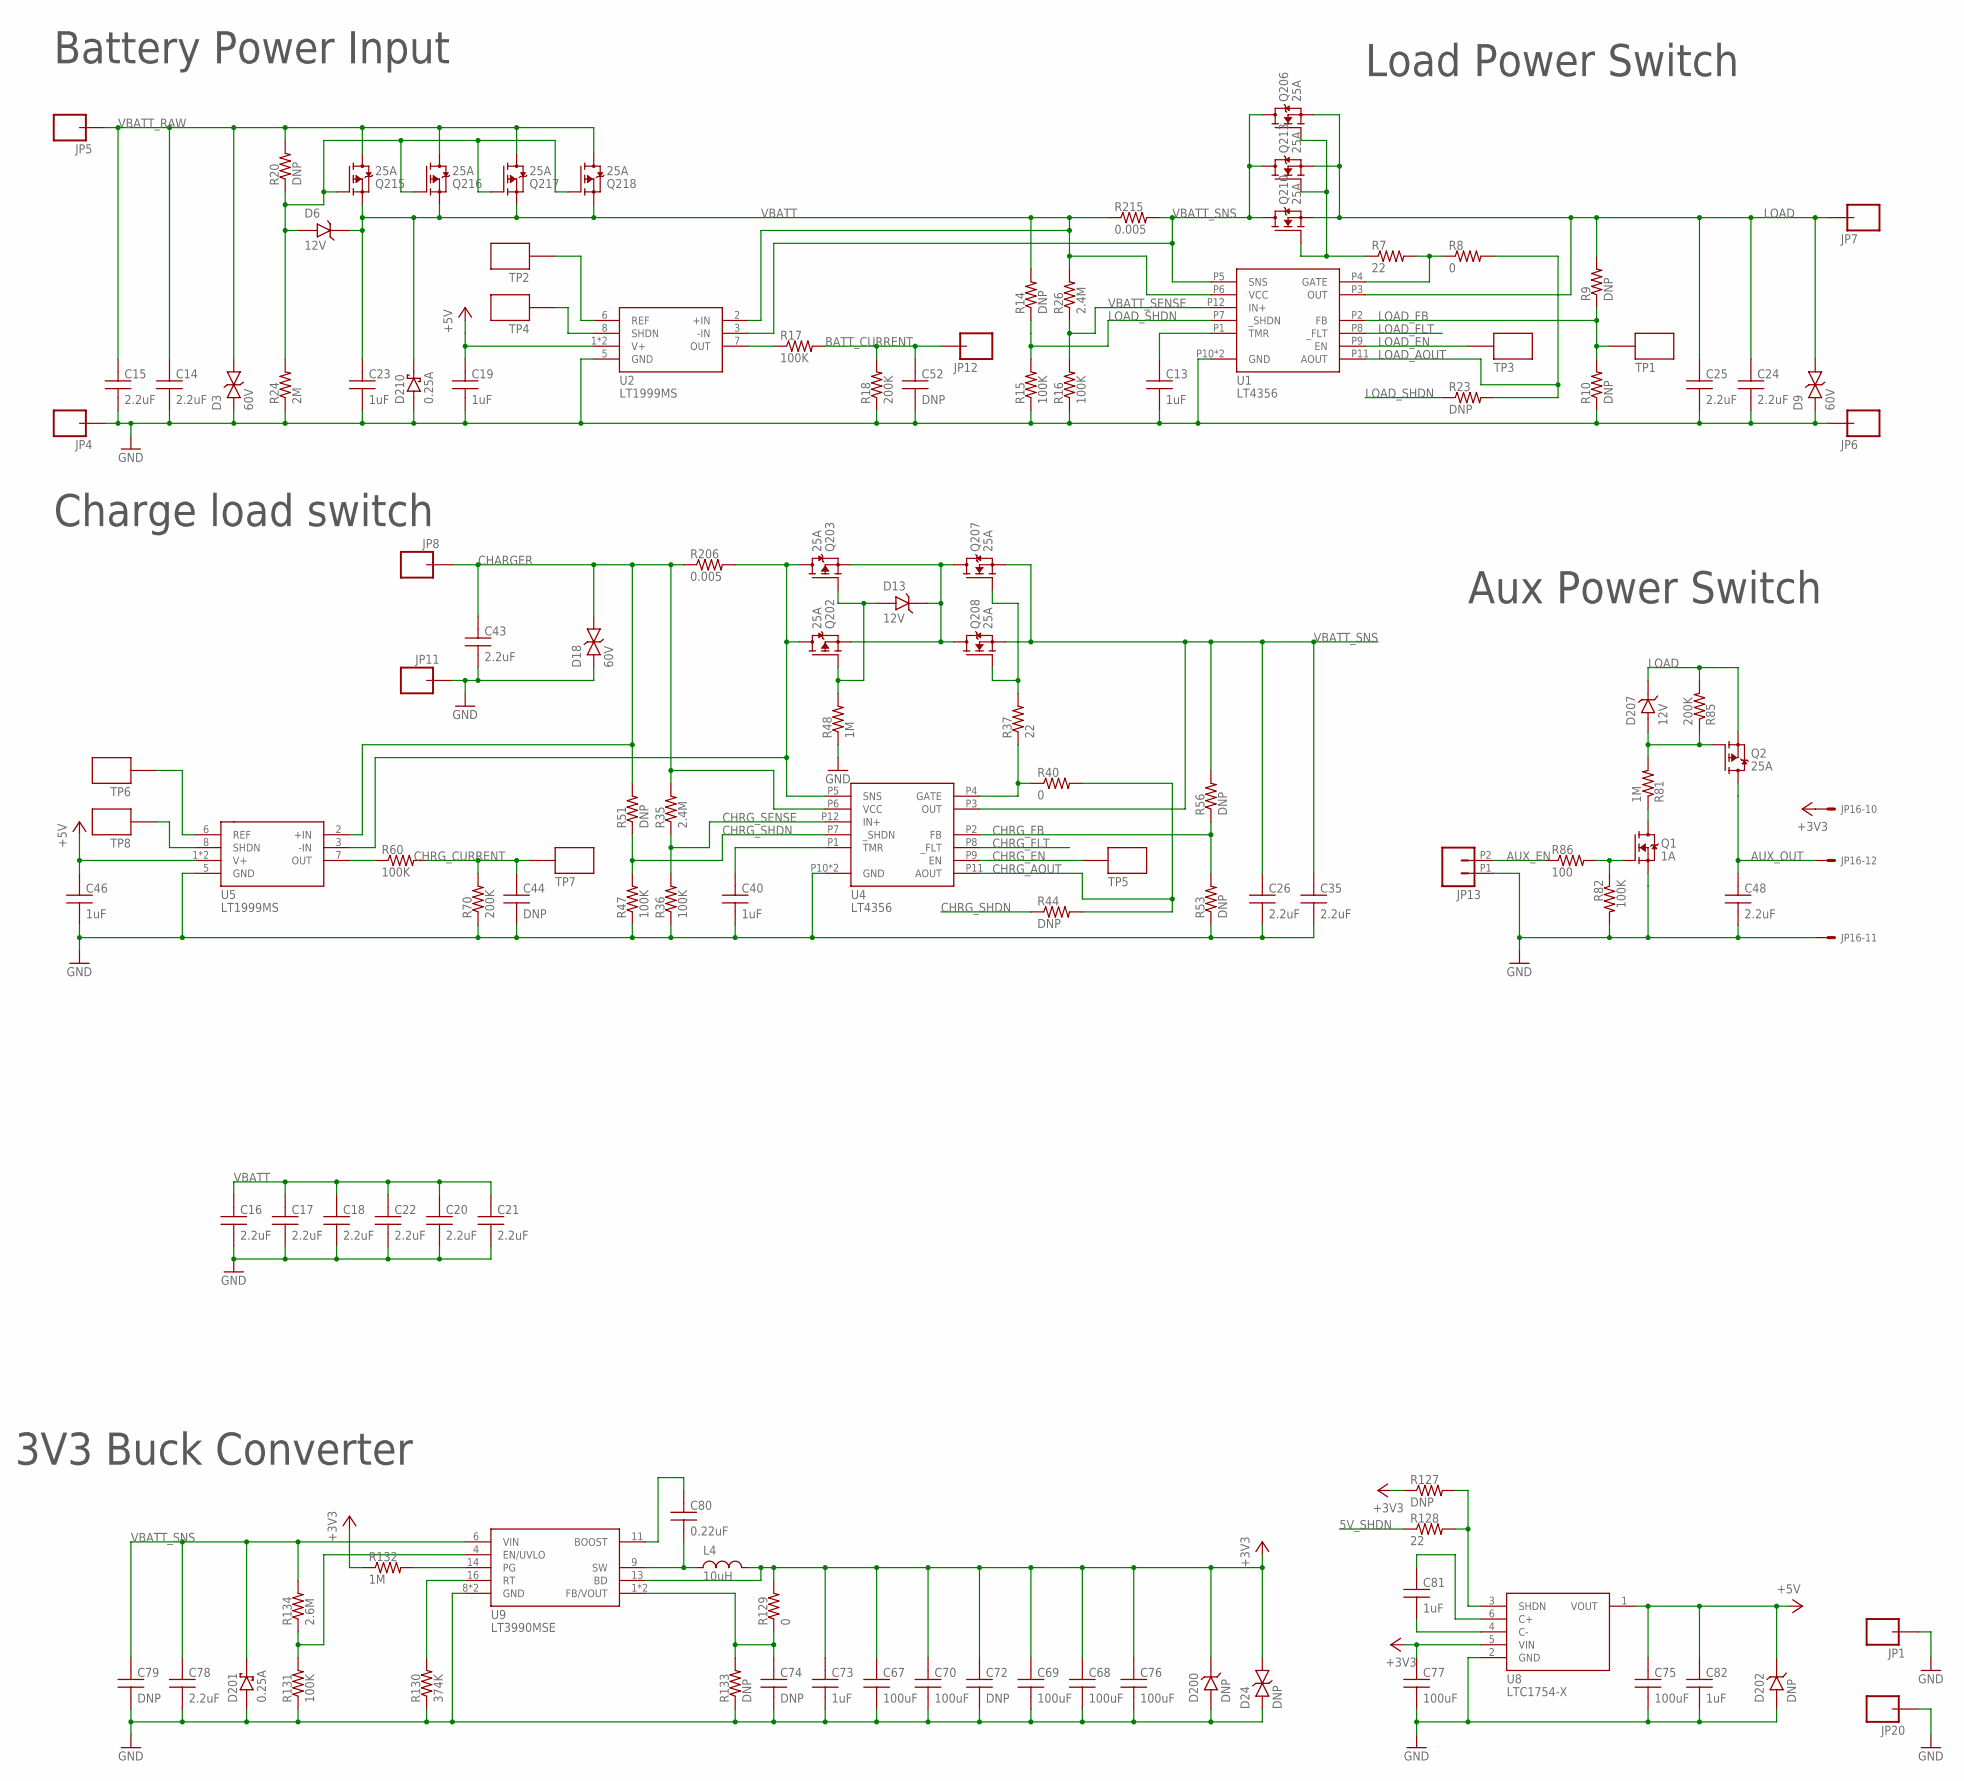
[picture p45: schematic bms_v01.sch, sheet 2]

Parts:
C13, C19, C23, C40, C46, C73, C81, C82: 1uF; 0603_SILK
C14, C15, C16, C17, C18, C20, C21, C22, C24, C25, C26, C35, C43, C48, C78: 2.2uF; 1210_SILK
C44, C52, C72, C74, C79: DNP; 0603_SILK
C67, C68, C69, C70, C75, C76, C77: 100uF; 1206_SILK
C80: 0.22uF; 0603_SILK
D3, D9, D18: 60V; SMC
D6, D13, D207: 12V; SOT23
D24: DNP; SMA
D200, D202: DNP; SOT23
D201, D210: 0.25A; SOT23
JP1, JP20: HEADER-1PIN0.036IN; HEADER-SMALL-1PIN-0.036IN
JP4, JP5, JP6, JP7, JP8, JP11: CONNECTOR-1PIN3MM; HOLE_3MM
JP12: HEADER-1PIN0.02IN; HEADER-SMALL-1PIN-0.02IN
JP13: HEADER-2PIN2MM; HEADER_2MM_2PIN
JP16: C-GRID-12-70543; 70543-12
L4: 10uH; INDUCTOR_RL895
Q1: 1A; SOT23
Q2, Q202, Q203, Q206, Q207, Q208, Q210, Q213, Q215, Q216, Q217, Q218: 25A; POWERPAK_SO-8_SINGLE
R7: 22; 0805_SILK
R8: 0; 0805_SILK
R9, R10, R14, R20, R44, R51, R53, R56, R127, R133: DNP; 0603_SILK
R15, R16, R17, R36, R47, R60, R82, R131: 100K; 0603_SILK
R18, R70, R85: 200K; 0603_SILK
R23: DNP; 0805_SILK
R24: 2M; 0603_SILK
R26, R35: 2.4M; 0603_SILK
R37, R128: 22; 0603_SILK
R40, R129: 0; 0603_SILK
R48, R81, R132: 1M; 0603_SILK
R86: 100; 0603_SILK
R130: 374K; 0603_SILK
R134: 2.6M; 0603_SILK
R206, R215: 0.005; 2725_SILK
TP1, TP2, TP4, TP6, TP7, TP8: TEST_POINT0.036IN; TEST_POINT_0.036IN
TP3, TP5: TEST_POINT0.025IN; TEST_POINT_0.025IN
U1, U4: LT4356; DFN12
U2, U5: LT1999MS; MSOP-8_LT
U8: LTC1754-X; SOT23-6
U9: LT3990MSE; 17_MSOP

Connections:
5V_SHDN: R128.P1 (1); also elsewhere on the board
+3V3: C67.P1 (1), C68.P1 (1), C69.P1 (1), C70.P1 (1), C72.P1 (1), C73.P1 (1), C76.P1 (1), C77.P1 (1), D24.C, D200.3 (C), JP16.10, L4.P2 (2), R127.P1 (1), R129.P2 (2), R132.P1 (1), U8.5 (VIN), U9.13 (BD); also elsewhere on the board
+5V: C19.P1 (1), C46.P1 (1), C75.P1 (1), C82.P1 (1), D202.3 (C), U2.1 (V+), U2.4 (V+), U5.1 (V+), U5.4 (V+), U8.1 (VOUT); also elsewhere on the board
AUX_EN: JP13.P2, R86.P1 (1); also elsewhere on the board
AUX_OUT: C48.1, JP16.12, Q2.5D (D), Q2.6D (D), Q2.7D (D), Q2.8D (D), Q2.9D (D)
BATT_CURRENT: C52.P1 (1), JP12.P1, R17.P2 (2), R18.P2 (2); also elsewhere on the board
CHARGER: C43.1, D18.C, JP8.P1, R35.P2 (2), R51.P2 (2), R206.P1 (1), U4.P6 (VCC), U5.2 (+IN)
CHARGER_SENSE: Q202.5D (D), Q202.6D (D), Q202.7D (D), Q202.8D (D), Q202.9D (D), Q203.5D (D), Q203.6D (D), Q203.7D (D), Q203.8D (D), Q203.9D (D), R206.P2 (2), U4.P5 (SNS), U5.3 (-IN)
CHRG_AOUT: R40.P2 (2), R44.P2 (2), U4.P11 (AOUT)
CHRG_CURRENT: C44.P1 (1), R60.P2 (2), R70.P2 (2), TP7.P1; also elsewhere on the board
CHRG_EN: TP5.P1, U4.P9 (EN)
CHRG_FB: R53.P2 (2), R56.P1 (1), U4.P2 (FB)
CHRG_FLT: U4.P8 (_FLT); also elsewhere on the board
CHRG_SENSE: R35.P1 (1), R36.P2 (2), U4.P12 (IN+); also elsewhere on the board
CHRG_SHDN: R44.P1 (1), R47.P2 (2), R51.P1 (1), U4.P7 (_SHDN); also elsewhere on the board
GND: C13.P2 (2), C14.2, C15.2, C16.2, C17.2, C18.2, C19.P2 (2), C20.2, C21.2, C22.2, C23.P2 (2), C24.2, C25.2, C26.2, C35.2, C40.P2 (2), C43.2, C44.P2 (2), C46.P2 (2), C48.2, C52.P2 (2), C67.P2 (2), C68.P2 (2), C69.P2 (2), C70.P2 (2), C72.P2 (2), C73.P2 (2), C74.P2 (2), C75.P2 (2), C76.P2 (2), C77.P2 (2), C78.2, C79.P2 (2), C82.P2 (2), D3.A, D9.A, D18.A, D24.A, D200.1 (A), D201.1 (A), D202.1 (A), D210.1 (A), JP1.P1, JP4.P1, JP6.P1, JP11.P1, JP13.P1, JP16.11, JP20.P1, Q1.2 (S), R10.P1 (1), R15.P1 (1), R16.P1 (1), R18.P1 (1), R24.P1 (1), R36.P1 (1), R47.P1 (1), R48.P1 (1), R53.P1 (1), R70.P1 (1), R82.P2 (2), R130.P1 (1), R131.P1 (1), R133.P1 (1), U1.P10 (GND), U1.TAB (GND), U2.5 (GND), U4.P10 (GND), U4.TAB (GND), U5.5 (GND), U8.2 (GND), U9.8 (GND), U9.17 (GND); also elsewhere on the board
LOAD: C24.1, C25.1, D9.C, D207.3 (C), JP7.P1, Q2.1S (S), Q2.2S (S), Q2.3S (S), Q206.1S (S), Q206.2S (S), Q206.3S (S), Q210.1S (S), Q210.2S (S), Q210.3S (S), Q213.1S (S), Q213.2S (S), Q213.3S (S), R9.P2 (2), R85.P2 (2), U1.P3 (OUT)
LOAD_AOUT: R8.P2 (2), R23.P2 (2), U1.P11 (AOUT)
LOAD_EN: TP3.P1, U1.P9 (EN)
LOAD_FB: R9.P1 (1), R10.P2 (2), TP1.P1, U1.P2 (FB)
LOAD_FLT: U1.P8 (_FLT); also elsewhere on the board
LOAD_SHDN: R14.P1 (1), R15.P2 (2), R23.P1 (1), U1.P7 (_SHDN); also elsewhere on the board
unnamed: C80.P2 (2), L4.P1 (1), U9.9 (SW)
unnamed: R60.P1 (1), U5.7 (OUT)
unnamed: R131.P2 (2), R134.P1 (1), U9.4 (EN/UVLO)
unnamed: R132.P2 (2), U9.14 (PG)
unnamed: R127.P2 (2), R128.P2 (2), U8.3 (SHDN)
unnamed: C40.P1 (1), U4.P1 (TMR)
unnamed: Q207.4G (G), Q208.4G (G), R37.P2 (2)
unnamed: R37.P1 (1), R40.P1 (1), U4.P4 (GATE)
unnamed: Q1.1 (G), R82.P1 (1), R86.P2 (2)
unnamed: C13.P1 (1), U1.P1 (TMR)
unnamed: D207.1 (A), Q2.4G (G), R81.P2 (2), R85.P1 (1)
unnamed: C80.P1 (1), U9.11 (BOOST)
unnamed: Q1.3 (D), R81.P1 (1)
unnamed: TP6.P1, U5.6 (REF)
unnamed: R130.P2 (2), U9.16 (RT)
unnamed: R17.P1 (1), U2.7 (OUT)
unnamed: Q206.4G (G), Q210.4G (G), Q213.4G (G), R7.P1 (1)
unnamed: TP2.P1, U2.6 (REF)
unnamed: R7.P2 (2), R8.P1 (1), U1.P4 (GATE)
unnamed: TP8.P1, U5.8 (SHDN)
unnamed: TP4.P1, U2.8 (SHDN)
unnamed: D13.1 (A), Q202.4G (G), Q203.4G (G), R48.P2 (2)
unnamed: C74.P1 (1), R129.P1 (1), R133.P2 (2), U9.1 (FB/VOUT), U9.2 (FB/VOUT)
unnamed: D6.1 (A), Q215.4G (G), Q216.4G (G), Q217.4G (G), Q218.4G (G), R20.P1 (1), R24.P2 (2)
unnamed: C81.P2 (2), U8.4 (C-)
unnamed: C81.P1 (1), U8.6 (C+)
VBATT: C16.1, C17.1, C18.1, C20.1, C21.1, C22.1, C23.P1 (1), D6.3 (C), D210.3 (C), Q215.1S (S), Q215.2S (S), Q215.3S (S), Q216.1S (S), Q216.2S (S), Q216.3S (S), Q217.1S (S), Q217.2S (S), Q217.3S (S), Q218.1S (S), Q218.2S (S), Q218.3S (S), R14.P2 (2), R26.P2 (2), R215.P1 (1), U1.P6 (VCC), U2.2 (+IN)
VBATT_RAW: C14.1, C15.1, D3.C, JP5.P1, Q215.5D (D), Q215.6D (D), Q215.7D (D), Q215.8D (D), Q215.9D (D), Q216.5D (D), Q216.6D (D), Q216.7D (D), Q216.8D (D), Q216.9D (D), Q217.5D (D), Q217.6D (D), Q217.7D (D), Q217.8D (D), Q217.9D (D), Q218.5D (D), Q218.6D (D), Q218.7D (D), Q218.8D (D), Q218.9D (D), R20.P2 (2)
VBATT_SENSE: R16.P2 (2), R26.P1 (1), U1.P12 (IN+); also elsewhere on the board
VBATT_SNS: C26.1, C35.1, C78.1, C79.P1 (1), D201.3 (C), Q206.5D (D), Q206.6D (D), Q206.7D (D), Q206.8D (D), Q206.9D (D), Q207.1S (S), Q207.2S (S), Q207.3S (S), Q208.1S (S), Q208.2S (S), Q208.3S (S), Q210.5D (D), Q210.6D (D), Q210.7D (D), Q210.8D (D), Q210.9D (D), Q213.5D (D), Q213.6D (D), Q213.7D (D), Q213.8D (D), Q213.9D (D), R56.P2 (2), R134.P2 (2), R215.P2 (2), U1.P5 (SNS), U2.3 (-IN), U4.P3 (OUT), U9.6 (VIN)
VCHARGER_SENSE: D13.3 (C), Q202.1S (S), Q202.2S (S), Q202.3S (S), Q203.1S (S), Q203.2S (S), Q203.3S (S), Q207.5D (D), Q207.6D (D), Q207.7D (D), Q207.8D (D), Q207.9D (D), Q208.5D (D), Q208.6D (D), Q208.7D (D), Q208.8D (D), Q208.9D (D)

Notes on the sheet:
Battery Power Input
3V3 Buck Converter
Charge load switch
Load Power Switch
Aux Power Switch

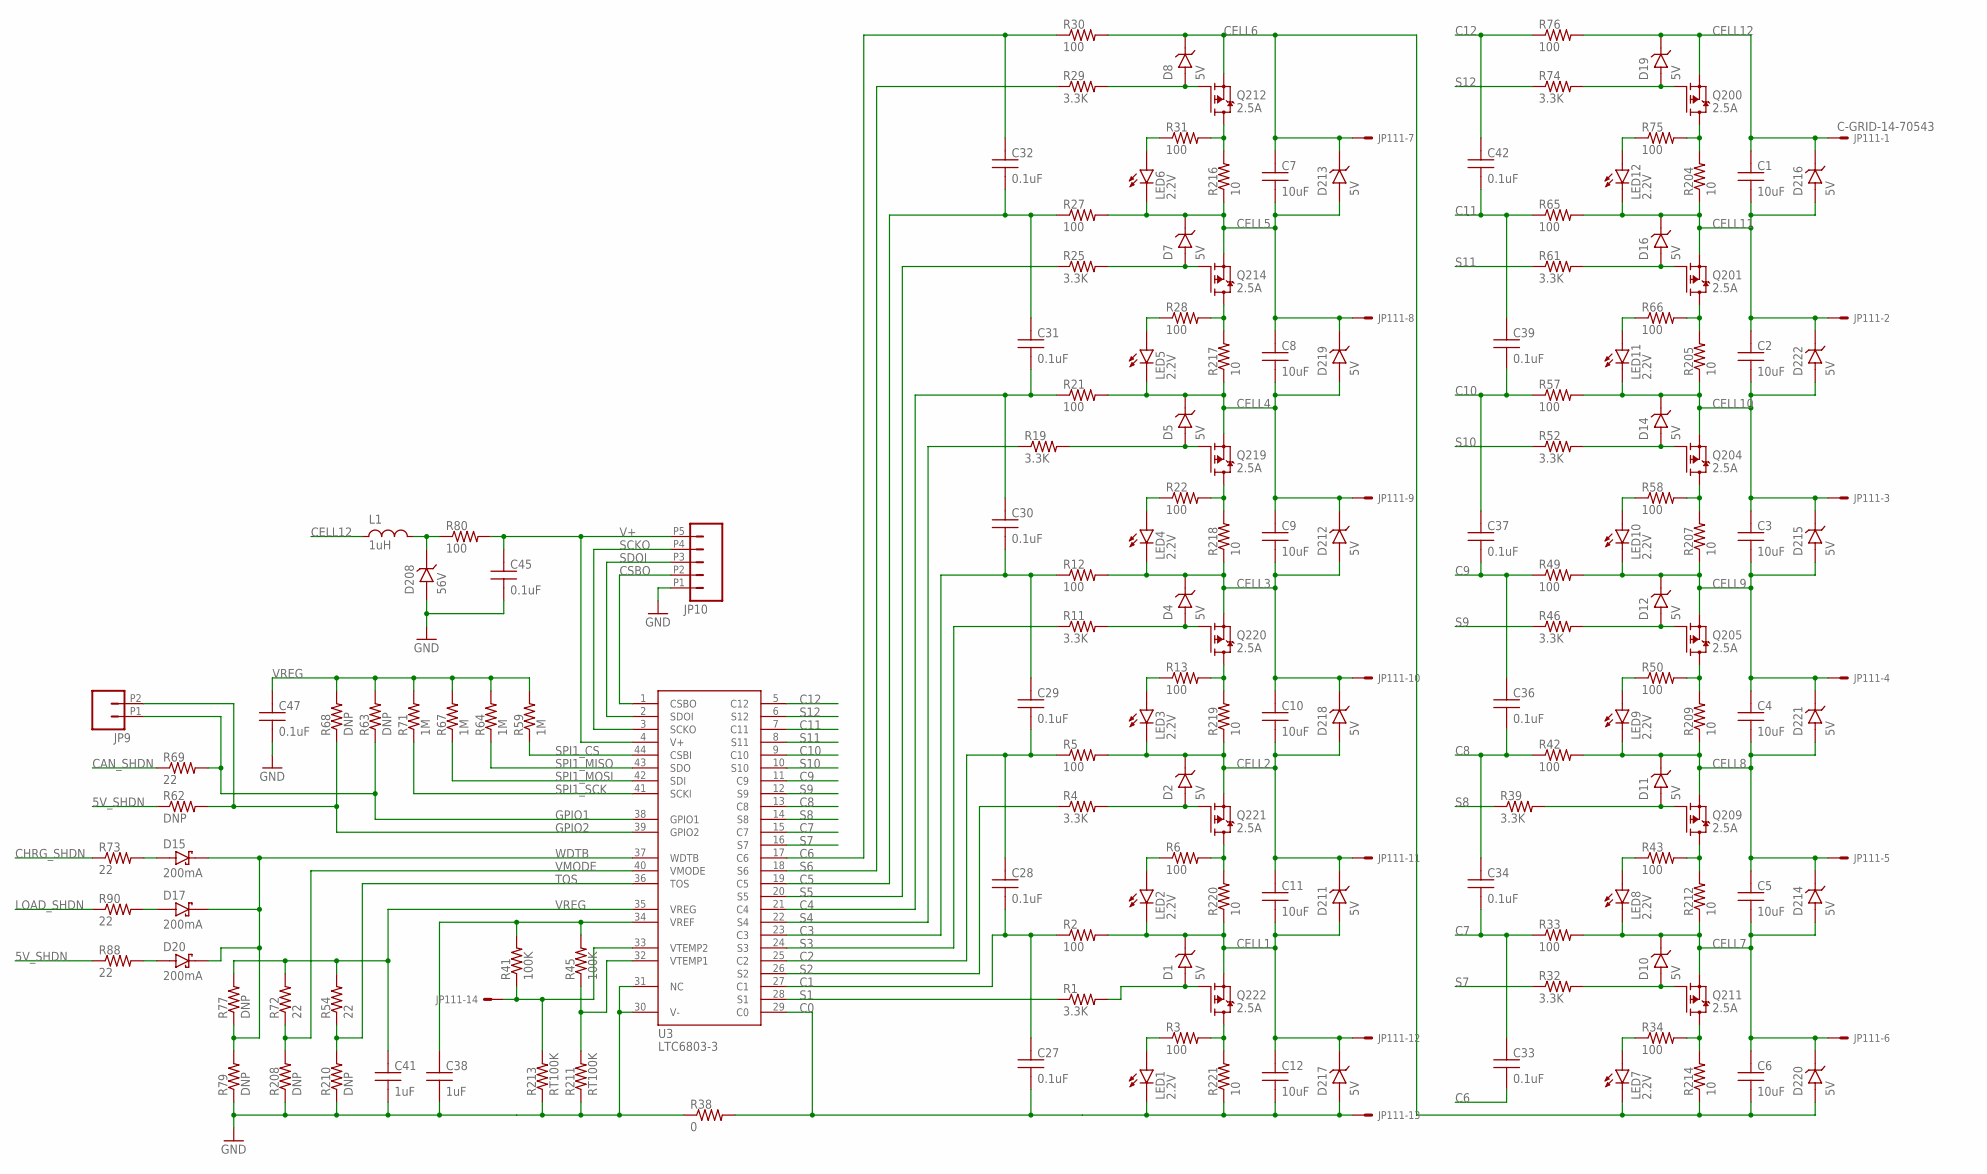
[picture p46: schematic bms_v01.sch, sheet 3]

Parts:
C1, C2, C3, C4, C5, C6, C7, C8, C9, C10, C11, C12: 10uF; 1206_SILK
C27, C28, C29, C30, C31, C32, C33, C34, C36, C37, C39, C42, C45, C47: 0.1uF; 0603_SILK
C38, C41: 1uF; 0603_SILK
D1, D2, D4, D5, D7, D8, D10, D11, D12, D14, D16, D19, D211, D212, D213, D214, D215, D216, D217, D218, D219, D220, D221, D222: 5V; SOT23
D15, D17, D20: 200mA; SOT23
D208: 56V; SOT23
JP9: HEADER-2PIN0.05IN; HEADER-SMALL-2PIN00.05IN
JP10: HEADER-5PIN2MM; HEADER_2MM_5PIN
JP111: C-GRID-14-70543; 70543-14
L1: 1uH; 0603_SILK
LED1, LED2, LED3, LED4, LED5, LED6, LED7, LED8, LED9, LED10, LED11, LED12: 2.2V; LED_0603
Q200, Q201, Q204, Q205, Q209, Q211, Q212, Q214, Q219, Q220, Q221, Q222: 2.5A; SOT23
R1, R4, R11, R19, R25, R29, R32, R39, R46, R52, R61, R74: 3.3K; 0603_SILK
R2, R3, R5, R6, R12, R13, R21, R22, R27, R28, R30, R31, R33, R34, R42, R43, R49, R50, R57, R58, R65, R66, R75, R76, R80: 100; 0603_SILK
R38: 0; 0603_SILK
R41, R45: 100K; 0603_SILK
R54, R69, R72, R73, R88, R90: 22; 0603_SILK
R59, R64, R67, R71: 1M; 0603_SILK
R62, R63, R68, R77, R79, R208, R210: DNP; 0603_SILK
R204, R205, R207, R209, R212, R214, R216, R217, R218, R219, R220, R221: 10; 2512_SILK
R211, R213: RT100K; 0603_SILK
U3: LTC6803-3; SSOP44

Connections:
5V_SHDN: R62.P1 (1), R88.P1 (1); also elsewhere on the board
C0: C12.P2 (2), C27.P2 (2), D217.1 (A), JP111.13, LED1.2 (C), R38.P2 (2), R221.1, U3.29 (C0)
C1: C27.P1 (1), C28.P2 (2), R2.P1 (1), U3.27 (C1)
C2: C28.P1 (1), C29.P2 (2), R5.P1 (1), U3.25 (C2)
C3: C29.P1 (1), C30.P2 (2), R12.P1 (1), U3.23 (C3)
C4: C30.P1 (1), C31.P2 (2), R21.P1 (1), U3.21 (C4)
C5: C31.P1 (1), C32.P2 (2), R27.P1 (1), U3.19 (C5)
C6: C32.P1 (1), C33.P2 (2), R30.P1 (1), U3.17 (C6)
C7: C33.P1 (1), C34.P2 (2), R33.P1 (1), U3.15 (C7)
C8: C34.P1 (1), C36.P2 (2), R42.P1 (1), U3.13 (C8)
C9: C36.P1 (1), C37.P2 (2), R49.P1 (1), U3.11 (C9)
C10: C37.P1 (1), C39.P2 (2), R57.P1 (1), U3.9 (C10)
C11: C39.P1 (1), C42.P2 (2), R65.P1 (1), U3.7 (C11)
C12: C42.P1 (1), R76.P1 (1), U3.5 (C12)
CAN_SHDN: R69.P1 (1); also elsewhere on the board
CELL1: C11.P2 (2), C12.P1 (1), D1.3 (C), D211.1 (A), D217.3 (C), JP111.12, LED2.2 (C), Q222.2 (S), R2.P2 (2), R220.1
CELL2: C10.P2 (2), C11.P1 (1), D2.3 (C), D211.3 (C), D218.1 (A), JP111.11, LED3.2 (C), Q221.2 (S), R5.P2 (2), R219.1
CELL3: C9.P2 (2), C10.P1 (1), D4.3 (C), D212.1 (A), D218.3 (C), JP111.10, LED4.2 (C), Q220.2 (S), R12.P2 (2), R218.1
CELL4: C8.P2 (2), C9.P1 (1), D5.3 (C), D212.3 (C), D219.1 (A), JP111.9, LED5.2 (C), Q219.2 (S), R21.P2 (2), R217.1
CELL5: C7.P2 (2), C8.P1 (1), D7.3 (C), D213.1 (A), D219.3 (C), JP111.8, LED6.2 (C), Q214.2 (S), R27.P2 (2), R216.1
CELL6: C6.P2 (2), C7.P1 (1), D8.3 (C), D213.3 (C), D220.1 (A), JP111.7, LED7.2 (C), Q212.2 (S), R30.P2 (2), R214.1
CELL7: C5.P2 (2), C6.P1 (1), D10.3 (C), D214.1 (A), D220.3 (C), JP111.6, LED8.2 (C), Q211.2 (S), R33.P2 (2), R212.1
CELL8: C4.P2 (2), C5.P1 (1), D11.3 (C), D214.3 (C), D221.1 (A), JP111.5, LED9.2 (C), Q209.2 (S), R42.P2 (2), R209.1
CELL9: C3.P2 (2), C4.P1 (1), D12.3 (C), D215.1 (A), D221.3 (C), JP111.4, LED10.2 (C), Q205.2 (S), R49.P2 (2), R207.1
CELL10: C2.P2 (2), C3.P1 (1), D14.3 (C), D215.3 (C), D222.1 (A), JP111.3, LED11.2 (C), Q204.2 (S), R57.P2 (2), R205.1
CELL11: C1.P2 (2), C2.P1 (1), D16.3 (C), D216.1 (A), D222.3 (C), JP111.2, LED12.2 (C), Q201.2 (S), R65.P2 (2), R204.1
CELL12: C1.P1 (1), D19.3 (C), D216.3 (C), JP111.1, L1.P1 (1), Q200.2 (S), R76.P2 (2)
CHRG_SHDN: R73.P1 (1); also elsewhere on the board
CSBO: JP10.P2, U3.1 (CSBO)
GND: C38.P2 (2), C41.P2 (2), C45.P2 (2), C47.P2 (2), D208.1 (A), JP10.P1, R38.P1 (1), R79.P1 (1), R208.P1 (1), R210.P1 (1), R211.P1 (1), R213.P1 (1), U3.30 (V-), U3.31 (NC); also elsewhere on the board
GPIO1: JP9.P1, R63.P1 (1), R69.P2 (2), U3.38 (GPIO1)
GPIO2: JP9.P2, R62.P2 (2), R68.P1 (1), U3.39 (GPIO2)
LOAD_SHDN: R90.P1 (1); also elsewhere on the board
unnamed: R45.P1 (1), R211.P2 (2), U3.32 (VTEMP1)
unnamed: D20.1 (A), R88.P2 (2)
unnamed: JP111.14, R41.P1 (1), R213.P2 (2), U3.33 (VTEMP2)
unnamed: C38.P1 (1), R41.P2 (2), R45.P2 (2), U3.34 (VREF)
unnamed: D1.1 (A), Q222.1 (G), R1.P2 (2)
unnamed: Q222.3 (D), R3.P2 (2), R221.2
unnamed: D2.1 (A), Q221.1 (G), R4.P2 (2)
unnamed: Q221.3 (D), R6.P2 (2), R220.2
unnamed: D4.1 (A), Q220.1 (G), R11.P2 (2)
unnamed: Q220.3 (D), R13.P2 (2), R219.2
unnamed: D5.1 (A), Q219.1 (G), R19.P2 (2)
unnamed: Q219.3 (D), R22.P2 (2), R218.2
unnamed: D7.1 (A), Q214.1 (G), R25.P2 (2)
unnamed: Q214.3 (D), R28.P2 (2), R217.2
unnamed: D8.1 (A), Q212.1 (G), R29.P2 (2)
unnamed: Q212.3 (D), R31.P2 (2), R216.2
unnamed: D10.1 (A), Q211.1 (G), R32.P2 (2)
unnamed: Q211.3 (D), R34.P2 (2), R214.2
unnamed: D11.1 (A), Q209.1 (G), R39.P2 (2)
unnamed: Q209.3 (D), R43.P2 (2), R212.2
unnamed: D12.1 (A), Q205.1 (G), R46.P2 (2)
unnamed: Q205.3 (D), R50.P2 (2), R209.2
unnamed: D14.1 (A), Q204.1 (G), R52.P2 (2)
unnamed: Q204.3 (D), R58.P2 (2), R207.2
unnamed: D16.1 (A), Q201.1 (G), R61.P2 (2)
unnamed: Q201.3 (D), R66.P2 (2), R205.2
unnamed: D19.1 (A), Q200.1 (G), R74.P2 (2)
unnamed: Q200.3 (D), R75.P2 (2), R204.2
unnamed: D208.3 (C), L1.P2 (2), R80.P1 (1)
unnamed: D15.1 (A), R73.P2 (2)
unnamed: D17.1 (A), R90.P2 (2)
unnamed: LED6.1 (A), R31.P1 (1)
unnamed: LED5.1 (A), R28.P1 (1)
unnamed: LED4.1 (A), R22.P1 (1)
unnamed: LED3.1 (A), R13.P1 (1)
unnamed: LED2.1 (A), R6.P1 (1)
unnamed: LED1.1 (A), R3.P1 (1)
unnamed: LED7.1 (A), R34.P1 (1)
unnamed: LED8.1 (A), R43.P1 (1)
unnamed: LED9.1 (A), R50.P1 (1)
unnamed: LED10.1 (A), R58.P1 (1)
unnamed: LED11.1 (A), R66.P1 (1)
unnamed: LED12.1 (A), R75.P1 (1)
S1: R1.P1 (1), U3.28 (S1)
S2: R4.P1 (1), U3.26 (S2)
S3: R11.P1 (1), U3.24 (S3)
S4: R19.P1 (1), U3.22 (S4)
S5: R25.P1 (1), U3.20 (S5)
S6: R29.P1 (1), U3.18 (S6)
S7: R32.P1 (1), U3.16 (S7)
S8: R39.P1 (1), U3.14 (S8)
S9: R46.P1 (1), U3.12 (S9)
S10: R52.P1 (1), U3.10 (S10)
S11: R61.P1 (1), U3.8 (S11)
S12: R74.P1 (1), U3.6 (S12)
SCKO: JP10.P4, U3.3 (SCKO)
SDOI: JP10.P3, U3.2 (SDOI)
SPI1_CS: R59.P1 (1), U3.44 (CSBI); also elsewhere on the board
SPI1_MISO: R64.P1 (1), U3.43 (SDO); also elsewhere on the board
SPI1_MOSI: R67.P1 (1), U3.42 (SDI); also elsewhere on the board
SPI1_SCK: R71.P1 (1), U3.41 (SCKI); also elsewhere on the board
TOS: R54.P1 (1), R210.P2 (2), U3.36 (TOS)
V+: C45.P1 (1), JP10.P5, R80.P2 (2), U3.4 (V+)
VMODE: R72.P1 (1), R208.P2 (2), U3.40 (VMODE)
VREG: C41.P1 (1), C47.P1 (1), R54.P2 (2), R59.P2 (2), R63.P2 (2), R64.P2 (2), R67.P2 (2), R68.P2 (2), R71.P2 (2), R72.P2 (2), R77.P2 (2), U3.35 (VREG)
WDTB: D15.3 (C), D17.3 (C), D20.3 (C), R77.P1 (1), R79.P2 (2), U3.37 (WDTB)

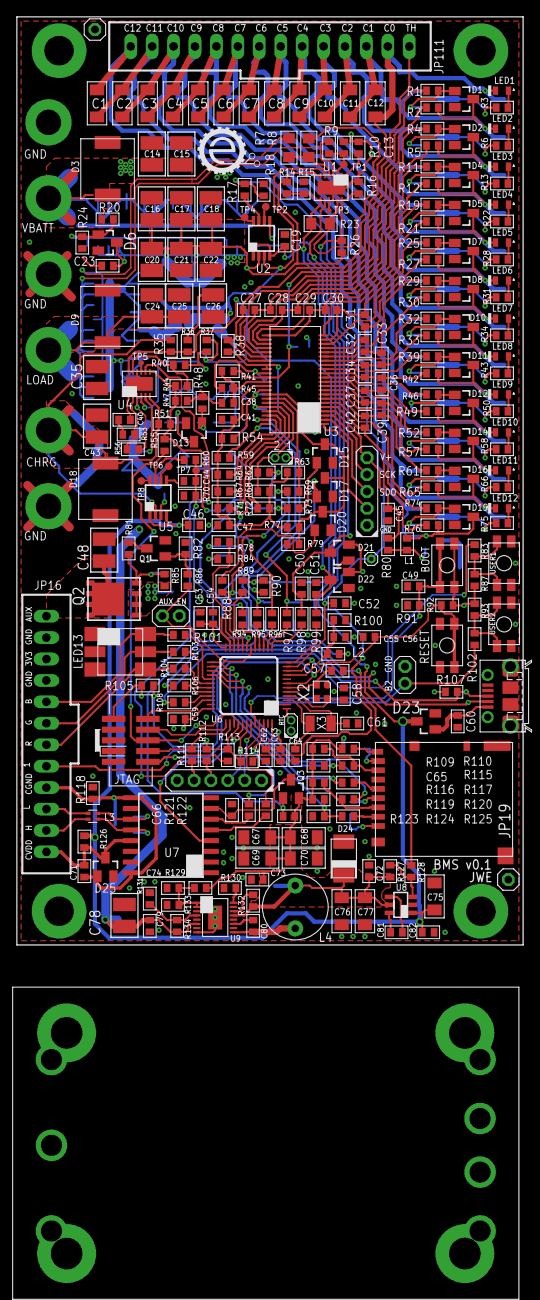
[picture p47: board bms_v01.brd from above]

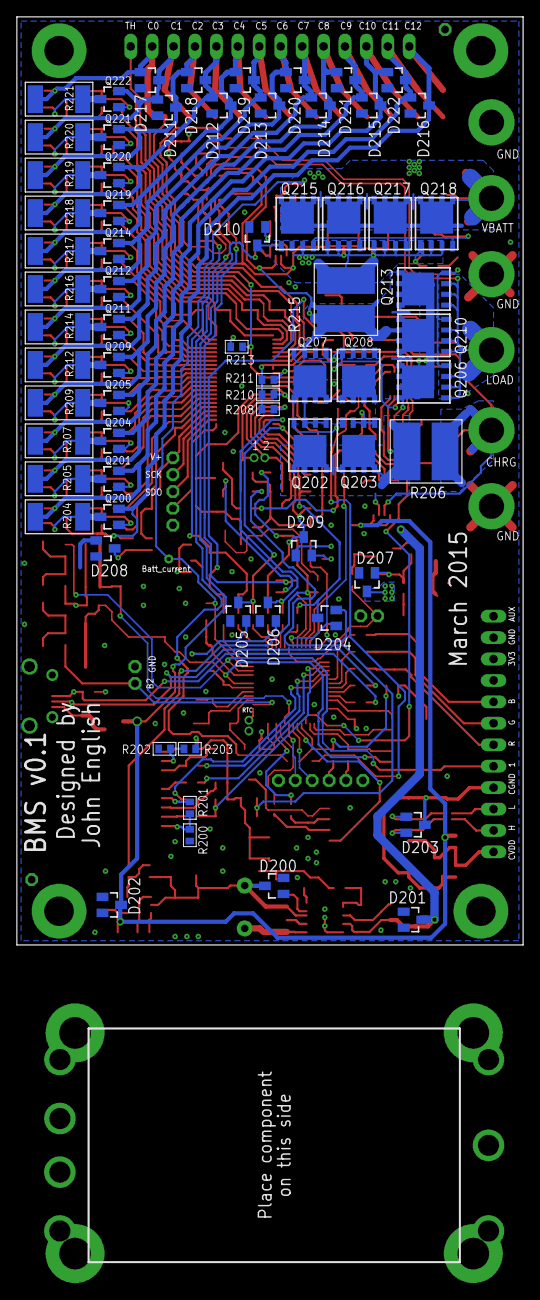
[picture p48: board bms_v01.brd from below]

Board: 4 copper layers, 60.0 x 110.0 mm, 379 parts (68 on the bottom side), 211 nets.

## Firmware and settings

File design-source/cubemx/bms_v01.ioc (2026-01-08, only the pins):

Mcu.UserName=STM32F303CCTx
PA0.GPIO_Label=Button 1
PA0.Signal=SYS_WKUP1
PA1.GPIO_Label=Battery Current
PA1.Signal=COMP1_INP
PA10.GPIO_Label=LED_R
PA10.Signal=GPIO_Output
PA11.Signal=USB_DM
PA12.Signal=USB_DP
PA13.Signal=SYS_JTMS-SWDIO
PA14.Signal=SYS_JTCK-SWCLK
PA15.GPIO_Label=Interlock
PA15.Signal=SYS_JTDI
PA2.GPIO_Label=Chage Current
PA2.Signal=ADC1_IN3
PA3.GPIO_Label=Battery Voltage
PA3.Signal=COMP2_INP
PA4.Signal=SPI1_NSS
PA5.Signal=SPI1_SCK
PA6.Signal=SPI1_MISO
PA7.Signal=SPI1_MOSI
PA8.GPIO_Label=LED_B
PA8.Signal=GPIO_Output
PA9.GPIO_Label=LED_G
PA9.Signal=GPIO_Output
PB0.GPIO_Label=Discharge Voltage
PB0.Signal=COMP4_INP
PB1.GPIO_Label=Charge Enable
PB1.Signal=GPIO_Output
PB10.GPIO_Label=3V3 Power good
PB10.Signal=GPIO_Input
PB11.GPIO_Label=Discharge voltage
PB11.Signal=COMP6_INP
PB12.Signal=SPI2_NSS
PB13.Signal=SPI2_SCK
PB14.Signal=SPI2_MISO
PB15.Signal=SPI2_MOSI
PB2.GPIO_Label=Discharge Enable
PB2.Signal=GPIO_Output
PB3.Signal=SYS_JTDO-TRACESWO
PB4.GPIO_Label=Fault
PB4.Signal=SYS_NJTRST
PB5.GPIO_Label=CAN_PWR
PB5.Signal=GPIO_Input
PB6.Signal=USART1_TX
PB7.Signal=USART1_RX
PB8.Signal=CAN_RX
PB9.Signal=CAN_TX
PC13.GPIO_Label=Button 2
PC13.Signal=RTC_OUT_ALARM
PC14-OSC32_IN.Signal=RCC_OSC32_IN
PC15-OSC32_OUT.Signal=RCC_OSC32_OUT
PF0-OSC_IN.Signal=RCC_OSC_IN
PF1-OSC_OUT.Signal=RCC_OSC_OUT

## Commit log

2026-01-08 Reorganized Spring 2015 BMS project for initial open-source hardware release.
    [18650.SLDPRT, 2100-base_internal_tub.SLDPRT, 2100-lid_internal_tub.SLDPRT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]
2026-01-08 Add PCB photos to README
2026-01-08 Update README.md
    Made readme format more consistent with chibi-ecen-bldc sister project

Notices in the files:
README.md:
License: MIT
